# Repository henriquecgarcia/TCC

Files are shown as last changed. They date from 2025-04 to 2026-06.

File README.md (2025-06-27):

# Autonomous Car for Delivery
Final Course Project fo Computer Science at UNIFESP (Federal University of São Paulo).

## Project Details:
**Author**: Henrique Campanha Garcia
**Professor**: Dr. André Marcorin de Oliveira
**Course**: Computer Science
**University**: Federal University of São Paulo (UNIFESP)

## Description
This project is an autonomous car (drone) with the porpose of transporting packages from one place to another using a known map. The drone will be fully autonomous, using an ESP32, a motor driver, 4 motors, a battery and some other sensors for minor systems. To operate the drone, you will connect on it's IP connection, select wherever you want it to go, put the package on top of the drone and press for it to go.

The drone also has some other sensors that will help on it's navigation and controling the location where it is and preventing it from colliding with things on it's way.

### How to use:
To use this project, you need to have the following libraries installed:
- `WiFi`
- `ESPAsyncWebServer` (From me-do-dev)
- `SPIFFS`
- `VL53L0x` (From Adafruit)
- `MPU6050` (From Adafruit)

## Components:
- ESP32
- Motor Driver
- 4 DC Motors (3-6v DC Motor)
- 2 Encoder (Q2-E2)
- Battery
- 1 VL53L0x
- 1 MPU6050 Acelerometer & Gyroscope

### ESP32
The ESP32 used is the ESP32 DOIT DEVKIT V1, which has a ESP-WROOM-32 module, which has a dual core processor, 4MB of flash memory, 520KB of SRAM, and a lot of other features.

### Motor Driver & DC Motors
The motor driver used is the L298N, which is a dual H-Bridge motor driver, which can control 2 motors at the same time, and can control the speed of the motors.
> Obs: In each side of the car, there are 2 motors, meaning the the Motor Driver is connected to 4 motors at once (2 in each side).

The motors used are 3-6v DC Motors, which are small and lightweight, and can be controlled by the motor driver to move the car forward, backwards and turn. In the bought motors, they already had a reductor, which allows the car to move at a constant speed and to have more torque, allowing it to carry a package on top of it.

### Battery
The battery used is a 7.4v LiPo battery, which is lightweight and has a high capacity, allowing the car to move for a long time without needing to be recharged.
> Obs: The battery is connected to the motor driver, which allows the car to move. And the Motor Driver sends 5v to the ESP32, but since it only has 3.3v logic, the ESP32 converts the 5v to 3.3v using the vin pin.

### Encoders E2-Q2
The encoders are mounted on the forward wheels and counting each change on the reflective sensors, allowing the ESP32 to count the number of "changes" on the sensors, therefore, knowing that the used reference wheel there is 10 teeth, and the actual wheel has 65 mm of diameter, we can calculate the distance traveled by the car in a second by using the formula:
```
Distance = ((Number of changes) / 2 * 65mm) / (10 * 2)
RPM = (Number of changes / interval) * 60
```
> The division by 2 is because the encoder has 2 channels, and we are only using one of them, so we need to divide the number of changes by 2 to get the actual number of changes on the wheel. The division by 10 * 2 (20) is because the encoder has 10 teeth, and we are using the number of changes to calculate the distance traveled by the car in a second, so we need to divide the number of changes by 20 to get the actual distance traveled by the car in a second.
> Obs: The interval used is of 100ms, meaning that the car will calculate the distance traveled by the car every 100ms, and the speed of the car will be calculated every second.

### VL53L0x
Using the time-of-flight sensor, the VL53L0x can measure distances up to 3 meters with high accuracy. It uses a laser to measure the time it takes for the light to bounce back from an object, allowing it to calculate the distance.
> In the project, the sensor is mounted infront, facing forward to the front, to avoid any collision while on the path to the destination.

### MPU6050 Acelerometer & Gyroscope
The MPU6050 is a 6-axis motion tracking device that combines a 3-axis gyroscope and a 3-axis accelerometer on a single chip. It can be used to measure the orientation and motion of the car, allowing for more advanced control and navigation.
The MPU6050 is connected to the ESP32 via I2C, and it is used to measure the orientation and motion of the car, allowing for more advanced control and navigation. The MPU6050 can be used to detect the direction of the car, and to control the speed of the motors, so the car can go straight and not turn while going forward/backwards.
> Obs: The MPU6050 also has a temperature sensor, but it is not used in this project.

---

## How it works:
**Some awsome remarks of the project will be here, but I don't want to write them now, so I will write them later.**

## Pinout
The pinout used in this project is the following:
- Motor Driver:
	- ENA: 32
	- INA1: 12
	- INA2: 13
	- INB1: 26
	- INB2: 25
	- ENB: 33
- Encoders:
	- Front-Right:
		- Channel A: 4
		- Channel B: 15
	- Front-Left:
		- Channel A: 17
		- Channel B: 16
- MPU6050 & VL53L0x:
	- Via I2C.
	- SDA: 21
	- SCL: 22

## Final remarks:
This project was started in the class of Internet of Things (IoT) at the Federal University of São Paulo (UNIFESP), by Henrique Campanha Garcia, under the supervision of Professor Dr. André Marcorin de Oliveira. The project was updated and made to be fully autonomous and to be able to move in a path that it would not deviate from the pathm and to change the object avoidance system to use a time-of-flight sensor instead of an ultrasonic sensor. The project had to have a few bunch of changes to work with the new components, have a PID controler to control the speed of the motors. Some of the motor control was maintained from the previous project, but the new components and the new control system made it necessary to change a lot of the code.
The project has a plan to scan the environment and to create a map of the environment, so the car can navigate through the environment and avoid obstacles. Ideally, when fully autonomous, the vehicle would save the map using the SPIFFS filesystem, and then use the map to navigate through the environment, avoiding "static" obstacles, like walls and furniture, but also avoiding "dynamic" obstacles, like people and animals.
The way that it was setup, the car uses the encoders and the MPU6050 to control the direction of the car, avoiding that the car turns while going forward or backwards, and using the VL53L0x to avoid collisions with objects in front of the car, stopping the car when it detects an object closer than 10cm.

---
---
# Old stuff
This is a project to build a remote controlled car using an ESP32, a motor driver, 4 motors, a battery and a remote control. The remote control used is a normal gamepad controller, but we will only be using the triggers and the left joystick, where the right trigger will be used to move the car forward, the left trigger will be used to move the car backwards, and the left joystick will be used to steer the car, though the car will only be able to do one of these actions at a time.

The car has also some other components, like a LDR to detect light, DHT11 to detect temperature and humidity, and a ultrasonic sensor to detect distance ahead of the car. It will send this data to a MQTT broker, so it can be accessed from anywhere.

The MQTT broker used is the Flespi MQTT broker, and when a button is pressed on the MQTT client, a LED on the car will light change simbolizing that there was a light turned on inside the greenhouse has been turned on or off.

## How to use
To use this project, you will need to have the following libraries installed:
- `WiFi`
- `PubSubClient`
- `Bluepad32` (Used for the controller)

# Components
- ESP32
- Motor Driver
- 4 CC Motors
- Battery
- Remote Control
- LDR
- DHT11
- 2 LEDs
- Ultrasonic Sensor (HC-SR04)

## ESP32
The ESP32 used is the ESP32 DOIT DEVKIT V1, which has a ESP-WROOM-32 module, which has a dual core processor, 4MB of flash memory, 520KB of SRAM, and a lot of other features.

## Motor Driver
The motor driver used is the L298N, which is a dual H-Bridge motor driver, which can control 2 motors at the same time, and can control the speed of the motors.
> Obs: In this project, the motor driver and the motors were already built in a car chassis, so I don't have the exact model of the motors used.

> Obs2: In each side of the car, there are 4 motors, meaning the the Motor Driver is connected to 4 motors at once (2 in each side).

## Battery
>> idk, need to check

## Remote Control
>> idk, need to check

## LDR
The LDR used is a simple LDR, which is used to detect light. When the light is on, the resistance of the LDR decreases, and when the light is off, the resistance increases.

## DHT11
The DHT11 is a sensor that can detect temperature and humidity. It is a simple sensor, and it is not very accurate, but it is good enough for this project.

## Ultrasonic Sensor
The ultrasonic sensor used is the HC-SR04, which can detect distance ahead of the car. It works by sending a sound wave, and then waiting for the sound wave to return. The time it takes for the sound wave to return is used to calculate the distance.
> Formula for calculating the distance: `distance = (time * speed of sound) / 2`

## MQTT
The MQTT broker used is the Flespi MQTT broker, which is a free MQTT broker that can be used for testing purposes. It is a cloud based MQTT broker, and it is very easy to use.

---
# How it works
The ESP32 is the main component of the car, and it is responsible for controlling the car, and sending data to the MQTT broker.

The car can be controlled using the remote control, which is connected to the ESP32 via Bluepad32 (Bluetooth). On the controller, when it's pressed the right trigger, the car will move forward, when it's pressed the left trigger, the car will move backwards, and when the left joystick is moved, the car will turn.

While the car is moving, the LDR will detect the light, and the DHT11 will detect the temperature and humidity. Every 0.5 seconds, the ESP32 will send this data to the MQTT broker, so it can be accessed from anywhere.
> Reason for the time: So it does not overload the MQTT broker with data.

The ultrasonic sensor is used to detect distance ahead of the car, and when the distance is less than 10cm, the car will stop moving forward and will only allow the car to move backwards or turn.

Whenever the LDR detects low light, the ESP32 will send a message to the MQTT broker, and a LED on the car will light up. When the LDR detects high light, the ESP32 will send another message to the MQTT broker, and the LED will turn off.

On the MQTT viewer, there will be 2 main buttons, one to turn on or off the light inside the greenhouse, and another to turn on or off the light on the car. When the button to turn on or off the light inside the greenhouse is pressed, a LED added on the ESP32 protoboard will light up or turn off, simbolizing that the light inside the greenhouse has been turned on or off. Same thing happens when the button to turn on or off the light on the car is pressed.

## Pinout
The pinout used in this project is the following:
- Motor Driver:
	- ENA: not used
	- IN1: 25
	- IN2: 33
	- IN3: 32
	- IN4: 14
	- ENB: not used
- LDR: 34
- DHT11: 35
- Ultrasonic Sensor:
	- Trig: 26
	- Echo: 27
- LEDs:
	- Green: 2
	- Red: 4

## MQTT Topics
For MQTT topics, the following topics are used, all of them starting with `/Henrique/IoT/TF`:
- `/Henrique/IoT/TF/LDR`: Used to send the LDR data
- `/Henrique/IoT/TF/DHT/Temperature`: Used to send the temperature data
- `/Henrique/IoT/TF/DHT/Humidity`: Used to send the humidity data
- `/Henrique/IoT/TF/LED_CARRO`: Used to turn on or off the light on the car (The car will not publish to this topic, only subscribe)
- `/Henrique/IoT/TF/LED_ESTUFA`: Used to turn on or off the light inside the greenhouse

## MQTT Buttons
Within the MQTT, there are 2 buttons, one to turn on or off the light inside the greenhouse, and another to turn on or off the light on the car. Furthermore, there is a view section where the data from the LDR can be seen, and two sections where the temperature and humidity data can be seen.

Topics for the buttons:
- `/Henrique/IoT/TF/LED_CARRO`: Used to turn on or off the light on the car
- `/Henrique/IoT/TF/LED_ESTUFA`: Used to turn on or off the light inside the greenhouse

---

# Final remarks:
This project was made for the IoT class at the Federal University of São Paulo (UNIFESP), it was made by Henrique Campanha Garcia, using Visual Studio Code programming in Arduino, compiling using the Arduino IDE.

For the network connection, it was used my personal hotspot, witch has a meme ssid and password. The MQTT Broker used was the Flespi MQTT Broker and it's login will be changed after the project is finished.

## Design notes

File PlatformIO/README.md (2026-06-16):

# Proximos passos sugeridos:
> Fonte: Google Gemini Pro, gema customizada para o projeto e com conhecimento atualizado até março de 2026. (Commit anterior a este)

## 1. Sistema de Energia e Estabilidade
Segundo, o Professor:
> Item resolvido com a troca da corrente utilizada para alimentar os sensores do 3.3V do ESP32 para 5V, direto da Ponte H, nos testes iniciais funcionou bem, mas é importante monitorar a tensão da bateria durante o uso para garantir que não haja quedas que possam causar instabilidade ou resets do ESP32.
* Verificar a tensão da bateria sem carga e com carga.
* Verificar o uso de duas baterias (implementar um regulador de tensão).

Segundo a LLM:
* **Hardware:** Utilizar um circuito isolado: manter a potência bruta das baterias (ex: LiPo 7.4V) direto para a Ponte H e adicionar um regulador Step-Down (ex: LM2596) cravado em 5V exclusivo para o ESP32, evitando *brownouts*.
* **Firmware:** Implementar um divisor de tensão lido por um pino analógico (ADC) do ESP32 para monitorar a tensão em tempo real e criar uma trava de segurança (desligar motores se a bateria ficar muito baixa).
* **Texto Acadêmico:** Criar a seção "Dimensionamento Energético e Isolamento de Ruídos", incluindo o esquemático elétrico do divisor de tensão e do regulador, justificando a separação lógica/potência para estabilidade do sistema.

## 2. Controle das Rodas (PID) e Odometria
Segundo, o Professor:
* Colocar a roda boba (diminui a incerteza dos outros motores).
	- Eu: Uma ideia interessante, porém com a nova estabilidade após arrumar o item #1, pode ser que isso não seja mais necessário. Vale a pena testar o carrinho com as rodas atuais e verificar se a estabilidade é suficiente para o controle preciso.
* Tirar o PID, aplicar PWMs iguais, medir rotação na porta Serial e escolher motores parecidos.
	- Eu: Acho interessante para fazer os testes com os motores atuais, para entender o comportamento do sistema. Se os motores forem muito diferentes, pode ser necessário ajustar o PID ou considerar a substituição de um dos motores para garantir melhor desempenho.
* Regular os ganhos do PID e verificar o resultado final.
	- Eu: Acho que é importante fazer uma análise detalhada do comportamento do carrinho com os ajustes atuais, antes de decidir sobre a necessidade de uma roda boba ou substituição de motores. Se o controle PID estiver funcionando bem e o carrinho for estável, pode ser que não seja necessário fazer mudanças drásticas.
* Avaliar o uso de um Magnetômetro.
	- Eu: Realmente melhoraria a precisão da odometria, especialmente para correção de deriva. Vale a pena considerar a adição de um magnetômetro para complementar os dados do IMU e melhorar a navegação.

Segundo a LLM:
* **Hardware:** A instalação da roda boba (*caster wheel*) é mandatória para evitar o arraste do eixo traseiro, que gera um atrito não-linear imprevisível para o PID.
	- Eu: Mesma coisa que disse antes.
* **Firmware:** Criar um script temporário em malha aberta para aplicar degraus de PWM, exportar os logs da Serial para Excel/Python e aplicar um "fator de correção" no PWM base antes mesmo do PID atuar, compensando as assimetrias mecânicas.
	- Eu: Estudo mais que válido para entender o comportamento dos motores e ajustar o sistema, mas... Vamos ver...
* **Firmware (PID):** Garantir que o PID rode a uma frequência de amostragem perfeitamente cravada (ex: usando interrupção de hardware ou *Task* fixada em um *Core* pelo FreeRTOS a 50Hz) e habilitar a proteção *Anti-Windup*.
	- Eu: Não entendi nada disso... Verificar com Marcorin.
* **Sensores:** O magnetômetro deve ser usado como filtro complementar ao giroscópio (QMC5883L) para anular o *drift* (desvio acumulado) no eixo Z ao longo do tempo.
	- Eu: Mas o magnetômetro não seria um substituto para o giroscópio? | Verificar...
* **Texto Acadêmico:** Adicionar seção "Sintonia do Controlador PID", exibindo os gráficos do ensaio de malha aberta e o gráfico "antes vs depois" do controle em malha fechada demonstrando a redução do erro.
	- Eu: Soon (TM).

## 3. Comandos de Navegação de Alto Nível
Segundo, o Professor:
* Virar 90 graus a direção (direita).
	- Eu: Com os ajustes de estabilidade e controle, o carrinho deve ser capaz de realizar giros precisos. Ajustes devem ser feitos para garantir que o giro seja de apenas 90 graus, sem overshoot ou undershoot.
* Virar 90 graus para esquerda.
	- Eu: Com os ajustes de estabilidade e controle, o carrinho deve ser capaz de realizar giros precisos. Ajustes devem ser feitos para garantir que o giro seja de apenas 90 graus, sem overshoot ou undershoot.
* Andar X.
	- Eu: Odometria...
* Voltar X.
	- Eu: Odometria...

Segundo a LLM:
* **Firmware (Arquitetura):** Abstrair esses movimentos através de uma Máquina de Estados Finitos (FSM).
	- Eu: Tf this be?
* **Firmware (Rotação):** Criar a função `virar_angulo(float angulo)` que lê continuamente o integrador do giroscópio (eixo Z) e, ao atingir o alvo (ex: 90º), aplica um freio reverso momentâneo nos motores para zerar a inércia.
	- Eu: Potencia muito fraca pra precisar do freio reverso, mas a função é essencial para o controle de orientação.
* **Firmware (Translação):** Criar a função `andar_distancia(float cm)` que converte o raio da roda em "ticks de encoder por centímetro" e alimenta o *setpoint* do PID até o alvo ser alcançado.
	- Eu: Odometria... + Mapas e Trajetória...
* **Texto Acadêmico:** Desenhar a Máquina de Estados em LaTeX e apresentar as equações de Cinemática Direta do robô diferencial (relacionando a rotação das rodas com a velocidade linear do centro do robô).
	- Eu: Sure? Soon (TM).

## 4. Mapa, Trajetória e Localização
Segundo, o Professor:
* Ir do ponto A ao ponto B.
	- Eu: Fazer um algoritimo que controla o mapa, a trajetória e a localização do carrinho. Ideal: bitmaps para o mapa, A* para a trajetória e correção de localização com as faixas no chão.
* Fazer a localização simultânea no mapa em grid.
	- Eu: Fazer o algoritimo a cima + Odometria
* Usar faixas no chão?
	- Eu: Acho que perde um pouco da ideia de 100% autônomo, mas é uma solução prática e eficaz para o ambiente de teste. As faixas no chão funcionariam como "marcos" para correção de posição, permitindo que o carrinho se localize com mais precisão e compense os erros acumulados pela odometria.
* Chegar ao destino B com o mínimo erro de localização possível.
	- Eu: A combinação de um mapa em grid, o algoritmo A* para planejamento de trajetória.

Segundo a LLM:
* **Firmware (Algoritmo):** Implementar o mapa como uma matriz 2D embarcada (`int map[10][10]`) e utilizar o algoritmo A* (A-Star) para calcular a rota mais curta em grid.
	- Eu: A* é o algoritmo clássico para esse tipo de problema, mas... Será que o ESP32 aguenta? Vamos ver...
* **Hardware/Navegação:** A ideia do professor das faixas no chão é excelente. Instalar sensores reflexivos (como TCRT5000) apontados para o chão. Isso substitui um SLAM complexo e pesado por "Localização Topológica".
	- Eu: Avaliar... Mas como disse antes... Perde a ideia de ser 100% autônomo...
* **Firmware (Correção):** Toda vez que o robô cruza uma fita preta no chão, o software força a atualização da sua posição na matriz e "zera" a incerteza acumulada pela odometria morta (*dead reckoning*).
* **Texto Acadêmico:** Escrever um capítulo "Planejamento de Trajetória e Correção Odometrica", defendendo teoricamente por que a navegação puramente baseada nos encoders falha com o tempo (derrapagens/folgas) e justificando o uso de marcos fixos (faixas) para robustez no ambiente de teste.
	- Eu: Soon (TM).

## Navegação por células de 30 cm x 30 cm

Esta versão adiciona um comando de navegação discreta para o TCC: **"Vá X células para frente"**.
Cada célula representa **30 cm x 30 cm** no mundo real.

### Como funciona

O robô não tenta andar todas as células em um único movimento contínuo. Ele executa uma máquina de estados não bloqueante:

1. Registra a pose inicial da célula atual pelo `PoseEKF`.
2. Anda para frente até completar aproximadamente `0,30 m`.
3. Para os motores.
4. Aguarda uma pequena estabilização mecânica e de leitura.
5. Mede o erro de angulação em relação ao heading inicial do comando.
6. Corrige a angulação com uma curva curta, caso o erro seja maior que 2 graus.
7. Repete o ciclo até completar a quantidade solicitada.

Esse comportamento facilita validação experimental, logs por célula, futura integração com mapa ocupacional e controle mais estável para navegação em grade.

### Comandos aceitos

Via WebSocket do carro, é possível usar texto:

```text
vá 3 células para frente
va 3 celulas para frente
3 celulas para frente
```

Ou JSON:

```json
{"action":"forward_cells","cells":3}
```

Também é aceito:

```json
{"action":"go_cells_forward","cells":3}
```

### Telemetria adicionada

A telemetria passa a incluir o objeto `cell_nav`:

```json
{
  "cell_nav": {
    "state": "moving_cell",
    "active": true,
    "requested": 3,
    "completed": 1,
    "cell_size_cm": 50
  }
}
```

### Próximos passos sugeridos para o TCC

1. **Calibração experimental da célula de 30 cm**: medir o erro médio real em 10, 20 e 30 execuções e ajustar `CELL_TARGET_TOLERANCE_M`, PID dos motores e ruídos do EKF.
2. **Validação de odometria por encoder**: registrar ticks por célula em linha reta para verificar se o raio da roda, base entre rodas e `encoderTicksPerRev` estão coerentes.
3. **Correção angular mais robusta**: substituir a correção por curva relativa simples por um controlador de heading contínuo durante o avanço da célula.
4. **Registro de trajetória por célula**: salvar em SPIFFS/CSV a célula inicial, célula final, erro linear, erro angular e leitura do VL53L0X.
5. **Integração com A\***: transformar cada comando de avanço em um passo de execução de rota, usando a mesma lógica de parar, corrigir e avançar para a próxima célula.
6. **Detecção dinâmica de obstáculo**: quando o VL53L0X parar o robô antes de completar a célula, marcar a próxima célula como ocupada no `Map` e recalcular rota.
7. **Dashboard de TCC**: exibir na Web UI a célula atual, células solicitadas/concluídas, erro angular e estado da máquina de navegação.

---

## Versão TCC — implementação dos itens 3, 4, 6, 8, 9, 11 e 12

Esta versão implementa as próximas etapas solicitadas para evolução do TCC.

### 3. PID angular contínuo durante cada célula

Durante o estado `moving_cell`, o `GridCellNavigator` calcula continuamente:

```cpp
headingError = poseEKF->getTheta() - targetHeadingRad;
```

Esse erro é enviado para a `PonteH` por:

```cpp
ponte->setExternalHeadingError(headingError);
```

A `PonteH` aplica o PID `pidCellHeading` de forma diferencial nos motores, reduzindo o desvio antes de chegar ao final da célula. A correção residual ao final da célula continua existindo como segunda camada de precisão.

### 4. Logs experimentais em CSV

Foi adicionada a classe:

```txt
lib/ExperimentLogger/
```

Ela grava o arquivo:

```txt
/tcc_experiment_log.csv
```

Download pela interface HTTP:

```txt
/api/tcc-log.csv
```

Limpeza do log:

```txt
POST /api/tcc-log/clear
```

Comandos WebSocket:

```json
{"action":"experiment_log","mode":"enable"}
{"action":"experiment_log","mode":"disable"}
{"action":"experiment_log","mode":"clear"}
```

O CSV registra eventos, pose, erro angular, célula atual, distância frontal, modo A*, replanejamento e progresso da navegação.

### 6. Ensaios formais para a monografia

Foi criado o arquivo:

```txt
EXPERIMENTS.md
```

Ele descreve ensaios de:

- deslocamento por célula;
- erro angular;
- execução de caminho A*;
- obstáculo dinâmico e replanejamento.

### 8. Detecção de obstáculo e atualização do mapa

Durante `moving_cell`, o VL53L0X é lido continuamente. Caso a distância frontal seja menor ou igual a:

```cpp
FRONT_OBSTACLE_REPLAN_MM = 220;
```

O robô:

1. para os motores;
2. identifica a célula à frente pelo heading atual;
3. marca a célula como ocupada no bitmap do `Map`;
4. publica evento WebSocket;
5. registra o evento no CSV.

### 9. Replanejamento automático

O comando `path_to` agora pode executar automaticamente o caminho planejado:

```json
{"action":"path_to","x":8,"y":4,"execute":true}
```

Durante a execução, se um obstáculo for detectado, o sistema tenta recalcular o caminho até o alvo final usando o mapa atualizado.

Para apenas calcular sem executar:

```json
{"action":"path_to","x":8,"y":4,"execute":false}
```

### 11. Organização da arquitetura

Foi criada a documentação:

```txt
ARCHITECTURE.md
```

A nova classe `ExperimentLogger` já está em `lib/`, seguindo a arquitetura modular do PlatformIO. O `GridCellNavigator` ainda permanece em `src/carrinho.ino` porque depende diretamente da `PonteH`, que também está no arquivo principal. A próxima refatoração segura é mover `PonteH` para `lib/DriveBase/` e depois mover `GridCellNavigator` para `lib/Navigator/`.

### 12. Documentação adicionada

Novos documentos:

```txt
INSTALL.md
PINOUTS.md
CALIBRATION.md
EXPERIMENTS.md
ARCHITECTURE.md
RESULTS.md
```

Esses arquivos ajudam a transformar o projeto em um pacote defendível academicamente: instalação, pinagem, calibração, metodologia de testes, arquitetura e registro de resultados.

## Mapa binário 7x7

O projeto agora inicializa um mapa binário 7x7 para os testes do TCC:

```txt
1111111
1000001
1000001
1000001
1000001
1000001
1111111
```

O robô começa na célula `(1,1)`. A célula `(0,0)` é o canto superior esquerdo da matriz e faz parte da borda ocupada. Cada célula mede 30 cm x 30 cm.

Para mandar o robô andar usando o planejador A*, envie pelo WebSocket:

```json
{"action":"path_to","x":5,"y":5,"execute":true}
```

Para andar manualmente por células:

```json
{"action":"forward_cells","cells":3}
```

A telemetria WebSocket possui `pose` para posição contínua em metros e `location` para posição discreta no mapa.

## Correção de navegação por múltiplas células

Esta versão corrige um problema observado em testes físicos: após andar uma célula, o robô podia ficar parado, acumular drift de localização e depois se perder ou iniciar correções angulares excessivas.

Correções aplicadas:

- Leitura do QMC5883L em thread FreeRTOS própria.
- Leitura do VL53L0X em thread FreeRTOS própria.
- Cache thread-safe para sensores.
- Travamento da pose quando a PonteH está parada.
- Snap da pose para a célula discreta esperada ao fim de cada célula.
- Redução do intervalo de controle dos motores para 100 ms.
- A Web UI agora recebe `sensor_age.mag_ms` e `sensor_age.tof_ms` para diagnosticar atraso nas leituras.

Teste recomendado:

1. Envie `{"action":"forward_cells","cells":1}` e confirme que a posição para exatamente na próxima célula.
2. Aguarde 30 segundos sem enviar comandos e verifique se `location.grid_x`, `location.grid_y`, `world_x_m`, `world_y_m` e `theta_rad` não derivam.
3. Envie `{"action":"forward_cells","cells":3}` e verifique se ele executa uma célula por vez sem iniciar giro contínuo.

## Atualização: UI moderna e ré em caminho A*

Esta versão substitui o painel principal `dashboard.html/css/js` por uma interface moderna, sem tema LCARS/Star Trek. O comando de avanço direto da UI agora é **Vá 1 célula para frente**, usando o comando seguro por célula:

```json
{"action":"forward_cells","cells":1}
```

O algoritmo de execução de caminho A* também foi ajustado: quando o próximo passo planejado está diretamente atrás do robô, o navegador não executa giro de 180°. Ele mantém o heading atual e percorre a célula **dando ré**. Isso reduz giros desnecessários e melhora a estabilidade em mapas pequenos.

Também foi adicionada uma camada de ticks assinados para o EKF. Como os encoders contam pulsos absolutos, o firmware agora aplica o sinal correto conforme o movimento comandado:

- frente: esquerdo `+`, direito `+`;
- ré: esquerdo `-`, direito `-`;
- giro esquerda: esquerdo `+`, direito `-`;
- giro direita: esquerdo `-`, direito `+`.

Isso impede que o EKF interprete um movimento de ré como avanço para frente.

## Atualização da interface Web

A dashboard principal em `/` foi substituída por uma UI moderna, clara e responsiva.

Correções aplicadas nesta revisão:

- a página não depende mais de `dashboard.css` e `dashboard.js` externos; CSS e JavaScript foram embutidos no próprio `dashboard.html`, evitando tela quebrada quando o ESP32 não serve arquivos estáticos;
- removido visual escuro/LCARS/Star Trek;
- reduzido o título gigante que ocupava a tela;
- os controles foram reorganizados em cards;
- o comando principal continua sendo apenas `Vá 1 célula para frente`;
- o mapa 7x7 agora aparece em um painel centralizado, com legenda e células arredondadas.

Depois de gravar o firmware, envie novamente os arquivos da pasta `data/` para o SPIFFS/LittleFS. No PlatformIO, use:

```bash
pio run -t uploadfs
```

## Ajuste de giro após testes físicos

Nos testes reais, foi identificado que o carrinho estava girando aproximadamente o dobro do ângulo solicitado. Para estabilizar a execução, a PonteH agora aplica `TURN_ENCODER_SCALE = 0.50` sobre o alvo interno de giro. Assim, os comandos de alto nível continuam usando 90°, 45° etc., mas a estimativa angular por encoder é multiplicada pela escala antes de decidir a parada.

Esse ajuste fica em `src/carrinho.ino` e pode ser recalibrado em incrementos pequenos, por exemplo `0.45`, `0.50`, `0.55`.

## Correções pós-log de 2026-05-28

Esta revisão corrige os problemas observados no log de teste:

- giro à esquerda acumulando ângulo negativo e aumentando o erro até timeout;
- primeira célula registrando distância absurda, como 1,226 m para alvo de 0,30 m;
- pose/célula do mapa sendo atualizada no meio da célula por ruído do EKF;
- falta de proteção quando a distância medida da célula passa muito do alvo esperado.

As principais constantes ficam em `src/carrinho.ino`:

```cpp
GYRO_Z_LEFT_TURN_SIGN
GYRO_Z_RIGHT_TURN_SIGN
CELL_OVERRUN_ABORT_FACTOR
ODOM_WHEEL_RADIUS_M
ODOM_TICKS_PER_REV
```

Para validar, faça primeiro testes isolados:

1. `{"action":"forward_cells","cells":1}` — deve registrar aproximadamente `0.30 m`.
2. `left` ou `right` — o `Turning Angle Z` deve crescer positivo até o alvo interno, sem ficar negativo.
3. `{"action":"path_to","x":5,"y":5,"execute":true}` — o caminho não deve mais entrar em timeout de giro repetidamente.

## QMC5883L integrado ao firmware

O firmware agora usa um driver simples para QMC5883L baseado no código de teste com registradores explícitos:

- endereço principal: `0x2C`;
- fallback automático: `0x0D`;
- configuração: `0x1D` no registrador `0x09`;
- OSR 512, range 8G, ODR 200 Hz e modo contínuo;
- conversão raw → Gauss com `3000 LSB/Gauss`;
- heading calculado por `atan2(yGauss, xGauss)`.

Comandos úteis:

```json
{"action":"qmc_zero","mode":"current"}
```

```json
{"action":"qmc_config","declination_deg":0.0}
```

```json
{"action":"qmc_config","offset_x":0,"offset_y":0,"offset_z":0}
```

Pelo monitor:

```txt
qmc_scan
```

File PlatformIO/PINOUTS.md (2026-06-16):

# PINOUTS.md — Pinagem atual do projeto

## ESP32 DOIT DevKit V1

## I2C

| Sinal | GPIO |
|---|---:|
| SDA | 21 |
| SCL | 22 |

Sensores no barramento:

- QMC5883L;
- VL53L0X.

## Motores — L298N

### Motor direito

| Função | GPIO |
|---|---:|
| IN1 | 14 |
| IN2 | 12 |
| PWM | 13 |
| Canal LEDC | 0 |

### Motor esquerdo

| Função | GPIO |
|---|---:|
| IN1 | 26 |
| IN2 | 27 |
| PWM | 25 |
| Canal LEDC | 1 |

## Encoders

### Encoder direito

| Canal | GPIO |
|---|---:|
| A | 39 |
| B | 36 |

### Encoder esquerdo

| Canal | GPIO |
|---|---:|
| A | 34 |
| B | 35 |

## LED

| Função | GPIO |
|---|---:|
| LED carroceria/status | 2 |

## Observações

- GPIOs 34, 35, 36 e 39 são somente entrada no ESP32.
- Confirme alimentação externa dos motores; não alimente motores pelo 5V do ESP32.
- Mantenha GND comum entre ESP32, L298N e sensores.

## QMC5883L

```txt
VCC -> 5V
GND -> GND comum
SDA -> GPIO 21
SCL -> GPIO 22
```

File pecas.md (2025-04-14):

# Peças para o projeto:

## Itens principais:
### Produtos pelo Mercado Livre
1. [Motor DC 3-6v](https://produto.mercadolivre.com.br/MLB-4514876396-kit-com-2-pecas-motor-dc-3-6v-com-caixa-de-reduco-e-rodas-_JM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) - R$ 27,59 {Combo com 2 motores e rodas}
 - [4 motores e roda](https://www.mercadolivre.com.br/04-roda-pneu-motor-dc-3-a-6v-robotica-arduino-carro/p/MLB39116383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)

2. [Ponte H](https://www.mercadolivre.com.br/driver-motor-ponte-h-l298n-l298/p/MLB38897368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) - R$ 26,99

3. [Encoder E2-Q2](https://produto.mercadolivre.com.br/MLB-1744919291-encoder-e2-q2-para-motor-3-6v-com-reduco-_JM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) - R$ 49,00 - Precisaria de 2 deles

- Total: 27,59x2 + 26,99 + 49,00x2 = R$ 179,17 [!PARCIAL]

### Pela Robocore
1. [Motor DC 3-6v](https://www.robocore.net/motor-motoredutor/motor-dc-3-6v-com-caixa-de-reducao-e-eixo-duplo) - R$ 7,50 (1 unidade) - Precisaria de 4 deles
2. [Rodas](https://www.robocore.net/roda/roda-hobby-65mm) - R$ 8,07 (1 unidade) - Precisaria de 4 delas
3. [Encoder E2-Q2](https://www.robocore.net/sensor-robo/encoder-e2-q2) - R$ 37,90 (1 unidade) - Precisaria de 2 deles
4. [Ponte H](https://www.robocore.net/driver-motor/driver-motor-ponte-h-l298n) - R$ 14,15 (1 unidade) - Precisaria de 1 deles

- Total: 7,50x4 + 8,07x4 + 37,90x2 + 14,15 = R$ 119,98 [!PARCIAL]

## Pre-prontos:
### Carro Chassi:
- Sem Ponte H
- Sem Encoder
  - Sem Bateria
1. [Mercado Livre](https://produto.mercadolivre.com.br/MLB-1420987890-kit-chassi-duplo-4wd-robotica-carro-rob-rodas-motores-_JM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) - R$ 126,91 - Final: 126,91 + 14,15 + 37,90x2 + 181,49 = R$ 400,35
2. [Robocore](https://www.robocore.net/kit-plataforma-robotica/kit-chassi-4wd-com-motores-e-rodas) - R$ 89,90 - Valor final: 89,90 + 14,15 + 37,90x2 + 181,49 = R$ 381,34

## Itens adicionais:
1. [Bateria (11.1v) + Carregador](https://produto.mercadolivre.com.br/MLB-4666561840-kit-bateria-de-lipo-111v-1100-mah-3s-carregador-leo-_JM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) - R$ 181,49

## Dimensões:
- Sensor de Refletância QRE - 0.6inch x 0.3inch (1.5cm x 0.8cm)
- Motor DC 3-6v - 70 mm x 37 mm x 23 mm
- Roda - 66 mm de diâmetro, 26 mm de largura só a roda e 31 mm de largura com o cubo do eixo
- Ponte H - 43 mm x 43 mm x 27 mm
- Encoder E2-Q2 - 36.5 mm x 22.5 mm -- Vai junto ao motor

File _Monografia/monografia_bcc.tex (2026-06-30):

\documentclass[	12pt, Times, openright, twoside, a4paper, english, brazil]{abntex2}

% ---
% Pacotes fundamentais 
% ---
\usepackage{cmap}				% Mapear caracteres especiais no PDF
%\usepackage{lmodern}			% Usa a fonte Latin Modern			
\usepackage{times}
\usepackage[T1]{fontenc}			% Selecao de codigos de fonte.
\usepackage[utf8]{inputenc}		% Codificacao do documento (conversão automática dos acentos)
\usepackage{lastpage}			% Usado pela Ficha catalográfica
% \usepackage{natbib}
%\usepackage{hyperref}
%\usepackage{indentfirst}			% Indenta o primeiro parágrafo de cada seção.
\usepackage{color}				% Controle das cores
\usepackage{graphicx}			% Inclusão de gráficos

\usepackage{xspace}
\usepackage{setspace}
\usepackage[verbose,a4paper,left=23mm,right=23mm,top=30mm,bottom=23mm]{geometry}
\usepackage{amssymb}
\usepackage{amsmath,amsthm}
\usepackage{url}
\usepackage{fancyvrb}
\usepackage{acronym}
\usepackage{fancyhdr}
\usepackage{algorithm}
\usepackage{algorithmic}
\usepackage{colortbl}
\usepackage{subcaption}
\usepackage{float}

% ---

% ---
% \usepack
% Pacotes de citações
% ---age[brazilian,hyperpageref]{backref}	% Paginas com as citações na bibl
\usepackage[alf]{abntex2cite}	% Citações padrão ABNT
\usepackage{hyperref}

% --- 
% CONFIGURAÇÕES DE PACOTES
% --- 

% % ---
% % Configurações do pacote backref
% % Usado sem a opção hyperpageref de backref
% \renewcommand{\backrefpagesname}{Citado na(s) página(s):~}
% % Texto padrão antes do número das páginas
% \renewcommand{\backref}{}
% % Define os textos da citação
% \renewcommand*{\backrefalt}[4]{
% 	\ifcase #1 %
% 		Nenhuma citação no texto.%
% 	\or
% 		Citado na página #2.%
% 	\else
% 		Citado #1 vezes nas páginas #2.%
% 	\fi}%
% % ---

% numeração de figuras e tabelas 
\counterwithout{figure}{section}
\counterwithout{table}{section}

%\renewcommand\tablename{Tabela{\arabic{chapter}.}}

% ---
% Informações de dados para CAPA e FOLHA DE ROSTO
% ---
\titulo{Desenvolvimento de um Veículo Robótico Autônomo de Pequeno Porte Baseado em ESP32}
\autor{Henrique Campanha Garcia}
\local{São José dos Campos, SP}
\data{Junho de 2026}
\orientador{Prof. Dr. André Marcorin de Oliveira}
% \coorientador{Prof. Dr. Beltrano da Silva}
\instituicao{%
	Universidade Federal de São Paulo -- UNIFESP
	\par
	Instituto de Ciência de Tecnologia
	\par
	Bacharelado em Ciência da Computação}
\tipotrabalho{Trabalho de Graduação}
% O preambulo deve conter o tipo do trabalho, o objetivo, 
% o nome da instituição e a área de concentração 
\preambulo{Trabalho de conclusão de curso apresentado ao Instituto de Ciência e Tecnologia – UNIFESP, como parte das atividades para obtenção do título de Bacharel em Ciência da Computação.}
% ---

% informações do PDF
\makeatletter
\hypersetup{
		%pagebackref=true,
		pdftitle={\@title}, 
		pdfauthor={\@author},
		pdfsubject={\imprimirpreambulo},
		pdfcreator={LaTeX with abnTeX2},
		pdfkeywords={abnt}{latex}{abntex}{abntex2}{trabalho acadêmico}, 
		colorlinks=true,				% false: boxed links; true: colored links
		linkcolor=blue,				% color of internal links
		citecolor=blue,				% color of links to bibliography
		filecolor=magenta,				% color of file links
		urlcolor=blue,
		bookmarksdepth=4
}

\makeatother
% --- 
% --- 
% Espaçamentos entre linhas e parágrafos 
% --- 
% O tamanho do parágrafo é dado por:
\setlength{\parindent}{1.3cm}
% Controle do espaçamento entre um parágrafo e outro:
\setlength{\parskip}{0.2cm}	% tente também \onelineskip
% ---

% compila o indice
% ---
\makeindex
% ---

% ----
% Início do documento
% ----
\begin{document}
% Retira espaço extra obsoleto entre as frases.
\frenchspacing 

% ----------------------------------------------------------
% ELEMENTOS PRÉ-TEXTUAIS
% ----------------------------------------------------------
% \pretextual

% ---
% Capa
% ---
\begin{capa}
	\begin{center}
	
	\vspace*{\fill}
	
	{\ABNTEXchapterfont\large\imprimirautor}
	\vspace*{\fill}
	
	{\ABNTEXchapterfont\bfseries\Large\imprimirtitulo}
	\vspace*{\fill}\vspace*{\fill}
	
	\imprimirlocal
	\end{center}
\end{capa}

% ---
% Folha de rosto
% (o * indica que haverá a ficha bibliográfica)
% ---
\imprimirfolhaderosto*
% ---

% ---
% Inserir folha de aprovação
% ---
% Isto é um exemplo de Folha de aprovação, elemento obrigatório da NBR
% 14724/2011 (seção 4.2.1.3). Você pode utilizar este modelo até a aprovação
% do trabalho. Após isso, substitua todo o conteúdo deste arquivo por uma
% imagem da página assinada pela banca com o comando abaixo:
%
% \includepdf{folhadeaprovacao_final.pdf}
%
\begin{folhadeaprovacao}
	\begin{center}
		{\ABNTEXchapterfont\large\imprimirautor}

		\vspace*{\fill}\vspace*{\fill}
		{\ABNTEXchapterfont\bfseries\Large\imprimirtitulo}
		\vspace*{\fill}
		
		\hspace{.45\textwidth}
		\begin{minipage}{.5\textwidth}
			\imprimirpreambulo
		\end{minipage}%
		\vspace*{\fill}
	\end{center}
	
	% Trabalho aprovado em 01 de Julho de 2013:

	\assinatura{\textbf{\imprimirorientador} \\ Orientador} 
	\assinatura{\textbf{Prof. Dr. Sérgio Ronaldo Barros dos Santos} \\ Convidado 1}
	\assinatura{\textbf{Profª. Dra. Fernanda Quelho Rossi} \\ Convidado 2}
	%\assinatura{\textbf{Professor} \\ Convidado 3}
	%\assinatura{\textbf{Professor} \\ Convidado 4}
		
	\begin{center}
		\vspace*{0.5cm}
		{\large\imprimirlocal}
		\par
		{\large\imprimirdata}
		\vspace*{1cm}
	\end{center}
\end{folhadeaprovacao}
% ---

% ---
% Dedicatória
% ---
\begin{dedicatoria}
	\vspace*{\fill}
	\centering
	\noindent
	Dedico este trabalho ao meu orientador, cuja orientação foi essencial para o desenvolvimento deste projeto. 

	Seus esclarecimentos, especialmente na compreensão e aplicação dos algoritmos envolvidos, foram fundamentais para que eu pudesse superar desafios técnicos e aprofundar meus conhecimentos em áreas que antes me pareciam complexas.

	Agradeço pela paciência, disponibilidade e incentivo contínuo ao longo deste processo.

	Dedico este trabalho também a todos que, de alguma forma contribuíram para a realização deste projeto.
	
	\textit{Muito obrigado.}
	
	\vspace*{\fill}
\end{dedicatoria}
% ---

% ---
% Agradecimentos
% ---
\begin{agradecimentos}

A realização deste trabalho foi possível graças ao apoio e à colaboração de diversas pessoas e instituições, às quais expresso minha sincera gratidão.

Em primeiro lugar, agradeço ao meu orientador, \imprimirorientador, pelo constante apoio, paciência e pelas valiosas orientações técnicas, especialmente no que diz respeito à compreensão e à implementação dos algoritmos utilizados neste projeto. Sua experiência, dedicação e disponibilidade foram fundamentais para o desenvolvimento desta pesquisa.

Estendo meus agradecimentos à Universidade Federal de São Paulo (UNIFESP), instituição de ensino reconhecida pela excelência acadêmica, pelo compromisso com a formação de profissionais éticos, críticos e preparados para os desafios da sociedade contemporânea.

Agradeço especialmente aos técnicos dos laboratórios que me auxiliaram ao longo de grande parte deste projeto. O suporte oferecido durante a montagem, a realização dos testes, a identificação de problemas e os ajustes dos componentes foi essencial para o desenvolvimento do protótipo. A disponibilidade, a experiência prática e a disposição em compartilhar conhecimentos contribuíram de forma significativa para superar dificuldades técnicas e transformar as etapas de planejamento em uma implementação funcional.

Aos colegas e amigos que me acompanharam ao longo da graduação, em especial Thiago Capuano, sou grato pelos diálogos construtivos, pela colaboração espontânea e, sobretudo, pela amizade que tornou essa caminhada mais leve e motivadora.

À minha família, em especial aos meus pais, Margarete e Renato Garcia, agradeço pelo amor incondicional, incentivo constante e por acreditarem em mim mesmo diante das dificuldades. Sem o apoio de vocês, este trabalho certamente não teria se concretizado.

Por fim, agradeço a todos aqueles que, direta ou indiretamente, contribuíram para a realização deste projeto.

\end{agradecimentos}
% ---

% ---
% Epígrafe
% ---
\begin{epigrafe}
	\vspace*{\fill}
	\begin{flushright}
		\textit{``Não vos amoldeis às estruturas deste mundo, \\
		mas transformai-vos pela renovação da mente, \\
		a fim de distinguir qual é a vontade de Deus: \\
		o que é bom, o que Lhe é agradável, o que é perfeito.\\
		(Bíblia Sagrada, Romanos 12, 2)}
	\end{flushright}
\end{epigrafe}
% ---

% ---
% RESUMO EM PORTUGUÊS
% ---
\begin{resumo}
	Este trabalho apresenta o projeto e desenvolvimento de um veículo robótico autônomo de pequeno porte, concebido para realizar tarefas de transporte de objetos em ambientes internos. O sistema é fundamentado no microcontrolador ESP32, que centraliza o processamento e a conectividade. A percepção do ambiente e a locomoção precisa são viabilizadas pela integração de múltiplos sensores e atuadores, incluindo um magnetômetro QMC5883L para referência de orientação, um sensor de distância \textit{Time-of-Flight} (ToF) VL53L0X para detecção frontal de obstáculos e encoders ópticos para odometria. O controle de movimento dos motores DC é realizado por meio de uma ponte H com modulação por largura de pulso (PWM), e a estabilidade da trajetória é garantida por um algoritmo de controle Proporcional, Integral e Derivativo (PID). A autonomia de navegação é alcançada por uma estratégia híbrida que combina planejamento de rota global, utilizando o algoritmo A* sobre um mapa de grid, com um controle reativo local para desvio de obstáculos em tempo real. A interação com o usuário é realizada através de uma interface web (WebServer) embarcada, que permite a designação de destinos e o monitoramento do robô via Wi-Fi. O projeto visa entregar um protótipo funcional, de baixo custo e com arquitetura modular, servindo como uma plataforma educacional e de pesquisa em robótica móvel, sistemas embarcados e Internet das Coisas (IoT).
	\vspace{\onelineskip}

	\noindent
	\textbf{Palavras-chave}: Robô Autônomo. ESP32. Controle PID. Navegação Robótica. Mapeamento em Grid. Sistemas Embarcados.
\end{resumo}

% ---
% RESUMO EM INGLÊS (ABSTRACT)
% ---
\begin{resumo}[Abstract]
	\begin{otherlanguage*}{english}
		This work presents the design and development of a small-scale autonomous robotic vehicle, designed to perform object transportation tasks in indoor environments. The system is based on the ESP32 microcontroller, which centralizes processing and connectivity. Environmental perception and precise locomotion are enabled by the integration of multiple sensors and actuators, including a QMC5883L magnetometer for heading reference, a VL53L0X Time-of-Flight (ToF) distance sensor for frontal obstacle detection, and optical encoders for odometry. The motion control of the DC motors is performed using an H-bridge with Pulse Width Modulation (PWM), and trajectory stability is ensured by a Proportional, Integral, and Derivative (PID) control algorithm. Navigation autonomy is achieved through a hybrid strategy that combines global path planning, using the A* algorithm on a grid map, with local reactive control for real-time obstacle avoidance. User interaction is carried out through an embedded web interface (WebServer), which allows for destination designation and robot monitoring via Wi-Fi. The project aims to deliver a functional, low-cost prototype with a modular architecture, serving as an educational and research platform in mobile robotics, embedded systems, and the Internet of Things (IoT).
		\vspace{\onelineskip}

		\noindent
		\textbf{Keywords}: Autonomous Robot. ESP32. PID Control. Robotic Navigation. Grid Mapping. Embedded Systems.
	\end{otherlanguage*}
\end{resumo}

% ---
% inserir lista de ilustrações
% ---
\pdfbookmark[0]{\listfigurename}{lof}
\listoffigures*
\cleardoublepage
% ---

% ---
% inserir lista de tabelas
% ---
% \pdfbookmark[0]{\listtablename}{lot}
% \listoftables*
% \cleardoublepage
% ---

% ---
% inserir lista de abreviaturas e siglas
% ---
\begin{siglas}
	\item[ADC] Conversor Analógico-Digital (Analog-to-Digital Converter)
	\item[AUV] Veículo Submerso Autônomo (Autonomous Underwater Vehicle)
	\item[DC] Corrente Contínua (Direct Current)
	\item[GPIO] Pinos de Entrada/Saída de Propósito Geral (General-Purpose Input/Output)
	\item[HTTP] Protocolo de Transferência de Hipertexto (Hypertext Transfer Protocol)
	\item[IMU] Unidade de Medição Inercial (Inertial Measurement Unit)
	\item[IoT] Internet das Coisas (Internet of Things)
	\item[IHM] Interface Homem-Máquina
	\item[I2C] Inter-Integrated Circuit (padrão de comunicação)
	\item[PID] Controlador Proporcional–Integral–Derivativo
	\item[PRM] Mapa de Rotas Probabilístico (Probabilistic Roadmap)
	\item[PWM] Modulação por Largura de Pulso (Pulse Width Modulation)
	\item[RAS] Sistemas Robóticos e Autônomos (Robotic and Autonomous Systems)
	\item[RMA] Robôs Móveis Autônomos
	\item[RTOS] Sistema Operacional de Tempo Real (Real-Time Operating System)
	\item[SLAM] Localização e Mapeamento Simultâneos (Simultaneous Localization and Mapping)
	\item[SPI] Interface Periférica Serial (Serial Peripheral Interface)
	\item[ToF] Tempo de Voo (Time-of-Flight)
	\item[UART] Transmissor/Receptor Assíncrono Universal (Universal Asynchronous Receiver-Transmitter)
	\item[VL53L0X] Sensor ToF da STMicroelectronics
	\item[Wi-Fi] Wireless Fidelity (Tecnologia de rede sem fio)
	\item[WebServer] Servidor Web embarcado
	\item[ESP32] Microcontrolador com Wi-Fi e Bluetooth integrados da Espressif Systems
	\item[QMC5883L] Magnetômetro digital de três eixos utilizado como referência de orientação magnética
	\item[A*] Algoritmo A-star para planejamento de caminhos
\end{siglas}
% ---

% ---
% inserir o sumario
% ---
\pdfbookmark[0]{\contentsname}{toc}
\tableofcontents*
\cleardoublepage
% ---

% ----------------------------------------------------------
% ELEMENTOS TEXTUAIS
% ----------------------------------------------------------
\textual

% ----------------------------------------------------------
% Introdução
% ----------------------------------------------------------
\chapter{Introdução}

A crescente evolução dos sistemas embarcados e da Internet das Coisas (IoT) tem impulsionado o desenvolvimento de soluções autônomas para aplicações cotidianas. Nesse cenário, veículos autônomos têm despertado interesse pela sua aplicabilidade em tarefas de transporte interno, contribuindo para a automação e otimização de processos \cite{SCHILLINGK_FLEXIBLE_AUTONOMOUS_TRANSPORT}.

O campo da robótica móvel tem-se desenvolvido significativamente nas últimas décadas, especialmente com a popularização de plataformas modulares e reconfiguráveis \cite{MOUBARAK20121648} e robôs com capacidade de adaptação a ambientes complexos e dinâmicos \cite{SCHILLINGK_FLEXIBLE_AUTONOMOUS_TRANSPORT}. Nesse contexto, dentro da robótica, os agentes podem ser classificados de acordo com seu grau de autonomia, como por exemplo, robôs teleoperados, semi-autônomos e autônomos. Em todos esses tipos de robôs, e em especial para robôs com graus elevados de autonomia, o uso de sensores embarcados, como unidades de medição inerciais (IMUs) e sensores de distância, em conjunto com algoritmos de controle robustos, como o PID (Proporcional, Integral, Derivativa), têm sido essenciais para garantir precisão e estabilidade \cite{selfreconfigurable_cleaning_robot2020}.

Dentre as aplicações de sistemas robóticos autônomos, podem ser destacadas os robôs de resgate e salvamento \cite{calisi2007autonomous,antonios2024review}, manutenção de submarina \cite{lemos2021auv,frontiers2023underwater}, interface com seres humanos em museus \cite{cantucci2024museum,extrica2024museum}, aplicações militares \cite{hcss2021military,automate2023defense}, entre outros. Em especial, os trabalhos de \cite{nehmzow2012mobile} e \cite{SCHILLINGK_FLEXIBLE_AUTONOMOUS_TRANSPORT} destacam a importância de projetos didáticos e aplicáveis de veículos autônomos tanto em ambientes industriais quanto acadêmicos, reforçando a relevância de soluções acessíveis e flexíveis.

Dessa forma, este projeto visa desenvolver um veículo autônomo de pequeno porte com quatro rodas, baseado em um microcontrolador de baixo custo, equipado com magnetômetro, sensor de distância e encoders ópticos. O sistema será capaz de realizar deslocamentos autônomos utilizando mapeamento em grid e planejamento de rotas, com controle remoto por interface web.

A principal motivação do projeto é criar uma solução acessível e didática para transporte interno automatizado em ambientes acadêmicos, facilitando processos de gestão dentro da universidade. Além disso, o desenvolvimento do projeto vai proporcionar o aprendizado multidisciplinar. A contribuição esperada é o desenvolvimento de uma plataforma de baixo custo com potencial de aplicação em ambientes reais, além de servir como base para futuras pesquisas em robótica móvel e IoT.

\section{Objetivos}

Este trabalho tem como finalidade o desenvolvimento de um assistente robótico autônomo voltado à automação de tarefas de transporte de objetos em ambientes internos, como escritórios e residências. A proposta consiste em permitir que o usuário delegue, por meio de uma interface de controle, a entrega de itens a um destino previamente definido, sem a necessidade de deslocamento físico até o local de destino.

Além de propor uma solução prática para aplicações logísticas em pequena escala, o projeto busca consolidar e aplicar os conhecimentos teóricos adquiridos ao longo da graduação, com ênfase nas disciplinas de Sistemas Embarcados, Inteligência Artificial e Internet das Coisas (IoT). A iniciativa visa integrar esses conceitos por meio da construção de um sistema funcional, de baixo custo e alto valor educacional e tecnológico.

\subsection{Objetivo Geral}

Desenvolver um protótipo funcional de um veículo robótico autônomo de pequeno porte, dotado de quatro rodas, controlado por um microcontrolador ESP32, e equipado com magnetômetro QMC5883L, sensor de distância por tempo de voo (VL53L0X) e encoders ópticos para monitoramento da rotação das rodas. O sistema deverá ser capaz de se locomover autonomamente em ambientes internos, utilizando mapeamento baseado em grid, planejamento de rotas com A* e definição do destino via interface web.

\subsection{Objetivos Específicos}

\begin{itemize}
	\item Projetar e montar a estrutura física do robô, incluindo os motores, a carcaça e a eletrônica embarcada;
	\item Implementar controle de velocidade e trajetória utilizando algoritmos PID com feedback dos encoders;
	\item Integrar o magnetômetro, o sensor de distância e os encoders ópticos ao sistema de controle e navegação;
	\item Desenvolver o módulo de mapeamento em grid e aplicar algoritmos de busca para planejamento de trajetórias (como o algoritmo A*);
	\item Implementar uma interface web acessível via rede Wi-Fi, permitindo a seleção de destinos pelo usuário;
	\item Realizar testes experimentais e validar o desempenho do sistema em ambiente controlado, analisando a precisão, a robustez e a viabilidade da proposta.
\end{itemize}

\section{Organização do Texto}

Este trabalho está estruturado da seguinte forma:

\begin{itemize}
	\item \textbf{Capítulo 2 — Revisão Bibliográfica:} apresenta uma análise de trabalhos relacionados à robótica móvel autônoma, abordando diferentes aplicações e tecnologias que fundamentam o projeto.
	\item \textbf{Capítulo 3 — Fundamentação Teórica:} detalha os conceitos teóricos essenciais, incluindo sistemas embarcados, controle de motores, magnetômetro, sensores de distância, odometria por encoders, algoritmos PID, odometria e técnicas de mapeamento e planejamento de rotas.
	\item \textbf{Capítulo 4 — Materiais e Métodos:} descreve os componentes de hardware e as ferramentas de software utilizadas, a arquitetura do sistema, as estratégias de controle e navegação, e a metodologia de desenvolvimento do protótipo.
	\item \textbf{Capítulo 5 — Resultados:} apresenta a metodologia de teste, os registros utilizados, os resultados de deslocamento, rotação, detecção de obstáculos, interface web e as limitações observadas experimentalmente.
	\item \textbf{Capítulo 6 — Conclusão:} consolida as conclusões do trabalho, discute a viabilidade do protótipo e apresenta recomendações para trabalhos futuros.
\end{itemize}

% --- Início do Capítulo de Revisão Bibliográfica ---

\chapter{Revisão Bibliográfica}
\label{chap:revisao}

Este capítulo apresenta uma análise de trabalhos relacionados ao desenvolvimento de robôs móveis autônomos, com foco na aplicação em ambientes internos e no transporte de pequenos objetos. São considerados aspectos como autonomia de navegação, controle embarcado, sensoriamento, planejamento de rotas e usabilidade em contextos educacionais ou institucionais. Embora a área de robótica móvel autônoma seja ampla, buscou-se destacar estudos que, direta ou indiretamente, dialogam com os objetivos e desafios deste projeto.

Robôs aplicados a missões de busca e salvamento, como os descritos por \citeonline{calisi2007autonomous}, utilizam estratégias avançadas de exploração e navegação em ambientes não estruturados. Esses robôs são capazes de se orientar em locais desconhecidos e dinâmicos, utilizando sensores embarcados e algoritmos de mapeamento para garantir a segurança da operação. De forma complementar, \citeonline{antonios2024review} apresentam uma revisão sistemática sobre robôs de resgate equipados com inteligência artificial, destacando a integração entre sensoriamento preciso, aprendizado de máquina e planejamento adaptativo em cenários de alto risco. Apesar de operarem em contextos significativamente mais complexos, esses estudos fornecem subsídios importantes sobre navegação segura e sensoriamento embarcado.

Ainda que este projeto se concentre em ambientes internos e controlados, como salas de aula e laboratórios, há paralelos metodológicos com outras aplicações robóticas. Trabalhos como os de \citeonline{lemos2021auv} e \citeonline{frontiers2023underwater} discutem o uso de veículos submersos autônomos (AUVs) para inspeção de estruturas submarinas, enfrentando desafios técnicos severos, como navegação em seis graus de liberdade e comunicação limitada. Apesar das diferenças no ambiente operacional, ambos os casos compartilham a necessidade de controle embarcado confiável, fusão sensorial e autonomia de locomoção — elementos também centrais para o presente projeto.

Em ambientes públicos e educacionais, \citeonline{cantucci2024museum} investigaram o impacto da autonomia adaptativa de robôs na experiência dos visitantes em museus. Já \citeonline{extrica2024museum} analisam o uso de robôs inteligentes como mediadores culturais em espaços expositivos. Esses estudos destacam a importância da interação com o usuário, da acessibilidade e da robustez na arquitetura de controle. O robô desenvolvido neste projeto, embora mais simples em termos de funcionalidade e escopo, compartilha o objetivo de ser uma ferramenta acessível, intuitiva e funcional em contextos institucionais e educacionais, promovendo uma experiência de uso descomplicada por meio de uma interface web.

Robôs autônomos também são amplamente empregados em aplicações militares e de defesa, conforme discutido em \citeonline{hcss2021military} e \citeonline{automate2023defense}. Nesses cenários, robustez estrutural, inteligência situacional e operação remota segura são características críticas. Embora o projeto aqui apresentado não possua finalidade bélica, ele adota conceitos estruturais semelhantes, como a navegação baseada em sensores, o controle de trajetória via PID e a operação remota via rede sem fio, adaptados para fins acadêmicos e com foco em baixo custo e reprodutibilidade.

No campo da robótica modular, \citeonline{MOUBARAK20121648} destacam a importância de plataformas reconfiguráveis, que possibilitam adaptações estruturais para diferentes tipos de missão. Embora o robô desenvolvido neste projeto não possua capacidade de reconfiguração física, adota uma arquitetura modular do ponto de vista do software e da organização dos componentes embarcados. O uso de bibliotecas customizadas, divididas por responsabilidade funcional, favorece a manutenção do sistema e sua expansão futura.

Em síntese, os trabalhos analisados contribuem para o embasamento técnico do projeto, oferecendo diferentes perspectivas sobre sensoriamento, controle e navegação em robôs móveis. O diferencial da proposta apresentada neste TCC reside na sua aplicação prática: a criação de um robô autônomo de pequeno porte, controlado por um ESP32, capaz de realizar o transporte de objetos em ambientes internos por meio de navegação baseada em mapeamento em grid, sensores de distância (VL53L0X), referência magnética de orientação (QMC5883L), algoritmo A* e interface web embarcada. Trata-se de uma solução voltada à didática, ao baixo custo e à possibilidade de replicação em contextos educacionais e institucionais.

\chapter{Fundamentação Teórica}
\label{cap:fundamentacao_teorica}

Este capítulo apresenta os fundamentos teóricos que sustentam o desenvolvimento do projeto, abrangendo os conceitos, tecnologias e métodos necessários para a construção de um veículo robótico autônomo com capacidade de navegação em ambiente interno. A estrutura modular do sistema envolve desde a integração de sensores e atuadores até o controle de movimento e planejamento de rotas.

Inicialmente, são abordados os conceitos de sistemas embarcados e Internet das Coisas (IoT), destacando-se suas arquiteturas e aplicações práticas, bem como a justificativa da escolha do microcontrolador ESP32, amplamente utilizado em projetos que exigem conectividade e capacidade computacional embarcada (Seção~\ref{sec:sistemas_emb}).

Na sequência, são discutidos os princípios de controle de motores de corrente contínua (DC) utilizando circuitos do tipo ponte H, responsáveis por permitir o acionamento bidirecional e o ajuste de velocidade dos motores (Seção~\ref{sec:controle_motores}). A Seção~\ref{sec:pid_odometria} trata da aplicação do controle PID para estabilização e controle de movimento, bem como do uso de odometria com encoders para estimativa de deslocamento do robô.

Também são explorados os recursos de orientação magnética (Seção~\ref{sec:qmc5883l}), com destaque para o sensor QMC5883L, que fornece medições do campo magnético nos eixos X, Y e Z para estimativa de direção no plano horizontal. Em seguida, na Seção~\ref{sec:vl53l0x}, discorre-se sobre sensores de distância baseados no princípio de \textit{Time-of-Flight} (ToF), como o VL53L0X, cuja precisão e velocidade tornam-no adequado para detecção de obstáculos em tempo real.

Por fim, a Seção~\ref{sec:mapeamento_grid} apresenta as técnicas de representação do ambiente por meio de mapas em grid e os algoritmos de planejamento de rotas, como A* e Dijkstra, que permitem ao robô traçar trajetórias seguras e eficientes até o destino escolhido.

Esses tópicos compõem o corpo teórico necessário para a implementação do sistema proposto, oferecendo suporte conceitual e justificativa técnica para as decisões de projeto. A fundamentação apresentada a seguir baseia-se em referências consolidadas na literatura acadêmica e técnica, como \citeonline{kurose2009computer}, entre outras.

\section{Sistemas Embarcados e IoT} \label{sec:sistemas_emb}

Sistemas embarcados consistem em plataformas computacionais especializadas, compostas por microcontroladores, firmware e, em alguns casos, sistemas operacionais de tempo real (RTOS), cujo propósito é executar tarefas específicas sob restrições rígidas de desempenho, consumo energético e confiabilidade. Essas plataformas integram, de forma sinérgica, componentes de hardware e software, promovendo soluções otimizadas para diferentes finalidades. Por serem projetados para operar de maneira contínua, eficiente e, frequentemente, em tempo real, os sistemas embarcados desempenham papel central em diversos setores da tecnologia, como automação industrial, controle de processos, equipamentos médicos, monitoramento ambiental e dispositivos de Internet das Coisas (IoT), \citeonline{matiz2024sistemas}.

No contexto da IoT, a integração de sistemas embarcados com redes de comunicação sem fio, como Wi-Fi, Bluetooth e LoRa, potencializa a conectividade e a interoperabilidade entre dispositivos distribuídos. Essa conectividade torna possível a criação de ambientes inteligentes, capazes de reagir dinamicamente a estímulos do ambiente, compartilhar dados em tempo real e executar comandos remotos. Entretanto, tais sistemas exigem soluções que conciliem eficiência energética, segurança de dados e escalabilidade, aspectos críticos para aplicações em larga escala, como cidades inteligentes, agricultura de precisão e automação residencial.

Para o desenvolvimento deste projeto, foi selecionado o microcontrolador ESP32, do kit de desenvolvimento DOIT ESP32 Devkit V1, devido à sua ampla versatilidade, baixo custo e rica gama de funcionalidades embarcadas. O ESP32 possui conectividade Wi-Fi e Bluetooth integradas, múltiplos núcleos de processamento, suporte a múltiplos pinos GPIO, conversores analógico-digitais (ADCs), interfaces I2C, SPI e UART, além de timers e recursos de controle PWM, características que o tornam ideal para aplicações embarcadas modernas. A \textit{Figura~\ref{fig:esp32_pinout}} apresenta o diagrama de pinagem da placa, destacando a disposição dos pinos e suas respectivas funcionalidades, informação essencial para a correta conexão dos periféricos utilizados no protótipo.
\begin{figure}[ht]
	\centering
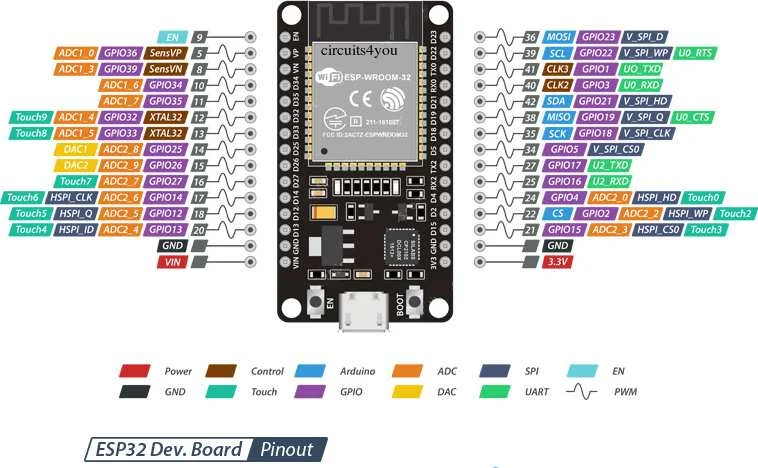
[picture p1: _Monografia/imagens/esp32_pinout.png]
	
	\caption{Diagrama de pinagem do ESP32.}
	\label{fig:esp32_pinout}
	\vspace{0.2em}
	\small\textit{Fonte: \href{https://lastminuteengineers.com/esp32-pinout-reference/}{lastminuteengineers.com}}
\end{figure}

A escolha do ESP32 justifica-se, portanto, por sua capacidade de processamento superior, ampla conectividade, suporte a múltiplos protocolos de comunicação e integração de periféricos essenciais, reduzindo a necessidade de componentes externos. Além disso, sua popularidade na comunidade de desenvolvimento embarcado proporciona vasta documentação e bibliotecas de código, facilitando o processo de implementação e depuração do sistema. 

\section{FreeRTOS em Sistemas Embarcados}
\label{sec:freertos}

Em sistemas embarcados, especialmente aqueles que precisam lidar simultaneamente com sensoriamento, controle de atuadores, comunicação e interface com o usuário, a execução sequencial de todas as tarefas pode se tornar limitada. Nesses casos, o uso de um sistema operacional de tempo real, ou RTOS (\textit{Real-Time Operating System}), permite organizar o software em tarefas independentes, com prioridades, intervalos de execução e mecanismos de sincronização próprios.

O FreeRTOS é um sistema operacional de tempo real amplamente utilizado em microcontroladores por apresentar baixo consumo de memória, portabilidade e suporte a múltiplas arquiteturas embarcadas. Conforme apresentado por \citeonline{barry2016freertos}, o núcleo do FreeRTOS foi projetado para organizar aplicações embarcadas em tarefas concorrentes, utilizando escalonamento por prioridades e mecanismos de temporização e sincronização adequados a sistemas com recursos limitados. Diferentemente de sistemas operacionais convencionais, seu objetivo não é fornecer uma interface completa de uso geral, mas permitir a execução previsível de tarefas, como leitura de sensores, controle de motores, comunicação sem fio e atualização de estados internos do sistema.

No contexto do ESP32, o FreeRTOS é particularmente relevante, pois a própria plataforma de desenvolvimento utilizada pelo microcontrolador é baseada nesse sistema operacional. O ESP32 possui arquitetura com dois núcleos de processamento, permitindo que diferentes tarefas sejam distribuídas entre eles. Essa característica favorece a separação entre atividades críticas de controle, como leitura de encoders e atualização de comandos de motores, e atividades de comunicação, como atendimento à interface web e envio de telemetria.

Entre os principais recursos fornecidos pelo FreeRTOS estão a criação de tarefas, o escalonamento por prioridade, os atrasos temporizados, as filas de comunicação, os semáforos e os mecanismos de sincronização entre tarefas. Esses recursos permitem estruturar o software de forma modular, evitando que uma rotina bloqueante impeça a execução de outras partes importantes do sistema. Por exemplo, em um robô móvel, a leitura periódica de sensores deve ocorrer mesmo enquanto o sistema processa comandos recebidos pela interface web ou atualiza informações de monitoramento.

Neste trabalho, o uso do FreeRTOS está associado à organização das rotinas embarcadas do robô em tarefas de execução concorrente. Essa abordagem permite separar funções como aquisição de dados sensoriais, atualização da telemetria, controle de movimentação e comunicação com a interface web. Com isso, o sistema passa a responder de forma mais adequada a eventos simultâneos, como a detecção de obstáculos, a recepção de comandos externos e a necessidade de atualização contínua da posição estimada do robô.

Apesar dessas vantagens, o uso de tarefas concorrentes também exige cuidados adicionais. A troca de informações entre diferentes tarefas deve ser realizada de forma controlada, evitando condições de corrida, leituras inconsistentes ou disputas por recursos compartilhados. Por esse motivo, variáveis relacionadas ao estado do robô, leituras de sensores e comandos de movimentação devem ser tratadas com atenção, especialmente quando acessadas por múltiplas rotinas.

Assim, o FreeRTOS contribui para a organização do software embarcado ao permitir uma arquitetura baseada em tarefas, mais adequada à natureza concorrente do sistema robótico desenvolvido. Sua utilização favorece a separação entre sensoriamento, controle, navegação e comunicação, permitindo maior robustez e responsividade durante a execução dos testes experimentais.

\section{Controle de Motores DC e Ponte H} \label{sec:controle_motores}

Motores de corrente contínua (DC) são componentes amplamente utilizados em plataformas robóticas móveis, especialmente em projetos com sistemas embarcados. Isso se deve à sua construção relativamente simples, ao custo acessível e à capacidade de resposta rápida a comandos de controle. No entanto, para que seja possível controlar de forma eficaz tanto a direção quanto a velocidade desses motores, é necessário empregar circuitos de acionamento apropriados, sendo a ponte H uma das soluções mais utilizadas para esse fim.

A ponte H consiste em um arranjo eletrônico formado geralmente por quatro dispositivos semicondutores de chaveamento (transistores bipolares) dispostos de modo a formar uma topologia semelhante à letra “H”. Esse circuito permite o controle da polaridade da tensão aplicada aos terminais do motor, viabilizando, assim, o acionamento em ambos os sentidos de rotação. Tal característica é fundamental para o deslocamento de robôs autônomos, que requerem comandos precisos de avanço, recuo e curvas, os quais são obtidos por meio do controle individual de cada motor responsável pela movimentação.

Para controlar a velocidade de rotação, é frequentemente empregada a técnica de modulação por largura de pulso (PWM), que ajusta a potência média entregue ao motor pela variação do ciclo de trabalho de um sinal digital. Essa estratégia possibilita uma regulação contínua da velocidade, mantendo a eficiência energética do sistema e reduzindo o desgaste dos componentes eletromecânicos.

A ponte H, portanto, representa uma alternativa consolidada tanto em ambientes educacionais quanto em sistemas de aplicação prática, devido à sua confiabilidade e simplicidade de implementação. Sua interface com microcontroladores, como o ESP32, ocorre por meio de sinais digitais que controlam o estado de cada chave do circuito, permitindo a integração direta com algoritmos de controle embarcados.

\begin{figure}[ht]
	\centering
	\begin{subfigure}[b]{0.48\linewidth}
		\centering
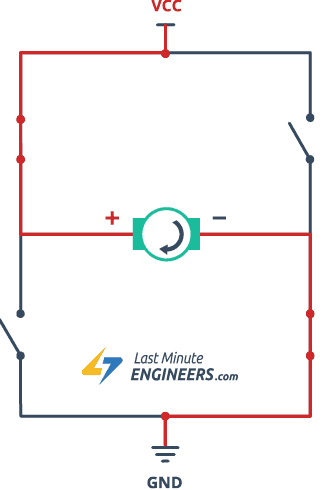
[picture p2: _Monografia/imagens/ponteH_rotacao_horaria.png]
		
		\caption{Rotação horária do motor.}
		\label{fig:ponte_h_horario}
	\end{subfigure}
	\hfill
	\begin{subfigure}[b]{0.48\linewidth}
		\centering
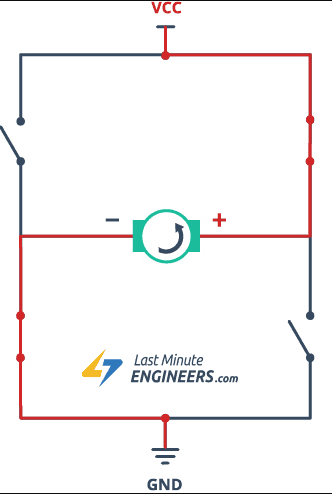
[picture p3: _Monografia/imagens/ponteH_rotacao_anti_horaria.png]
		
		\caption{Rotação anti-horária do motor.}
		\label{fig:ponte_h_anti_horario}
	\end{subfigure}
	\caption{Funcionamento da ponte H para diferentes sentidos de rotação.}
	\label{fig:ponte_h_rotacoes}
	\vspace{0.2em}
	\small\textit{Fonte: \href{https://lastminuteengineers.com/l298n-dc-stepper-driver-arduino-tutorial/}{LASTMINUTEENGINEERS, 2024}.}
\end{figure}

A \textit{Figura~\ref{fig:ponte_h_rotacoes}} ilustra os dois modos de operação da ponte H, demonstrando como a combinação das chaves eletrônicas determina a direção da corrente elétrica no motor, resultando em rotação no sentido horário ou anti-horário.

\section{Orientação Magnética com QMC5883L} \label{sec:qmc5883l}

O QMC5883L é um magnetômetro digital de três eixos utilizado para medir componentes do campo magnético nos eixos X, Y e Z. Diferentemente de uma unidade inercial como o MPU6050, esse sensor não possui acelerômetro nem giroscópio, de modo que não fornece diretamente aceleração linear, velocidade angular ou temperatura útil para controle de movimento. Sua principal aplicação no contexto deste projeto é fornecer uma referência de orientação absoluta no plano horizontal, calculada a partir da relação entre as componentes magnéticas dos eixos X e Y.

O cálculo do ângulo de orientação, ou \textit{heading}, é realizado por meio da função \texttt{atan2}, aplicada às leituras convertidas para unidades proporcionais ao campo magnético. Após esse cálculo, podem ser aplicados ajustes de declinação magnética, offsets de calibração e normalização angular para manter o resultado em uma faixa consistente.

Matematicamente, o heading bruto obtido a partir do magnetômetro pode ser representado por:

\begin{equation}
\theta_{bruto} = \operatorname{atan2}(B_y, B_x)
\end{equation}

onde:
\begin{itemize}
\item \(B_x\) e \(B_y\) representam as componentes do campo magnético medidas nos eixos X e Y;
\item \(\operatorname{atan2}\) calcula o ângulo considerando o quadrante correto da leitura;
\item \(\theta_{bruto}\) corresponde ao heading inicial antes dos ajustes de calibração.
\end{itemize}

Após a leitura bruta, a orientação final utilizada pelo sistema é obtida pela aplicação da declinação magnética e do offset de referência angular definido no robô:

\begin{equation}
\theta_{heading} = \operatorname{mod}(\theta_{bruto} + \delta - \theta_{0},\, 360^\circ)
\end{equation}

em que \(\delta\) representa a declinação magnética local e \(\theta_{0}\) é o zero angular configurado na calibração.

Magnetômetros estão sujeitos a perturbações provocadas por materiais ferromagnéticos e por campos magnéticos gerados por correntes elétricas próximas. Por essa razão, sua aplicação em plataformas móveis exige calibração e cuidado com o posicionamento físico do sensor. As decisões específicas de integração, filtragem e uso do QMC5883L neste protótipo são apresentadas no Capítulo~\ref{cap:materiais_metodos}.

\begin{figure}[ht]
	\centering
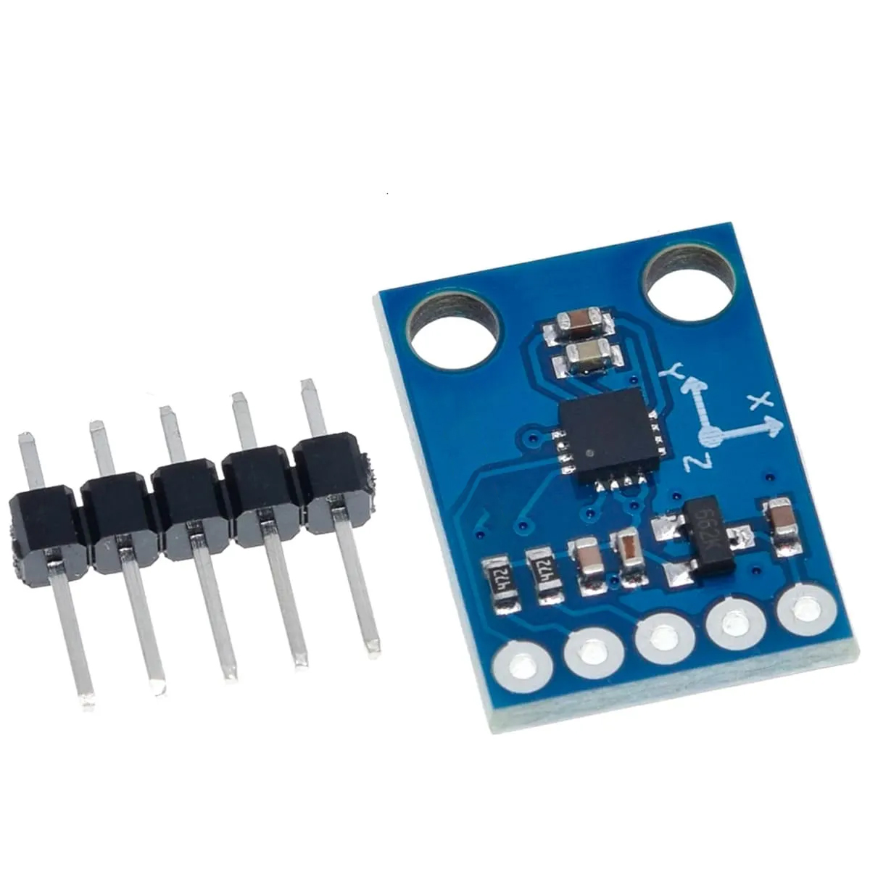
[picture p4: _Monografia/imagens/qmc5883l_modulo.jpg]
	
	\caption{Módulo magnetômetro QMC5883L.}
	\label{fig:qmc5883l_modulo}
	\small\textit{Fonte: \href{https://www.casadarobotica.com/sensores-modulos/sensores/outros/modulo-bussola-eletronica-magnetometro-hmc5883l}{CASA DA ROBOTICA, 2026}.}
\end{figure}

\section{Sensores Time-of-Flight: VL53L0X} \label{sec:vl53l0x}
Sensores do tipo \textit{Time-of-Flight} (ToF), como o modelo VL53L0X, realizam medições de distância com base no tempo que um feixe de luz, geralmente laser infravermelho, leva para atingir um objeto e retornar ao sensor após a reflexão. Esse princípio de funcionamento permite a obtenção de leituras rápidas e com elevada precisão, alcançando uma resolução na ordem de milímetros e alcance típico de até 1,2 metros em ambientes controlados \citeonline{adafruit2024vl53l0x}. Tais características tornam os sensores ToF especialmente adequados para aplicações que requerem resposta em tempo real, como navegação autônoma, detecção e evasão de obstáculos e mapeamento de ambientes tridimensionais.

A escolha do sensor VL53L0X neste projeto se deu, principalmente, por sua superioridade em relação a outros sensores amplamente utilizados no ensino e em projetos de prototipagem, como o HC-SR04. Enquanto o HC-SR04 utiliza ondas ultrassônicas, que estão sujeitas a variações ambientais (como temperatura e tipo de superfície do objeto), o VL53L0X opera com luz, o que lhe confere maior estabilidade, tempo de resposta mais curto e maior precisão nas medições. Dessa forma, o VL53L0X apresenta-se como uma solução mais robusta e confiável para os requisitos do sistema robótico proposto, especialmente no que se refere à detecção eficiente de obstáculos em tempo real e à construção de um mapeamento preciso do ambiente. A representação de um sensor equivalente ao utilizado no projeto está representado na Figura~\ref{fig:vl53l0x-sensor}.

\begin{figure}[ht]
	\centering
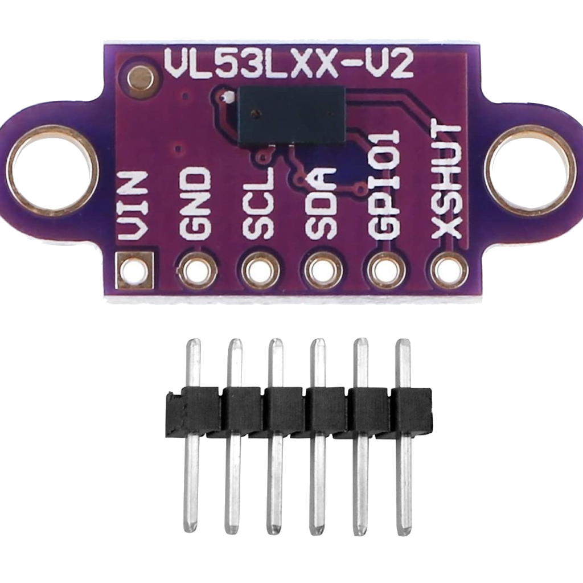
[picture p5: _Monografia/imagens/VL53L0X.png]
	
	\caption{Sensor VL53L0X}
	\small\textit{Fonte: \href{https://arduinoecia.com.br/product/sensor-de-distancia-vl53l0x-laser-time-of-flight-tof/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}{ARDUINOECIA, 2025}.}
	\label{fig:vl53l0x-sensor}
\end{figure}

\section{Algoritmos PID e Odometria} \label{sec:pid_odometria}

O controle PID é uma das técnicas mais amplamente utilizadas em sistemas de controle automático, especialmente em aplicações embarcadas e robóticas. Sua popularidade advém da simplicidade de implementação e da eficácia no controle de processos dinâmicos. Em robótica móvel, o PID é comumente aplicado ao controle de velocidade e posição dos motores, ajustando continuamente os sinais de atuação de acordo com o erro entre o valor desejado (referência) e o valor atual medido.

Matematicamente, a saída de controle \( u(t) \) do controlador PID é definida como:

\begin{equation}
u(t) = K_p e(t) + K_i \int_{0}^{t} e(\tau)\, d\tau + K_d \frac{de(t)}{dt}
\end{equation}

onde:
\begin{itemize}
	\item \( e(t) \) representa o erro entre a referência e a saída do sistema no instante \( t \);
	\item \( K_p \) é o ganho proporcional, que reage à magnitude do erro atual;
	\item \( K_i \) é o ganho integral, que corrige desvios acumulados ao longo do tempo;
	\item \( K_d \) é o ganho derivativo, que antecipa tendências com base na taxa de variação do erro.
\end{itemize}

A sintonização adequada desses parâmetros (\( K_p \), \( K_i \) e \( K_d \)) é essencial para garantir estabilidade, tempo de resposta adequado e evitar oscilações ou sobrecargas no sistema, como mostrado em \citeonline{astrom2006advancedpid}.

Complementarmente ao controle, a navegação precisa em ambientes internos exige a estimativa contínua da posição e da orientação do robô, processo conhecido como odometria. A odometria clássica baseia-se na leitura incremental dos encoders ópticos acoplados às rodas motrizes, que fornecem a quantidade de pulsos gerados conforme as rodas giram. Com base nesses dados, é possível calcular o deslocamento linear e angular do robô por integração das variações de posição ao longo do tempo.

Considerando um robô diferencial com duas rodas, os deslocamentos linear \( \Delta s \) e angular \( \Delta \theta \) são dados por: \citeonline{siegwart2011introduction}

\begin{align}
	\Delta s &= \frac{r}{2} (\Delta \phi_R + \Delta \phi_L) \\
	\Delta \theta &= \frac{r}{d} (\Delta \phi_R - \Delta \phi_L)
\end{align}

onde:
\begin{itemize}
	\item \( r \) é o raio das rodas;
	\item \( d \) é a distância entre as rodas;
	\item \( \Delta \phi_R \) e \( \Delta \phi_L \) são os incrementos angulares das rodas direita e esquerda, respectivamente.
\end{itemize}

Essas equações permitem atualizar a posição do robô em coordenadas cartesianas \( (x, y) \) com base no deslocamento linear e na mudança de orientação, utilizando relações trigonométricas.

Apesar da sua simplicidade, a odometria baseada exclusivamente em encoders está sujeita a erros cumulativos, como deslizamentos de roda e imprecisões de leitura. Para mitigar esses erros, é comum a fusão de sensores, combinando odometria com referências externas de orientação, como o \textit{magnetômetro QMC5883L} \cite{unicamp2017odometria}.

Portanto, a utilização combinada do controle PID e da odometria fornece uma base robusta para a movimentação precisa e a navegação confiável do robô em ambientes internos, atendendo aos requisitos de autonomia e estabilidade do sistema proposto.

\section{Mapeamento em Grid e Planejamento de Rotas}
\label{sec:mapeamento_grid}

O mapeamento em grid é uma técnica amplamente adotada na robótica móvel para representar ambientes de maneira discreta. Nessa abordagem, o espaço contínuo é dividido em uma matriz bidimensional de células uniformes, também denominada grade de ocupação. Cada célula representa uma região do ambiente e pode ser classificada, por exemplo, como livre, ocupada ou desconhecida, de acordo com as informações disponíveis sobre o espaço \cite{ufla2020mapa}.

A representação matricial facilita o tratamento computacional do ambiente e permite formular o problema de navegação como uma busca em grafo. As células livres correspondem aos estados que podem ser visitados pelo robô, enquanto as células ocupadas restringem o conjunto de movimentos admissíveis. A Figura~\ref{fig:grid-mapping-basics} apresenta um exemplo de discretização de um ambiente em células.

\begin{figure}[ht]
		\centering
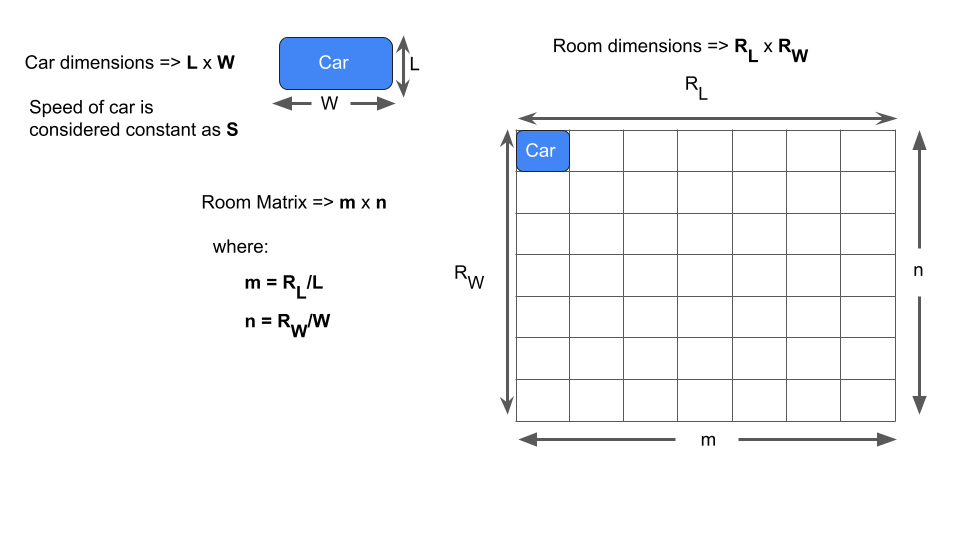
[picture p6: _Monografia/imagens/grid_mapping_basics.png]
		
		\caption{Exemplo simplificado de mapeamento em grid \cite{patel2021ultrasonic}.}
		\label{fig:grid-mapping-basics}
\end{figure}

Após a definição da grade, algoritmos de busca podem ser empregados para calcular uma trajetória entre uma célula inicial e uma célula de destino. Entre os algoritmos utilizados para esse propósito estão Dijkstra e A*. O algoritmo A* combina o custo acumulado desde a origem com uma função heurística que estima o custo restante até o destino.

De forma geral, a função de avaliação do A* é expressa por:

\begin{equation}
		f(n) = g(n) + h(n),
\end{equation}

em que \(g(n)\) representa o custo acumulado da origem até o nó \(n\), e \(h(n)\) representa uma estimativa do custo entre \(n\) e o destino. Em grades com movimentação ortogonal, uma heurística comum é a distância de Manhattan.

A rota gerada pelo planejador é formada por uma sequência ordenada de células adjacentes. Para que essa rota seja executada por um robô móvel, ela deve ser convertida em comandos de movimento compatíveis com sua cinemática. A definição do mapa utilizado, da posição inicial, da forma de informar o destino e das modificações realizadas no algoritmo A* pertence à implementação deste trabalho e, por isso, é apresentada no Capítulo~\ref{cap:materiais_metodos}.

\chapter{Materiais e Métodos}
\label{cap:materiais_metodos}

Este capítulo descreve, de maneira detalhada, os materiais empregados e os procedimentos metodológicos adotados para o desenvolvimento do protótipo de robô autônomo proposto. A escolha criteriosa dos componentes eletrônicos, sensores e atuadores foi orientada pelas necessidades do sistema, levando em consideração fatores como precisão, custo, disponibilidade e compatibilidade com a plataforma de desenvolvimento utilizada.

São apresentados o ambiente de desenvolvimento de software, as bibliotecas utilizadas, os recursos computacionais embarcados, bem como a lógica de controle implementada no microcontrolador. A metodologia abrange também a integração dos sensores, o controle dos motores, o modelo de mapeamento em grid e a abordagem utilizada para planejamento de rotas.

\section{Arquitetura do Sistema e Prototipagem de Hardware}
\label{sec:arquitetura_sistema}

A arquitetura do sistema foi definida com o objetivo de integrar, de maneira modular, os componentes de sensoriamento, processamento, atuação, alimentação elétrica e interface com o usuário necessários para o funcionamento autônomo do robô móvel. Essa organização permite compreender o sistema não apenas como um conjunto de componentes eletrônicos isolados, mas como uma estrutura embarcada integrada, na qual os dados coletados pelos sensores são processados pelo microcontrolador e convertidos em comandos de controle para os motores.

A Figura~\ref{fig:arquitetura_sistema} apresenta a arquitetura geral adotada no projeto, destacando os principais módulos utilizados e os fluxos de dados, controle e alimentação elétrica entre eles.

\begin{figure}[ht]
	\centering
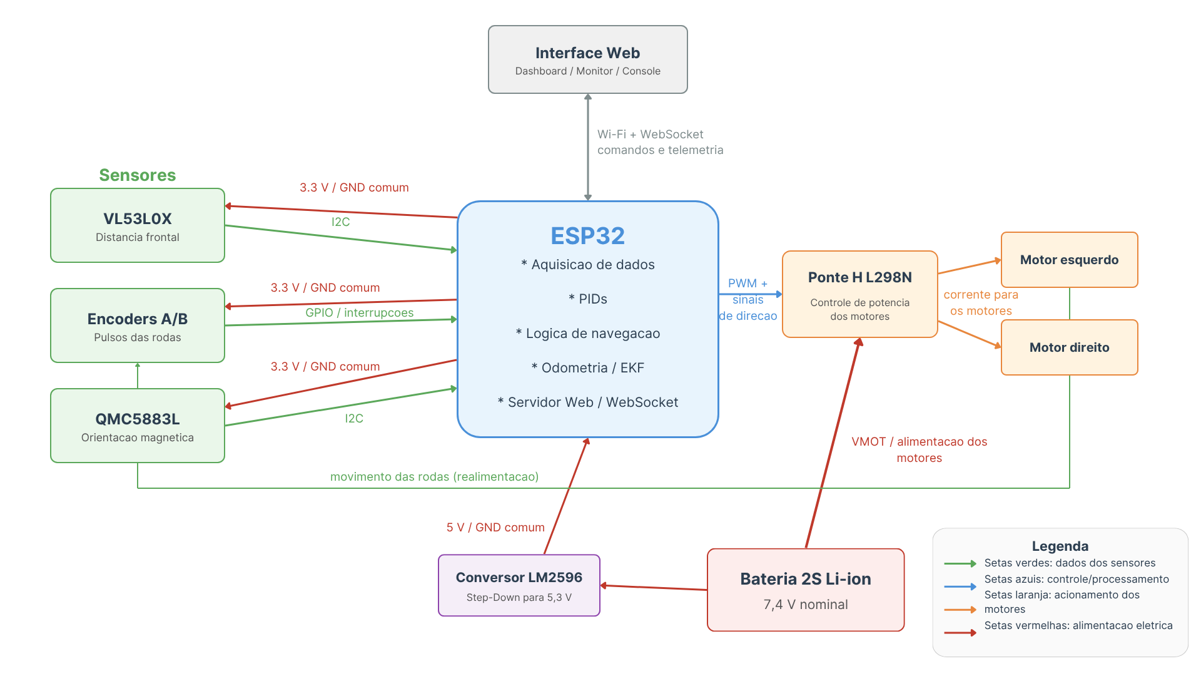
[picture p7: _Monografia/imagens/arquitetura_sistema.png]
	
	\caption{Arquitetura geral do sistema robótico embarcado.}
	\label{fig:arquitetura_sistema}
\end{figure}

Conforme ilustrado na Figura~\ref{fig:arquitetura_sistema}, o ESP32 atua como unidade central de processamento do robô. Esse microcontrolador é responsável pela aquisição dos dados dos sensores, pelo tratamento das leituras recebidas, pela execução da lógica de navegação, pelo controle dos motores e pela comunicação com a interface web. A escolha do ESP32 está relacionada à sua capacidade de processamento, à disponibilidade de interfaces de comunicação, ao suporte a interrupções para leitura dos encoders e à conectividade Wi-Fi integrada, características discutidas na fundamentação teórica e aproveitadas diretamente na implementação do sistema.

O módulo de sensoriamento é composto principalmente pelos encoders ópticos, pelo sensor de distância VL53L0X e pelo magnetômetro QMC5883L. Os encoders fornecem pulsos associados à rotação das rodas, permitindo estimar o deslocamento do robô, calcular a odometria e controlar os movimentos lineares e angulares. O sensor VL53L0X, baseado em tecnologia \textit{Time-of-Flight}, é utilizado para medir a distância frontal e identificar obstáculos durante a navegação. Já o QMC5883L fornece uma referência auxiliar de orientação magnética no plano horizontal, sendo empregado para estimativa do \textit{heading} quando suas leituras apresentam estabilidade suficiente.

A partir das informações sensoriais, o ESP32 executa rotinas de controle e decisão, incluindo controladores PID, lógica de navegação em grid, planejamento de movimento entre células, monitoramento de obstáculos e atualização da posição estimada do robô. Essas informações são utilizadas para gerar sinais de controle enviados ao módulo Ponte H L298N. A Ponte H recebe sinais digitais e PWM do ESP32 e realiza o acionamento elétrico dos motores de corrente contínua, permitindo o controle independente dos lados esquerdo e direito do robô.

A estrutura física do robô é baseada em uma plataforma de quatro rodas acionadas por motores de corrente contínua. Cada lado possui dois motores conectados em paralelo, formando dois conjuntos de tração: um conjunto esquerdo e um conjunto direito. Essa configuração permite a locomoção diferencial do robô, possibilitando movimentos de avanço, ré e rotação sobre o próprio eixo. Os motores frontais são equipados com encoders, utilizados como principal fonte de realimentação para o controle de deslocamento e rotação.

O sistema de alimentação foi organizado de forma a separar a alimentação de potência dos motores da alimentação lógica dos circuitos de controle e sensoriamento. A bateria Li-ion 2S, com tensão nominal de $7{,}4\,\text{V}$, alimenta diretamente a Ponte H L298N, responsável pelo fornecimento de corrente aos motores. Em paralelo, a mesma bateria alimenta um conversor regulador LM2596, responsável por fornecer uma tensão regulada de $5\,\text{V}$ para o ESP32 e os sensores. Todos os módulos compartilham uma referência comum de GND, condição necessária para o funcionamento adequado dos sinais de controle e comunicação entre os componentes.

A interface com o usuário é realizada por meio de uma interface web embarcada no ESP32, acessível via rede Wi-Fi local. Essa interface permite enviar comandos ao robô, selecionar destinos no mapa, acompanhar a telemetria, visualizar leituras dos sensores, observar a pose estimada do robô e consultar mensagens de registro do sistema. A troca de informações entre a interface e o microcontrolador ocorre por meio de WebSockets e mensagens em formato JSON, permitindo comunicação bidirecional em tempo real.

Dessa forma, a arquitetura adotada estabelece um ciclo de realimentação entre sensoriamento, processamento e atuação. Os sensores informam o estado físico do robô e do ambiente, o ESP32 processa essas informações e define as ações de controle, a Ponte H converte os comandos em acionamento elétrico dos motores, e a interface web permite o monitoramento e a interação com o sistema durante os testes.

\subsection{Prototipagem e Ajustes de Hardware}
\label{sec:prototipagem_ajustes}

Após a definição da arquitetura geral, os componentes foram organizados em uma montagem de prototipagem para validar, de forma prática, a integração entre os módulos apresentados na fundamentação teórica. Essa etapa permitiu verificar a compatibilidade entre o ESP32, a Ponte H L298N, os motores DC, os encoders, o sensor VL53L0X, o magnetômetro QMC5883L, o conversor LM2596 e o sistema de alimentação por bateria.

A Figura~\ref{fig:protoboard_model_v2} apresenta a organização física revisada dos componentes em ambiente de prototipação. Essa representação foi utilizada como referência para a montagem do protótipo, evidenciando a disposição dos módulos principais, das conexões de alimentação e dos sinais de controle.

\begin{figure}[ht]
	\centering
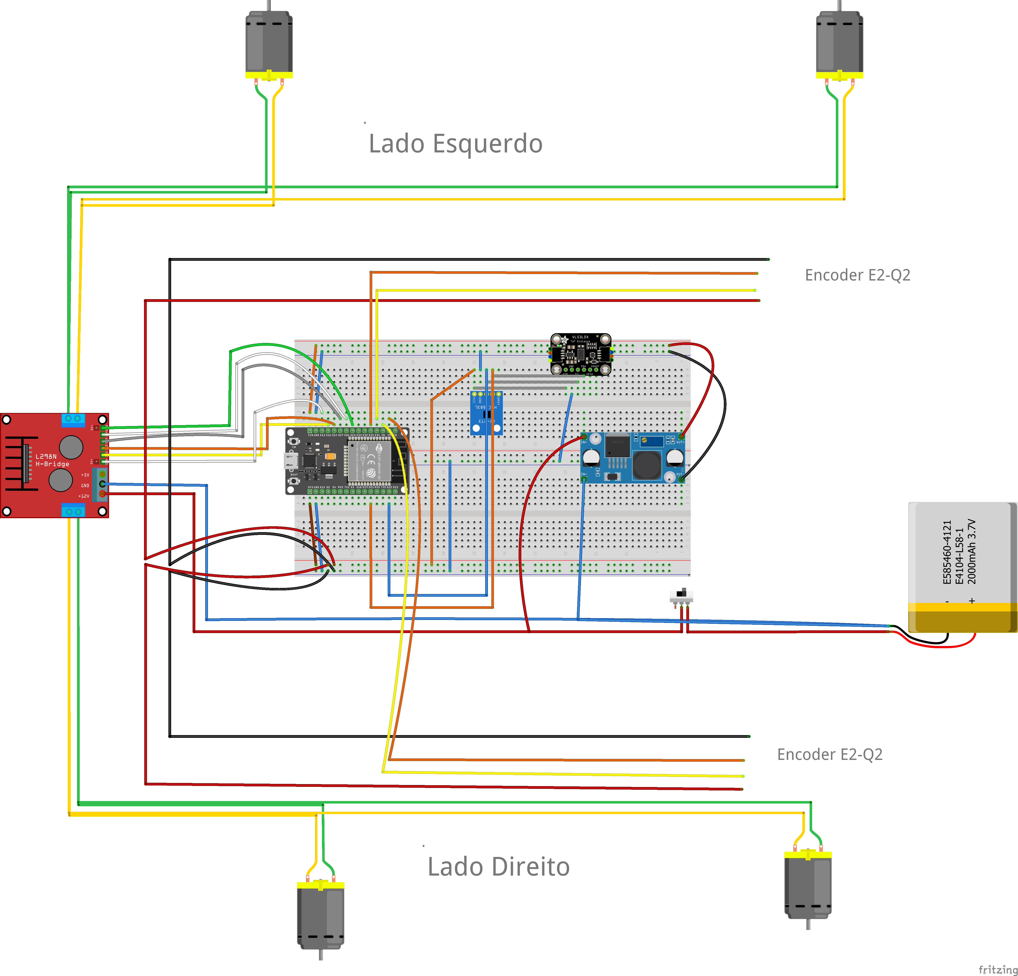
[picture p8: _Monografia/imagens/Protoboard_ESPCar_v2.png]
	
	\caption{Organização revisada dos componentes utilizados no protótipo do robô móvel.}
	\small Modelo desenvolvido com auxílio da ferramenta \href{https://fritzing.org/}{Fritzing.org}.
	\label{fig:protoboard_model_v2}
\end{figure}

Durante os testes de integração, foram realizados ajustes na disposição dos componentes e no roteamento das conexões, buscando reduzir desconexões, facilitar a manutenção e melhorar a estabilidade elétrica do sistema durante a movimentação do robô. A separação entre a alimentação dos motores e a alimentação do ESP32 e sensores foi um ponto importante dessa etapa, pois os motores podem introduzir ruídos e quedas de tensão capazes de afetar o funcionamento dos circuitos lógicos.

Também foram observadas limitações práticas associadas ao uso do magnetômetro QMC5883L. Embora o sensor tenha sido incorporado como referência auxiliar de orientação, os testes indicaram que suas leituras podem sofrer interferências causadas por motores, correntes elétricas, fios de alimentação e componentes metálicos próximos. Por esse motivo, os encoders permaneceram como principal fonte de informação para controle de deslocamento e rotação, enquanto o QMC5883L foi tratado como uma referência complementar, utilizada apenas quando suas leituras apresentavam estabilidade suficiente.

Na implementação do firmware, o \textit{heading} foi calculado a partir das componentes magnéticas dos eixos X e Y, com uso de offset para definição do zero angular e normalização da leitura. Também foram aplicados critérios de rejeição para descartar variações incompatíveis com a movimentação esperada. Essas decisões pertencem à metodologia de integração do sensor no protótipo, enquanto os efeitos observados durante os testes são discutidos no Capítulo~\ref{chap:resultados}.

A etapa de prototipagem, portanto, permitiu consolidar a arquitetura de hardware utilizada no projeto, aproximando os conceitos discutidos na fundamentação teórica da implementação física do robô. Além disso, os ajustes realizados nessa fase contribuíram diretamente para a execução dos testes de navegação em grid, deslocamento entre células, detecção de obstáculos, controle por encoders e monitoramento remoto por interface web.

O circuito foi montado sobre um chassi de acrílico, mostrado na Figura~\ref{fig:robo_original}. As rodas são acionadas em duplas, direita e esquerda, por dois canais independentes da ponte H. Dessa forma, um robô com rodas diferenciais é implementado.

\begin{figure}[ht]
	\centering
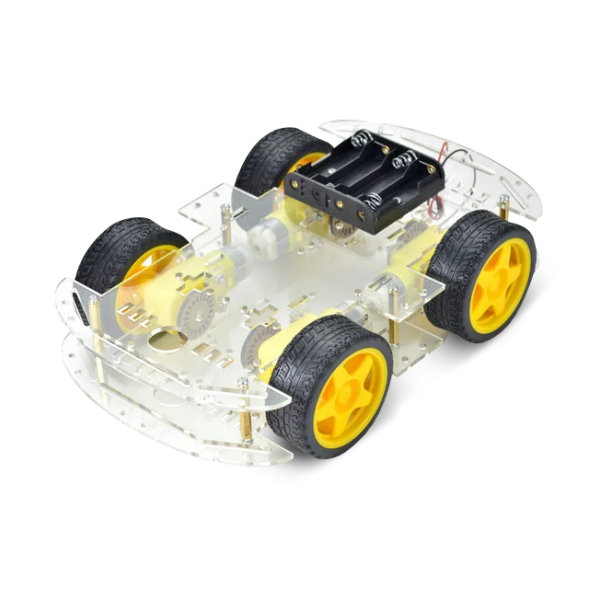
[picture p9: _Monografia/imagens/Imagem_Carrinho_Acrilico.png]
	
	\caption{Conjunto original do carrinho, com chassi de acrílico, motores DC e Porta 4 pilhas.}
	\small\textit{Fonte: \href{https://www.robocore.net/kit-plataforma-robotica/kit-chassi-4wd-com-motores-e-rodas/}{Robocore.net}}
	\label{fig:robo_original}
\end{figure}

Concluída a etapa de integração, o protótipo físico foi utilizado nos ensaios descritos neste capítulo. As fotografias e a discussão da montagem final são apresentadas no Capítulo~\ref{chap:resultados}, na Seção~\ref{sec:resultados_montagem_final}, pois constituem resultados do desenvolvimento realizado.

\section{Integração e Montagem Mecânica do Robô}

O chassi do robô foi projetado e montado utilizando materiais leves e resistentes, priorizando a eficiência energética e a mobilidade. As rodas foram acopladas a motores de corrente contínua equipados com encoders rotativos, permitindo o controle preciso da velocidade e do deslocamento, fundamentais para a implementação de algoritmos de navegação autônoma.

Os sensores foram posicionados de acordo com suas funções no sistema. O sensor ToF foi colocado na região frontal do chassi para realizar medições no sentido de deslocamento. O magnetômetro QMC5883L foi instalado buscando o maior afastamento possível da ponte H, dos motores, da bateria e dos cabos de corrente elevada. A fiação foi organizada e fixada para facilitar a manutenção, reduzir movimentos dos conectores e diminuir a exposição do sensor magnético às fontes de interferência presentes no protótipo.

A alimentação do sistema é fornecida por uma bateria de íon-lítio (Li-ion) 2S, escolhida por sua densidade energética e capacidade de recarga. A distribuição de energia foi organizada com conector XT60, chave SS12F46, regulador LM2596 e módulo L298N. A versão avaliada permaneceu montada sobre protoboard e conexões por jumpers, configuração utilizada durante os ensaios experimentais.

\section{Ambiente de Desenvolvimento}
\label{sec:dev_ide}

O desenvolvimento do \textit{firmware} embarcado do robô autônomo foi realizado no \textit{Visual Studio Code}, utilizando a extensão PlatformIO e o \textit{framework} Arduino para ESP32. Essa escolha permitiu organizar o projeto em uma estrutura modular, com separação entre código-fonte, bibliotecas customizadas, arquivos de interface web e configurações de compilação.

O uso do PlatformIO facilitou o gerenciamento das dependências, a configuração da placa ESP32, a compilação do projeto e o envio dos arquivos estáticos da interface para a memória flash do microcontrolador. Como a interface web é composta por arquivos HTML, CSS e JavaScript, o suporte a sistemas de arquivos embarcados, como SPIFFS, tornou-se parte importante do fluxo de desenvolvimento.

Além da organização do código, o ambiente também favoreceu a depuração incremental. Durante o desenvolvimento, logs via serial e via interface web foram utilizados para acompanhar leituras dos encoders, estado do magnetômetro, detecção de obstáculos, planejamento de rota, execução de células e calibração de curvas.

\subsection{Execução concorrente com FreeRTOS}

Embora o desenvolvimento do \textit{firmware} tenha sido realizado com o \textit{framework} Arduino para ESP32, a execução das rotinas no microcontrolador ocorre sobre a infraestrutura do FreeRTOS, conforme discutido na Seção~\ref{sec:freertos}. No projeto, essa característica foi explorada para organizar partes do sistema em tarefas concorrentes, separando rotinas com responsabilidades distintas, como leitura de sensores, atualização de telemetria, comunicação com a interface web e controle de movimentação.

Essa organização foi importante para manter a responsividade do robô durante a navegação. Em um sistema móvel autônomo, o controle dos motores e a leitura dos sensores não podem depender exclusivamente de uma execução sequencial bloqueante, pois atrasos em uma rotina poderiam comprometer a detecção de obstáculos, o envio de dados à interface ou a atualização da posição estimada. Assim, a divisão em tarefas contribuiu para que o sistema continuasse processando informações de sensoriamento e comunicação enquanto executava comandos de movimento.

No contexto deste trabalho, o uso do FreeRTOS favoreceu a separação entre aquisição de dados, controle de baixo nível, comunicação com o usuário e registro de eventos. Essa abordagem também facilitou os testes incrementais do sistema, uma vez que permitiu isolar responsabilidades do \textit{firmware} e acompanhar o comportamento de cada módulo durante a execução experimental.

\subsection{Bibliotecas Utilizadas}

Para a implementação das funcionalidades do sistema embarcado, foram utilizadas bibliotecas tanto nativas quanto de terceiros. Essas bibliotecas atuaram na abstração de protocolos de comunicação, controle de hardware, gerenciamento de rede e suporte à interface web. A Tabela~\ref{tab:libs_oficiais} apresenta as principais bibliotecas utilizadas e suas respectivas finalidades.

\begin{table}[ht]
	\centering
	\caption{Bibliotecas externas e oficiais utilizadas no projeto}
	\label{tab:libs_oficiais}
	\begin{tabular}{|p{5cm}|p{10cm}|}
		\hline
		\textbf{Biblioteca} & \textbf{Finalidade} \\
		\hline
		\texttt{Wire.h} & Comunicação I2C com sensores como QMC5883L e VL53L0X. \\
		\texttt{Arduino.h} & Funções básicas de controle de pinos, temporização e compatibilidade com o ecossistema Arduino. \\
		\texttt{FreeRTOS} & Infraestrutura de execução concorrente disponível no ESP32, utilizada para criação e organização de tarefas do sistema embarcado. \\
		\texttt{math.h} & Cálculos matemáticos, incluindo trigonometria e manipulação de ponto flutuante. \\
		\texttt{ArduinoJson.h} & Criação e interpretação de objetos JSON para comunicação com a interface web. \\
		\texttt{WiFi.h} & Conexão do ESP32 à rede Wi-Fi local. \\
		\texttt{ESPAsyncWebServer.h} & Criação de servidor web assíncrono, com suporte a múltiplas conexões simultâneas. \\
		\texttt{SPIFFS.h} & Leitura e escrita dos arquivos da interface web no sistema de arquivos embarcado. \\
		\texttt{Adafruit\_VL53L0X.h} & Controle do sensor de distância VL53L0X. \\
		\texttt{Adafruit\_Sensor.h} & Interface comum para sensores Adafruit. \\
		\texttt{QMC5883L\_Custom} & Biblioteca própria para configuração, leitura e filtragem do magnetômetro QMC5883L. \\
		\hline
	\end{tabular}
\end{table}

Durante as primeiras versões do sistema, foi avaliada a utilização de resolução local de nome por DNS/mDNS, de modo que a interface web pudesse ser acessada por um endereço amigável na rede local. Entretanto, nos testes práticos, esse recurso não se mostrou suficientemente útil ou consistente em diferentes cenários de conexão, especialmente quando o acesso era realizado por meio de rede compartilhada pelo roteador do celular. Por esse motivo, a abordagem foi removida da versão final, optando-se pelo acesso direto ao endereço IP atribuído ao ESP32 pelo roteador. Essa decisão simplificou a conexão com a interface web e reduziu uma dependência adicional da camada de rede.

\subsection{Bibliotecas Customizadas}

A fim de modularizar o sistema, reduzir a complexidade do código-fonte principal e facilitar a manutenção e reuso de funcionalidades, diversas bibliotecas personalizadas foram desenvolvidas especificamente para o projeto. Essas bibliotecas encapsulam funcionalidades críticas como controle de motores, leitura de sensores, filtragem de sinais e gerenciamento de energia. A seguir, são listadas as bibliotecas customizadas implementadas:

\begin{itemize}
		\item \textbf{PID}: Implementa o algoritmo de controle Proporcional–Integral–Derivativo, permitindo múltiplas instâncias com parâmetros distintos. Essencial para o controle de velocidade dos motores com base em dados de odometria.

		\item \textbf{Filtros e validações}: Realizam suavização e validação de leituras, incluindo rejeição de amostras anômalas do QMC5883L e de saltos incompatíveis dos encoders.

		\item \textbf{Encoder}: Abstrai a leitura dos encoders das rodas, permitindo o cálculo da velocidade, do deslocamento linear e da rotação estimada durante curvas.

		\item \textbf{Monitoramento e logs}: Agrupa rotinas de diagnóstico utilizadas para registrar telemetria, estado de navegação, erros de sensores e eventos relevantes para calibração.

		\item \textbf{VL53L0X (custom)}: Estende a biblioteca oficial com lógica adicional para detecção de obstáculos com limiares configuráveis.

		\item \textbf{QMC5883L (custom)}: Integra a configuração do magnetômetro, a leitura dos eixos X, Y e Z, o cálculo de \textit{heading}, a aplicação de offset angular e a rejeição de leituras instáveis.

		\item \textbf{Motor}: Controla individualmente cada motor, centralizando a lógica de PWM, leitura de encoder e resposta ao PID.

		\item \textbf{PonteH}: Biblioteca de alto nível responsável pelo controle simultâneo dos motores do robô. Gerencia comandos de movimento, como deslocamento linear, curvas e manobras de rotação no próprio eixo. Também integra informações de sensores para ajuste de trajetória e comunicação em tempo real com a interface web.
\end{itemize}

A combinação dessas bibliotecas permitiu uma separação clara entre as responsabilidades de cada módulo do sistema, promovendo um desenvolvimento mais organizado, escalável e de fácil manutenção.

\section{Estratégias de Controle e Navegação}
\label{sec:controle_navegacao}

A navegação autônoma do robô é composta por um conjunto de estratégias interligadas que envolvem sensoriamento, controle de movimento, estimativa de posição e planejamento de trajetória. O sistema foi projetado para operar de forma reativa e deliberativa, ou seja, combinando a coleta contínua de dados do ambiente com decisões de alto nível baseadas em um mapa interno.

\subsection{Odometria e Estimativa de Posição}

A estimativa de deslocamento do robô é realizada por meio da odometria diferencial, utilizando a contagem de pulsos dos encoders ópticos instalados nas rodas frontais. Esses dados são processados para determinar a distância percorrida por cada lado do robô e a variação angular ao longo do tempo. Como o robô utiliza uma configuração de tração diferencial, na qual os lados esquerdo e direito podem ser acionados de forma independente, a pose do robô pode ser estimada a partir da diferença entre os deslocamentos das rodas.

Inicialmente, os pulsos acumulados pelos encoders são convertidos em deslocamento linear. Considerando uma roda de raio $r$, uma resolução de encoder de $N$ pulsos por volta e variações de contagem $\Delta p_L$ e $\Delta p_R$ para as rodas esquerda e direita, respectivamente, os deslocamentos lineares de cada lado são calculados pelas Equações~\ref{eq:deslocamento_roda_esquerda} e~\ref{eq:deslocamento_roda_direita}:
\begin{equation}
	\Delta s_L = \frac{2\pi r}{N}\Delta p_L
	\label{eq:deslocamento_roda_esquerda}
\end{equation}
\begin{equation}
	\Delta s_R = \frac{2\pi r}{N}\Delta p_R
	\label{eq:deslocamento_roda_direita}
\end{equation}
Em seguida, o deslocamento médio do robô e sua variação angular são obtidos, respectivamente, pelas Equações~\ref{eq:deslocamento_medio} e~\ref{eq:variacao_angular_odometria}, de acordo com o modelo cinemático diferencial:
\begin{equation}
	\Delta s = \frac{\Delta s_R + \Delta s_L}{2}
	\label{eq:deslocamento_medio}
\end{equation}
\begin{equation}
	\Delta \theta = \frac{\Delta s_R - \Delta s_L}{b}
	\label{eq:variacao_angular_odometria}
\end{equation}

em que $b$ representa a distância entre as rodas ou, de forma equivalente, a largura efetiva entre os pontos de contato dos lados esquerdo e direito do robô. Com esses valores, a pose do robô no instante $k$ pode ser atualizada a partir da pose anterior $(x_{k-1}, y_{k-1}, \theta_{k-1})$, conforme, novamente seguindo a cinemática de um robô diferencial,

\begin{equation}
	x_k = x_{k-1} + \Delta s \cos\left(\theta_{k-1} + \frac{\Delta \theta}{2}\right)
	\label{eq:pose_x_odometria}
\end{equation}

\begin{equation}
	y_k = y_{k-1} + \Delta s \sin\left(\theta_{k-1} + \frac{\Delta \theta}{2}\right)
	\label{eq:pose_y_odometria}
\end{equation}

\begin{equation}
	\theta_k = \theta_{k-1} + \Delta \theta
	\label{eq:pose_theta_odometria}
\end{equation}

Essa formulação permite atualizar incrementalmente a posição e a orientação do robô a cada nova leitura dos encoders. O termo $\theta$ representa a orientação do robô no plano, enquanto $x$ e $y$ indicam sua posição estimada em relação ao referencial adotado no mapa. No contexto deste trabalho, essa estimativa é utilizada tanto para acompanhar o deslocamento físico do robô quanto para relacionar sua posição contínua com as células discretas do mapa em gridPor fim, a velocidade angular e linear do robô podem ser calculados a partir de \ref{eq:pose_x_odometria} e \ref{eq:pose_y_odometria}, sendo dadas por % ! COLOCAR EQUAÇÃO AQUI ! %.

Para a aplicação prática dessas equações, é necessário definir alguns parâmetros físicos do protótipo. Esses parâmetros relacionam a movimentação real do robô com os valores obtidos pelos encoders e, portanto, influenciam diretamente a estimativa de pose. No presente trabalho, foram considerados os seguintes pontos de medição:

\begin{itemize}
	\item \textbf{Raio da roda ($r = 325\,\text{mm}$):} corresponde à distância entre o centro da roda e sua extremidade externa. Esse valor é utilizado para converter a rotação medida pelo encoder em deslocamento linear.

	\item \textbf{Diâmetro da roda ($D = 650\,\text{mm}$):} corresponde à distância total entre duas extremidades opostas da roda, passando pelo centro. Como $D = 2r$, esse valor também pode ser utilizado para determinar o perímetro da roda, dado por $C = \pi D$.

	\item \textbf{Distância entre rodas ou largura efetiva da base ($b = 150\,\text{mm}$):} corresponde à distância entre os pontos de contato das rodas esquerda e direita com o solo. Esse parâmetro é utilizado no cálculo da variação angular $\Delta \theta$, sendo essencial para estimar corretamente as rotações do robô.

	\item \textbf{Comprimento total do robô ($L = 26\,\text{cm}$):} corresponde à dimensão longitudinal do chassi, medida da extremidade frontal até a extremidade traseira. Essa medida é relevante para verificar se o robô cabe dentro de uma célula do grid e para avaliar sua margem de manobra durante a navegação.

	\item \textbf{Largura total do robô ($W = 15\,\text{cm}$):} corresponde à dimensão transversal do chassi, medida de uma lateral à outra. Essa medida permite comparar a ocupação física do robô com o tamanho das células do mapa, definidas neste trabalho como $30\,\text{cm} \times 30\,\text{cm}$.

	\item \textbf{Distância entre o sensor frontal e a dianteira do robô ($d_s = 5\,\text{cm}$):} corresponde ao posicionamento do sensor VL53L0X em relação à extremidade frontal do chassi. Esse valor é importante para interpretar corretamente as leituras de distância, pois o sensor mede a distância a partir de sua própria posição, e não necessariamente a partir da frente física do robô.

	\item \textbf{Altura aproximada do sensor frontal ($h_s = 7\,\text{cm}$):} corresponde à altura do VL53L0X em relação ao solo. Essa medida influencia a detecção de obstáculos, principalmente quando os objetos possuem alturas diferentes ou não interceptam diretamente o feixe de medição do sensor.

	\item \textbf{Resolução dos encoders ($N = 20\ \text{pulsos/rev}$):} corresponde ao número de pulsos gerados por volta da roda ou do eixo monitorado. Esse valor é necessário para converter a contagem de pulsos em deslocamento linear.
\end{itemize}

Essas dimensões permitem relacionar o modelo matemático de odometria com a geometria real do robô e definir os parâmetros empregados na conversão dos pulsos dos encoders em deslocamento linear e variação angular. A comparação entre o tamanho físico do protótipo e as células do grid é apresentada na metodologia dos testes, onde são definidas as dimensões do ambiente experimental.

A odometria, apesar de eficiente em curtos intervalos de tempo, sofre com acúmulo de erro ao longo de percursos maiores. Esse erro pode ser causado por deslizamento das rodas, folgas mecânicas, irregularidades do piso, diferenças entre motores e ruídos nas leituras dos encoders. No protótipo atual, os encoders são utilizados como fonte primária para medição de deslocamento e controle de rotação, pois apresentaram maior consistência prática para a execução dos movimentos entre células do grid.

O magnetômetro QMC5883L é empregado como referência auxiliar de orientação, porém suas leituras são filtradas e rejeitadas quando apresentam saltos incompatíveis com a movimentação esperada. Essa estratégia evita que interferências magnéticas causadas por motores, correntes elétricas ou componentes metálicos próximos afetem diretamente a estimativa da pose do robô. Dessa forma, a odometria baseada nos encoders permanece como base principal da localização, enquanto o sensor magnético atua apenas como informação complementar quando suas medições são consideradas estáveis.

\subsection{Controle de Movimento via PID}

O controle de movimento do robô é implementado por meio de controladores PID, utilizados para reduzir o erro entre uma grandeza de referência e a grandeza efetivamente medida pelo sistema. No protótipo desenvolvido, o controle foi organizado em duas malhas principais: uma malha de velocidade, associada ao controle dos motores a partir dos encoders, e uma malha de direção, associada à correção da orientação do robô durante deslocamentos lineares e rotações.

A malha de velocidade atua sobre cada lado do robô de forma independente. Com base nos dados dos encoders, o sistema estima a velocidade angular das rodas e ajusta dinamicamente a largura de pulso (PWM) aplicada aos motores por meio da Ponte H L298N. Essa estratégia permite compensar diferenças mecânicas entre os motores, variações de carga, atrito e pequenas assimetrias na montagem. A Figura~\ref{fig:pid_velocidade} apresenta o diagrama simplificado dessa malha de controle.

\begin{figure}[ht]
	\centering
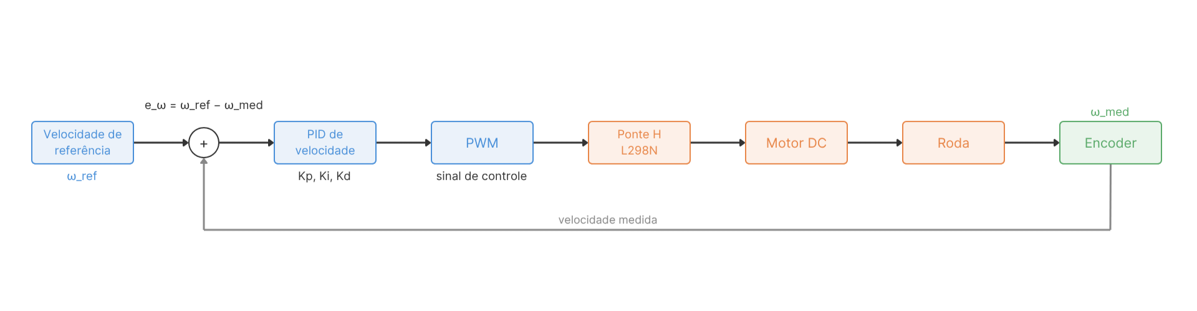
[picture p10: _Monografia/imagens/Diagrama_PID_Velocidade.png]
	
	\caption{Diagrama simplificado da malha de controle de velocidade dos motores.}
	\label{fig:pid_velocidade}
\end{figure}

Para cada motor, o erro de velocidade é definido pela Equação~\ref{eq:erro_velocidade_pid}, como a diferença entre a velocidade angular de referência e a velocidade angular medida pelos encoders:
\begin{equation}
	e_{\omega}(t) = \omega_{\text{ref}}(t) - \omega_{\text{med}}(t)
	\label{eq:erro_velocidade_pid}
\end{equation}

em que $\omega_{\text{ref}}(t)$ representa a velocidade angular desejada e $\omega_{\text{med}}(t)$ representa a velocidade angular estimada a partir dos pulsos dos encoders. A ação de controle PID correspondente é apresentada na Equação~\ref{eq:pid_velocidade}:
\begin{equation}
	u_{\omega}(t) =
	K_{p\omega} e_{\omega}(t)
	+ K_{i\omega} \int_0^{t}e_{\omega}(\tau)d\tau
	+ K_{d\omega}\frac{de_{\omega}(t)}{dt}
	\label{eq:pid_velocidade}
\end{equation}

em que $K_{p\omega}$, $K_{i\omega}$ e $K_{d\omega}$ representam, respectivamente, os ganhos proporcional, integral e derivativo da malha de velocidade. O sinal $u_{\omega}(t)$ é convertido em um valor de PWM aplicado ao motor correspondente.

Além da malha de velocidade, o sistema utiliza uma malha de direção para corrigir desvios de orientação. Essa malha compara a orientação de referência do robô com a orientação estimada durante o movimento, produzindo uma correção angular que é distribuída entre os lados esquerdo e direito. A Figura~\ref{fig:pid_direcao} apresenta o diagrama simplificado dessa malha.

\begin{figure}[ht]
	\centering
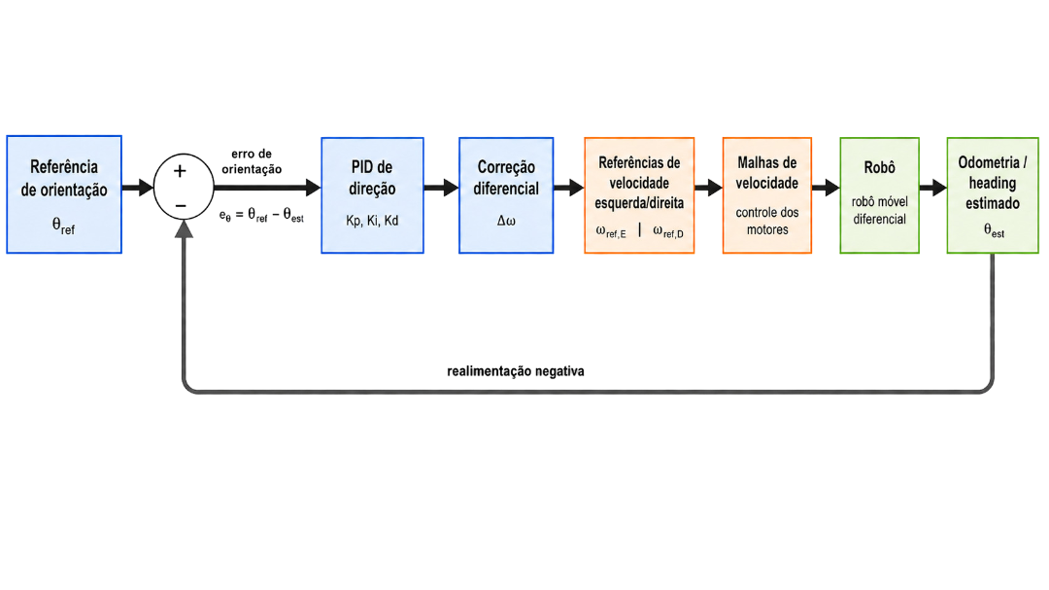
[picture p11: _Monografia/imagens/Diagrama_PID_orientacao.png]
	
	\caption{Diagrama simplificado da malha de controle de direção do robô.}
	\label{fig:pid_direcao}
\end{figure}

O erro angular é calculado pela Equação~\ref{eq:erro_direcao_pid_bruto}, a partir da diferença entre a orientação desejada e a orientação estimada do robô:
\begin{equation}
	e_{\theta}(t) = \theta_{\text{ref}}(t) - \theta_{\text{med}}(t)
	\label{eq:erro_direcao_pid_bruto}
\end{equation}

Como a orientação é uma grandeza angular, esse erro deve ser normalizado para evitar ambiguidades entre ângulos equivalentes. O erro efetivamente utilizado pelo controlador é definido na Equação~\ref{eq:erro_direcao_pid}:
\begin{equation}
	e_{\theta}^{*}(t) =
	\mathrm{norm}\left(\theta_{\text{ref}}(t) - \theta_{\text{med}}(t)\right)
	\label{eq:erro_direcao_pid}
\end{equation}
em que $\mathrm{norm}(\cdot)$ representa a normalização do erro angular para o intervalo $[-\pi,\pi]$. A ação de controle da malha de direção é definida pela Equação~\ref{eq:pid_direcao}:
\begin{equation}
	u_{\theta}(t) =
	K_{p\theta} e_{\theta}^{*}(t)
	+ K_{i\theta} \int_0^{t}e_{\theta}^{*}(\tau)d\tau
	+ K_{d\theta}\frac{de_{\theta}^{*}(t)}{dt}
	\label{eq:pid_direcao}
\end{equation}
em que $K_{p\theta}$, $K_{i\theta}$ e $K_{d\theta}$ representam os ganhos proporcional, integral e derivativo da malha de direção. O termo $u_{\theta}(t)$ corresponde à correção angular aplicada ao movimento do robô.
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

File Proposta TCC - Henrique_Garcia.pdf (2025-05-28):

## UNIVERSIDADE FEDERAL DE SÃO PAULO Departamento de Ciência e Tecnologia

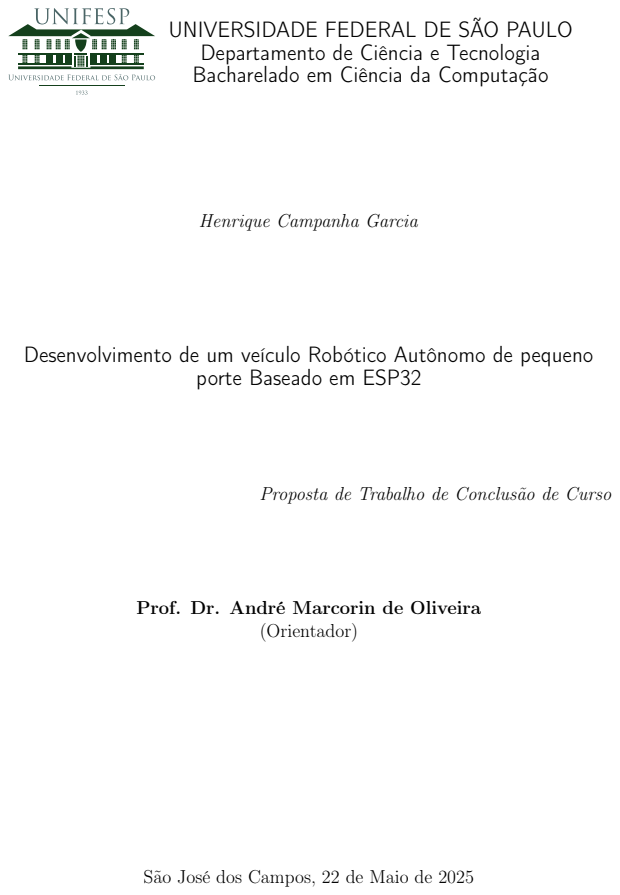
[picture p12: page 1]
(Orientador)

Bacharelado em Ciência da Computação

Henrique Campanha Garcia

Desenvolvimento de um veículo Robótico Autônomo de pequeno

porte Baseado em ESP32

Proposta de Trabalho de Conclusão de Curso

Prof. Dr. André Marcorin de Oliveira

São José dos Campos, 22 de Maio de 2025

## 1 Introdução e justificativas

A crescente evolução dos sistemas embarcados e da Internet das Coisas (IoT) tem impulsionado o desenvolvimento de soluções autônomas para aplicações cotidianas. Nesse cenário, veículos autônomos têm despertado interesse pela sua aplicabilidade em tarefas de transporte interno, contribuindo para a automação e otimização de processos, (Schilling et al., 1997).
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

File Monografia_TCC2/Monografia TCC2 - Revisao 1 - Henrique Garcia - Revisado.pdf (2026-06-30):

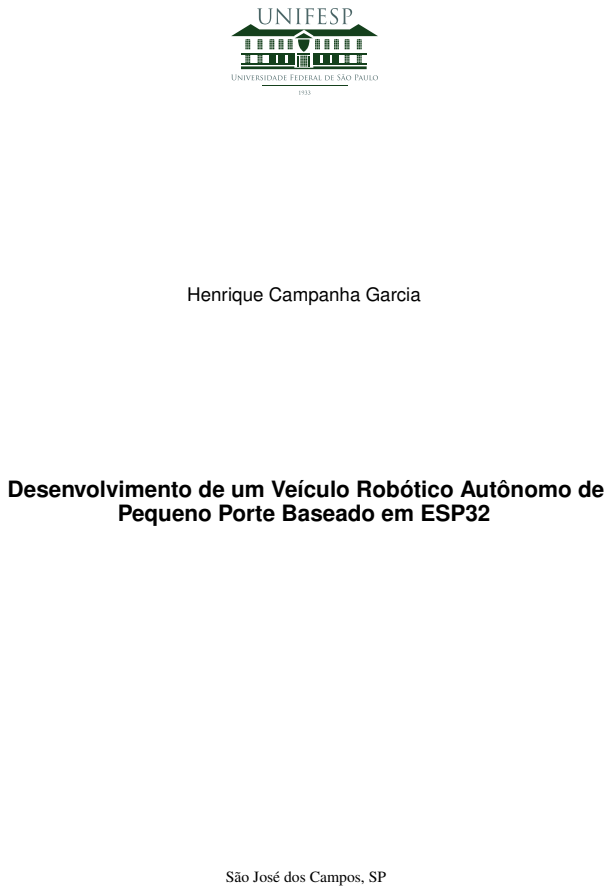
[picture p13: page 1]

Henrique Campanha Garcia

Desenvolvimento de um Veículo Robótico Autônomo de

Pequeno Porte Baseado em ESP32

São José dos Campos, SP

### Henrique Campanha Garcia

## Desenvolvimento de um Veículo Robótico Autônomo de

## Pequeno Porte Baseado em ESP32

Trabalho de conclusão de curso apresentado ao Instituto de Ciência e Tecnologia – UNIFESP, como parte das atividades para obtenção do título de Bacharel em Ciência da Computação.

Universidade Federal de São Paulo – UNIFESP

Instituto de Ciência de Tecnologia

Bacharelado em Ciência da Computação

### Orientador: Prof. Dr. André Marcorin de Oliveira

### São José dos Campos, SP

### Junho de 2026

### Henrique Campanha Garcia
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

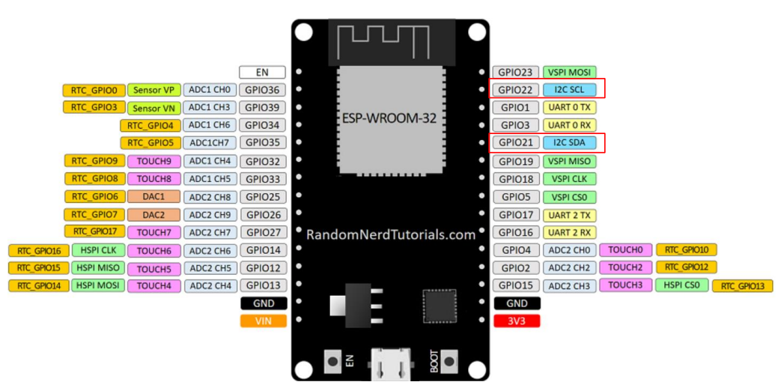
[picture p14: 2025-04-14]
ESP32_Pinout.png

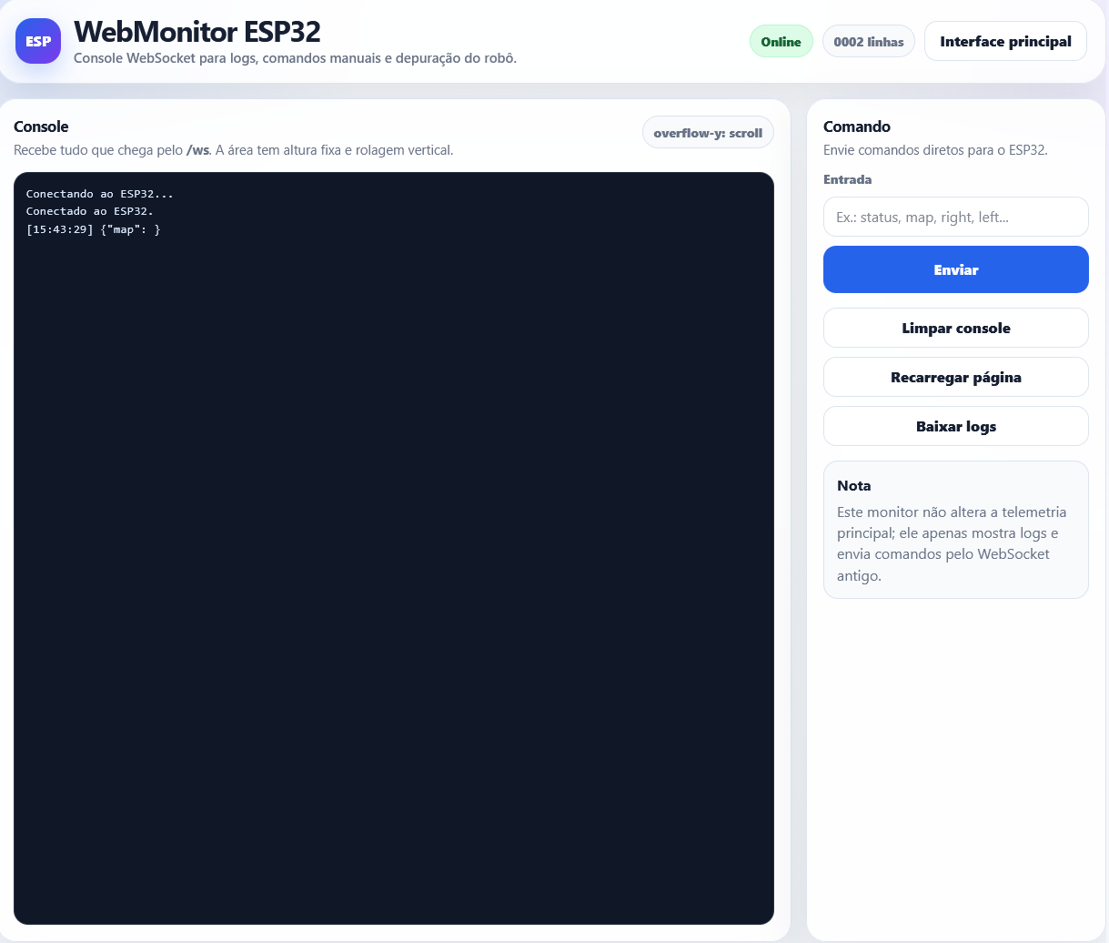
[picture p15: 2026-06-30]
_Monografia/imagens/Interface_WebTerminal.png

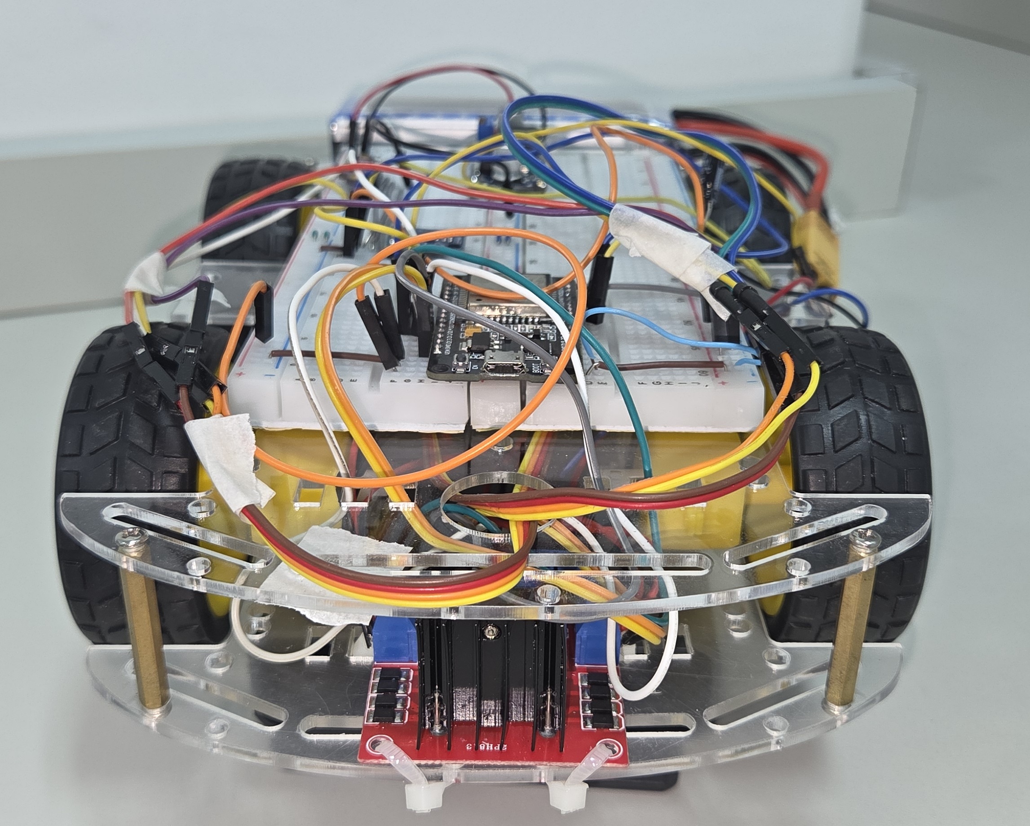
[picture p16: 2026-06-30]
_Monografia/imagens/Prototipo_Visao_Traseira_Superior.jpg

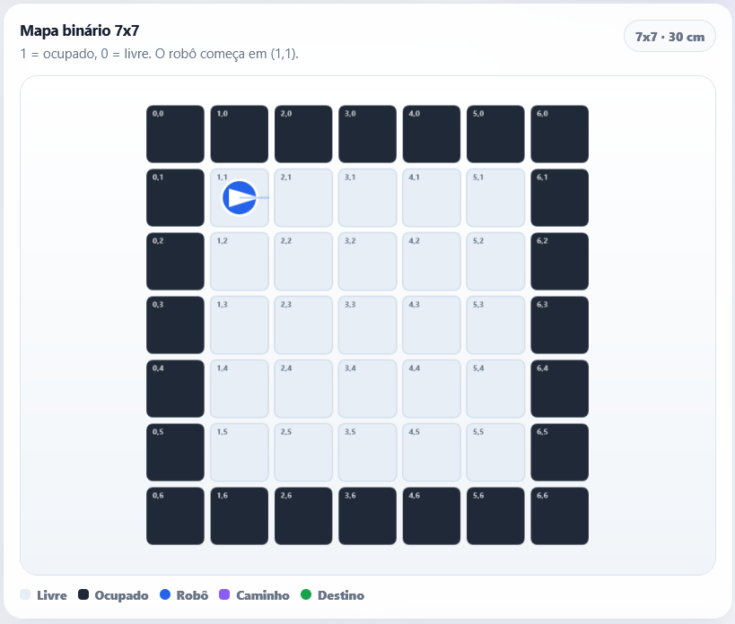
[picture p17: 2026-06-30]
_Monografia/imagens/mapa_utilizado_7x7.png

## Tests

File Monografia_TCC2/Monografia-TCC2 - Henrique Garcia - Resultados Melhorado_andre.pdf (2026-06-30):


Henrique Campanha Garcia

Desenvolvimento de um Veículo Robótico Autônomo de

Pequeno Porte Baseado em ESP32

São José dos Campos, SP

### Henrique Campanha Garcia

## Desenvolvimento de um Veículo Robótico Autônomo de

## Pequeno Porte Baseado em ESP32

Trabalho de conclusão de curso apresentado ao Instituto de Ciência e Tecnologia – UNIFESP, como parte das atividades para obtenção do título de Bacharel em Ciência da Computação.

Universidade Federal de São Paulo – UNIFESP

Instituto de Ciência de Tecnologia

Bacharelado em Ciência da Computação

### Orientador: Prof. Dr. André Marcorin de Oliveira

### São José dos Campos, SP

### Junho de 2026

### Henrique Campanha Garcia

## Desenvolvimento de um Veículo Robótico Autônomo de Pequeno Porte Baseado em ESP32

Trabalho de conclusão de curso apresentado ao Instituto de Ciência e Tecnologia – UNIFESP, como parte das atividades para obtenção do título de Bacharel em Ciência da Computação.

Prof. Dr. André Marcorin de Oliveira Orientador

Prof. Dr. Sérgio Ronaldo Barros dos Santos Convidado 1

Professor
Convidado 2

Professor
Convidado 3

### São José dos Campos, SP Junho de 2026

Dedico este trabalho ao meu orientador, cuja orientação foi essencial para o desenvolvimento deste projeto.

Seus esclarecimentos, especialmente na compreensão e aplicação dos algoritmos envolvidos, foram fundamentais para que eu pudesse superar desafios técnicos e aprofundar meus conhecimentos em áreas que antes me pareciam complexas.

Agradeço pela paciência, disponibilidade e incentivo contínuo ao longo deste processo.

Dedico este trabalho também a todos que, de alguma forma contribuíram para a realização deste projeto.

Muito obrigado.

# Agradecimentos

A realização deste trabalho foi possível graças ao apoio e à colaboração de diversas pessoas e instituições, às quais expresso minha sincera gratidão.

Em primeiro lugar, agradeço ao meu orientador, Prof. Dr. André Marcorin de Oliveira, pelo constante apoio, paciência e pelas valiosas orientações técnicas, especialmente no que diz respeito à compreensão e à implementação dos algoritmos utilizados neste projeto. Sua experiência, dedicação e disponibilidade foram fundamentais para o desenvolvimento desta pesquisa.

Estendo meus agradecimentos à Universidade Federal de São Paulo (UNIFESP), instituição de ensino reconhecida pela excelência acadêmica, pelo compromisso com a formação de profissionais éticos, críticos e preparados para os desafios da sociedade contemporânea.

Aos colegas e amigos que me acompanharam ao longo da graduação, em especial Thiago Capuano e Vinicius Matumoto, sou grato pelos diálogos construtivos, pela colaboração espontânea e, sobretudo, pela amizade que tornou essa caminhada mais leve e motivadora.

À minha família, em especial aos meus pais, Margarete e Renato Garcia, agradeço pelo

amor incondicional, incentivo constante e por acreditarem em mim mesmo diante das dificuldades. Sem o apoio de vocês, este trabalho certamente não teria se concretizado.

Por fim, agradeço a todos aqueles que, direta ou indiretamente, contribuíram para a realização deste projeto.

“Não vos amoldeis às estruturas deste mundo, mas transformai-vos pela renovação da mente, a fim de distinguir qual é a vontade de Deus: o que é bom, o que Lhe é agradável, o que é perfeito. (Bíblia Sagrada, Romanos 12, 2)

# Resumo

Este trabalho apresenta o projeto e desenvolvimento de um veículo robótico autônomo de pequeno porte, concebido para realizar tarefas de transporte de objetos em ambientes internos. O sistema é fundamentado no microcontrolador ESP32, que centraliza o processamento e a conectividade. A percepção do ambiente e a locomoção precisa são viabilizadas pela integração de múltiplos sensores e atuadores, incluindo um magnetômetro QMC5883L para referência de orientação, um sensor de distância Time-of-Flight (ToF) VL53L0X para detecção frontal de obstáculos e encoders ópticos para odometria. O controle de movimento dos motores DC é realizado por meio de uma ponte H com modulação por largura de pulso (PWM), e a estabilidade da trajetória é garantida por um algoritmo de controle Proporcional, Integral e Derivativo (PID). A autonomia de navegação é alcançada por uma estratégia híbrida que combina planejamento de rota global, utilizando o algoritmo A* sobre um mapa de grid, com um controle reativo local para desvio de obstáculos em tempo real. A interação com o usuário é realizada através de uma interface web (WebServer) embarcada, que permite a designação de destinos e o monitoramento do robô via Wi-Fi. O projeto visa entregar um protótipo funcional, de baixo custo e com arquitetura modular, servindo como uma plataforma educacional e de pesquisa em robótica móvel, sistemas embarcados e Internet das Coisas (IoT).

Palavras-chave: Robô Autônomo. ESP32. Controle PID. Navegação Robótica. Mapeamento em Grid. Sistemas Embarcados.

# Abstract

This work presents the design and development of a small-scale autonomous robotic vehicle, designed to perform object transportation tasks in indoor environments. The system is based on the ESP32 microcontroller, which centralizes processing and connectivity. Environmental perception and precise locomotion are enabled by the integration of multiple sensors and actuators, including a QMC5883L magnetometer for heading reference, a VL53L0X Time-of-Flight (ToF) distance sensor for frontal obstacle detection, and optical encoders for odometry. The motion control of the DC motors is performed using an H-bridge with Pulse Width Modulation (PWM), and trajectory stability is ensured by a Proportional, Integral, and Derivative (PID) control algorithm. Navigation autonomy is achieved through a hybrid strategy that combines global path planning, using the A* algorithm on a grid map, with local reactive control for real-time obstacle avoidance. User interaction is carried out through an embedded web interface (WebServer), which allows for destination designation and robot monitoring via Wi-Fi. The project aims to deliver a functional, low-cost prototype with a modular architecture, serving as an educational and research platform in mobile robotics, embedded systems, and the Internet of Things (IoT).

Keywords: Autonomous Robot. ESP32. PID Control. Robotic Navigation. Grid Mapping. Embedded Systems.

# Lista de ilustrações

Figura 6 – Exemplo de mapa 7x7 utilizado para validação do processo de mapeamento. . | 34
Figura 9 – Versão revisada da organização dos componentes em placa de prototipação. . | 39
Figura 11 – Exemplo de caminho traçado pelo algoritmo A* sobre um mapa de ocupação. | 46
Figura 12 – Interface web do robô mostrando o mapa 7x7, com origem no canto superior

Figura 13 – Interface web principal do robô, exibindo o mapa de ocupação, botões de con-

# Lista de abreviaturas e siglas

ADC | Conversor Analógico-Digital (Analog-to-Digital Converter)
AUV | Veículo Submerso Autônomo (Autonomous Underwater Vehicle)
DC | Corrente Contínua (Direct Current)
GPIO | Pinos de Entrada/Saída de Propósito Geral (General-Purpose Input/Output)
HTTP | Protocolo de Transferência de Hipertexto (Hypertext Transfer Protocol)
IMU | Unidade de Medição Inercial (Inertial Measurement Unit)
IoT | Internet das Coisas (Internet of Things)
IHM | Interface Homem-Máquina
I2C | Inter-Integrated Circuit (padrão de comunicação)
PID | Controlador Proporcional–Integral–Derivativo
PRM | Mapa de Rotas Probabilístico (Probabilistic Roadmap)
PWM | Modulação por Largura de Pulso (Pulse Width Modulation)
RAS | Sistemas Robóticos e Autônomos (Robotic and Autonomous Systems)
RMA | Robôs Móveis Autônomos
RTOS | Sistema Operacional de Tempo Real (Real-Time Operating System)
SLAM | Localização e Mapeamento Simultâneos (Simultaneous Localization and Map- ping)
SPI | Interface Periférica Serial (Serial Peripheral Interface)
ToF | Tempo de Voo (Time-of-Flight)
UART | Transmissor/Receptor Assíncrono Universal (Universal Asynchronous Receiver- Transmitter)
VL53L0X | Sensor ToF da STMicroelectronics
Wi-Fi | Wireless Fidelity (Tecnologia de rede sem fio)
WebServer | Servidor Web embarcado

ESP32 | Microcontrolador com Wi-Fi e Bluetooth integrados da Espressif Systems
QMC5883L | Magnetômetro digital de três eixos utilizado como referência de orientação magnética
A* | Algoritmo A-star para planejamento de caminhos

# Sumário

19

# 1 Introdução

A crescente evolução dos sistemas embarcados e da Internet das Coisas (IoT) tem impulsionado o desenvolvimento de soluções autônomas para aplicações cotidianas. Nesse cenário, veículos autônomos têm despertado interesse pela sua aplicabilidade em tarefas de transporte interno, contribuindo para a automação e otimização de processos, Schilling et al. (1997).

O campo da robótica móvel tem-se desenvolvido significativamente nas últimas décadas, especialmente com a popularização de plataformas modulares e reconfiguráveis Moubarak e Ben-Tzvi (2012) e robôs com capacidade de adaptação a ambientes complexos e dinâmicos Schilling et al. (1997). Nesse contexto, dentro da robótica, os agentes podem ser classificados de acordo com seu grau de autonomia, como por exemplo, robôs teleoperados, semi-autônomos e autônomos. Em todos esses tipos de robôs, e em especial para robôs com graus elevados de autonomia, o uso de sensores embarcados, como unidades de medição inerciais (IMUs) e sensores de distância, em conjunto com algoritmos de controle robustos, como o PID (Proporcional, Integral, Derivativa), têm sido essenciais para garantir precisão e estabilidade Parween et al. (2020).

Dentre as aplicações de sistemas robóticos autônomos, podem ser destacadas os robôs de resgate e salvamento Calisi et al. (2007), Samir et al. (2024), manutenção de submarina Lemos (2021), Nauert e Kampmann (2023), interface com seres humanos em museus Cantucci, Marini e Falcone (2024), Silva e Souza (2024), aplicações militares Studies (2021), Automate.org (2023), entre outros. Em especial, os trabalhos de Nehmzow (2012) e Schilling et al. (1997) destacam a importância de projetos didáticos e aplicáveis de veículos autônomos tanto em ambientes industriais quanto acadêmicos, reforçando a relevância de soluções acessíveis e flexíveis.

Dessa forma, este projeto visa desenvolver um veículo autônomo de pequeno porte com quatro rodas, baseado em um microcontrolador de baixo custo, equipado com magnetômetro, sensor de distância e encoders ópticos. O sistema será capaz de realizar deslocamentos autônomos utilizando mapeamento em grid e planejamento de rotas, com controle remoto por interface web.

A principal motivação do projeto é criar uma solução acessível e didática para transporte interno automatizado em ambientes acadêmicos, facilitando processos de gestão dentro da universidade. Além disso, o desenvolvimento do projeto vai proporcionar o aprendizado multidisciplinar. A contribuição esperada é o desenvolvimento de uma plataforma de baixo custo com potencial de aplicação em ambientes reais, além de servir como base para futuras pesquisas em robótica móvel e IoT.

20 | CAPÍTULO 1. INTRODUÇÃO

## 1.1 Objetivos

Este trabalho tem como finalidade o desenvolvimento de um assistente robótico autônomo voltado à automação de tarefas de transporte de objetos em ambientes internos, como escritórios e residências. A proposta consiste em permitir que o usuário delegue, por meio de uma interface de controle, a entrega de itens a um destino previamente definido, sem a necessidade de deslocamento físico até o local de destino.

Além de propor uma solução prática para aplicações logísticas em pequena escala, o projeto busca consolidar e aplicar os conhecimentos teóricos adquiridos ao longo da graduação, com ênfase nas disciplinas de Sistemas Embarcados, Inteligência Artificial e Internet das Coisas (IoT). A iniciativa visa integrar esses conceitos por meio da construção de um sistema funcional, de baixo custo e alto valor educacional e tecnológico.

### 1.1.1 Objetivo Geral

Desenvolver um protótipo funcional de um veículo robótico autônomo de pequeno porte, dotado de quatro rodas, controlado por um microcontrolador ESP32, e equipado com magnetômetro QMC5883L, sensor de distância por tempo de voo (VL53L0X) e encoders ópticos para monitoramento da rotação das rodas. O sistema deverá ser capaz de se locomover autonomamente em ambientes internos, utilizando mapeamento baseado em grid, planejamento de rotas com A* e definição do destino via interface web.

### 1.1.2 Objetivos Específicos

- Projetar e montar a estrutura física do robô, incluindo os motores, a carcaça e a eletrônica embarcada;
- Implementar controle de velocidade e trajetória utilizando algoritmos PID com feedback dos encoders;
- Integrar o magnetômetro, o sensor de distância e os encoders ópticos ao sistema de controle e navegação;
- Desenvolver o módulo de mapeamento em grid e aplicar algoritmos de busca para planejamento de trajetórias (como o algoritmo A*);
- Implementar uma interface web acessível via rede Wi-Fi, permitindo a seleção de destinos pelo usuário;
- Realizar testes experimentais e validar o desempenho do sistema em ambiente controlado, analisando a precisão, a robustez e a viabilidade da proposta.

1.2. ORGANIZAÇÃO DO TEXTO | 21

## 1.2 Organização do Texto

Este trabalho está estruturado da seguinte forma:

- Capítulo 2 — Revisão Bibliográfica: apresenta uma análise de trabalhos relacionados à robótica móvel autônoma, abordando diferentes aplicações e tecnologias que fundamentam o projeto.
- Capítulo 3 — Fundamentação Teórica: detalha os conceitos teóricos essenciais, incluindo sistemas embarcados, controle de motores, magnetômetro, sensores de distância, odometria por encoders, algoritmos PID, odometria e técnicas de mapeamento e planejamento de rotas.
- Capítulo 4 — Materiais e Métodos: descreve os componentes de hardware e as ferramentas de software utilizadas, a arquitetura do sistema, as estratégias de controle e navegação, e a metodologia de desenvolvimento do protótipo.
- Capítulo 5 — Resultados: apresenta a metodologia de teste, os registros utilizados, os resultados de deslocamento, rotação, detecção de obstáculos, interface web e as limitações observadas experimentalmente.
- Capítulo 6 — Conclusão: consolida as conclusões do trabalho, discute a viabilidade do protótipo e apresenta recomendações para trabalhos futuros.

23

# 2 Revisão Bibliográfica

Este capítulo apresenta uma análise de trabalhos relacionados ao desenvolvimento de robôs móveis autônomos, com foco na aplicação em ambientes internos e no transporte de pequenos objetos. São considerados aspectos como autonomia de navegação, controle embarcado, sensoriamento, planejamento de rotas e usabilidade em contextos educacionais ou institucionais. Embora a área de robótica móvel autônoma seja ampla, buscou-se destacar estudos que, direta ou indiretamente, dialogam com os objetivos e desafios deste projeto.

Robôs aplicados a missões de busca e salvamento, como os descritos por Calisi et al. (2007), utilizam estratégias avançadas de exploração e navegação em ambientes não estruturados. Esses robôs são capazes de se orientar em locais desconhecidos e dinâmicos, utilizando sensores embarcados e algoritmos de mapeamento para garantir a segurança da operação. De forma complementar, Samir et al. (2024) apresentam uma revisão sistemática sobre robôs de resgate equipados com inteligência artificial, destacando a integração entre sensoriamento preciso, aprendizado de máquina e planejamento adaptativo em cenários de alto risco. Apesar de operarem em contextos significativamente mais complexos, esses estudos fornecem subsídios importantes sobre navegação segura e sensoriamento embarcado.

Ainda que este projeto se concentre em ambientes internos e controlados, como salas de aula e laboratórios, há paralelos metodológicos com outras aplicações robóticas. Trabalhos como os de Lemos (2021) e Nauert e Kampmann (2023) discutem o uso de veículos submersos autônomos (AUVs) para inspeção de estruturas submarinas, enfrentando desafios técnicos severos, como navegação em seis graus de liberdade e comunicação limitada. Apesar das diferenças no ambiente operacional, ambos os casos compartilham a necessidade de controle embarcado confiável, fusão sensorial e autonomia de locomoção — elementos também centrais para o presente projeto.

Em ambientes públicos e educacionais, Cantucci, Marini e Falcone (2024) investigaram o impacto da autonomia adaptativa de robôs na experiência dos visitantes em museus. Já Silva e Souza (2024) analisam o uso de robôs inteligentes como mediadores culturais em espaços expositivos. Esses estudos destacam a importância da interação com o usuário, da acessibilidade e da robustez na arquitetura de controle. O robô desenvolvido neste projeto, embora mais simples em termos de funcionalidade e escopo, compartilha o objetivo de ser uma ferramenta acessível, intuitiva e funcional em contextos institucionais e educacionais, promovendo uma experiência de uso descomplicada por meio de uma interface web.

Robôs autônomos também são amplamente empregados em aplicações militares e de defesa, conforme discutido em Studies (2021) e Automate.org (2023). Nesses cenários, robustez estrutural, inteligência situacional e operação remota segura são características críticas. Embora o

24 | CAPÍTULO 2. REVISÃO BIBLIOGRÁFICA

projeto aqui apresentado não possua finalidade bélica, ele adota conceitos estruturais semelhantes, como a navegação baseada em sensores, o controle de trajetória via PID e a operação remota via rede sem fio, adaptados para fins acadêmicos e com foco em baixo custo e reprodutibilidade.

No campo da robótica modular, Moubarak e Ben-Tzvi (2012) destacam a importância de plataformas reconfiguráveis, que possibilitam adaptações estruturais para diferentes tipos de missão. Embora o robô desenvolvido neste projeto não possua capacidade de reconfiguração física, adota uma arquitetura modular do ponto de vista do software e da organização dos componentes embarcados. O uso de bibliotecas customizadas, divididas por responsabilidade funcional, favorece a manutenção do sistema e sua expansão futura.

Em síntese, os trabalhos analisados contribuem para o embasamento técnico do projeto, oferecendo diferentes perspectivas sobre sensoriamento, controle e navegação em robôs móveis. O diferencial da proposta apresentada neste TCC reside na sua aplicação prática: a criação de um robô autônomo de pequeno porte, controlado por um ESP32, capaz de realizar o transporte de objetos em ambientes internos por meio de navegação baseada em mapeamento em grid, sensores de distância (VL53L0X), referência magnética de orientação (QMC5883L), algoritmo A* e interface web embarcada. Trata-se de uma solução voltada à didática, ao baixo custo e à possibilidade de replicação em contextos educacionais e institucionais.

25

# 3 Fundamentação Teórica

Este capítulo apresenta os fundamentos teóricos que sustentam o desenvolvimento do projeto, abrangendo os conceitos, tecnologias e métodos necessários para a construção de um veículo robótico autônomo com capacidade de navegação em ambiente interno. A estrutura modular do sistema envolve desde a integração de sensores e atuadores até o controle de movimento e planejamento de rotas.

Inicialmente, são abordados os conceitos de sistemas embarcados e Internet das Coisas (IoT), destacando-se suas arquiteturas e aplicações práticas, bem como a justificativa da escolha do microcontrolador ESP32, amplamente utilizado em projetos que exigem conectividade e capacidade computacional embarcada (Seção 3.1).

Na sequência, são discutidos os princípios de controle de motores de corrente contínua (DC) utilizando circuitos do tipo ponte H, responsáveis por permitir o acionamento bidirecional e o ajuste de velocidade dos motores (Seção 3.2). A Seção 3.5 trata da aplicação do controle PID para estabilização e controle de movimento, bem como do uso de odometria com encoders para estimativa de deslocamento do robô.

Também são explorados os recursos de orientação magnética (Seção 3.3), com destaque para o sensor QMC5883L, que fornece medições do campo magnético nos eixos X, Y e Z para estimativa de direção no plano horizontal. Em seguida, na Seção 3.4, discorre-se sobre sensores de distância baseados no princípio de Time-of-Flight (ToF), como o VL53L0X, cuja precisão e velocidade tornam-no adequado para detecção de obstáculos em tempo real.

Por fim, a Seção 3.6 apresenta as técnicas de representação do ambiente por meio de mapas em grid e os algoritmos de planejamento de rotas, como A* e Dijkstra, que permitem ao robô traçar trajetórias seguras e eficientes até o destino escolhido.

Esses tópicos compõem o corpo teórico necessário para a implementação do sistema proposto, oferecendo suporte conceitual e justificativa técnica para as decisões de projeto. A fundamentação apresentada a seguir baseia-se em referências consolidadas na literatura acadêmica e técnica, como Kurose e Ross (2009), entre outras.

## 3.1 Sistemas Embarcados e IoT

Sistemas embarcados consistem em plataformas computacionais especializadas, compostas por microcontroladores, firmware e, em alguns casos, sistemas operacionais de tempo real (RTOS), cujo propósito é executar tarefas específicas sob restrições rígidas de desempenho, consumo energético e confiabilidade. Essas plataformas integram, de forma sinérgica, componentes de hardware

26 | CAPÍTULO 3. FUNDAMENTAÇÃO TEÓRICA

e software, promovendo soluções otimizadas para diferentes finalidades. Por serem projetados para operar de maneira contínua, eficiente e, frequentemente, em tempo real, os sistemas embarcados desempenham papel central em diversos setores da tecnologia, como automação industrial, controle de processos, equipamentos médicos, monitoramento ambiental e dispositivos de Internet das Coisas (IoT), Carvalho e Neto (2024).

No contexto da IoT, a integração de sistemas embarcados com redes de comunicação sem fio, como Wi-Fi, Bluetooth e LoRa, potencializa a conectividade e a interoperabilidade entre dispositivos distribuídos. Essa conectividade torna possível a criação de ambientes inteligentes, capazes de reagir dinamicamente a estímulos do ambiente, compartilhar dados em tempo real e executar comandos remotos. Entretanto, tais sistemas exigem soluções que conciliem eficiência energética, segurança de dados e escalabilidade, aspectos críticos para aplicações em larga escala, como cidades inteligentes, agricultura de precisão e automação residencial.

Para o desenvolvimento deste projeto, foi selecionado o microcontrolador ESP32, do kit de desenvolvimento DOIT ESP32 Devkit V1, devido à sua ampla versatilidade, baixo custo e rica gama de funcionalidades embarcadas. O ESP32 possui conectividade Wi-Fi e Bluetooth integradas, múltiplos núcleos de processamento, suporte a múltiplos pinos GPIO, conversores analógicodigitais (ADCs), interfaces I2C, SPI e UART, além de timers e recursos de controle PWM, características que o tornam ideal para aplicações embarcadas modernas. A Figura 1 apresenta o diagrama de pinagem da placa, destacando a disposição dos pinos e suas respectivas funcionalidades, informação essencial para a correta conexão dos periféricos utilizados no protótipo.

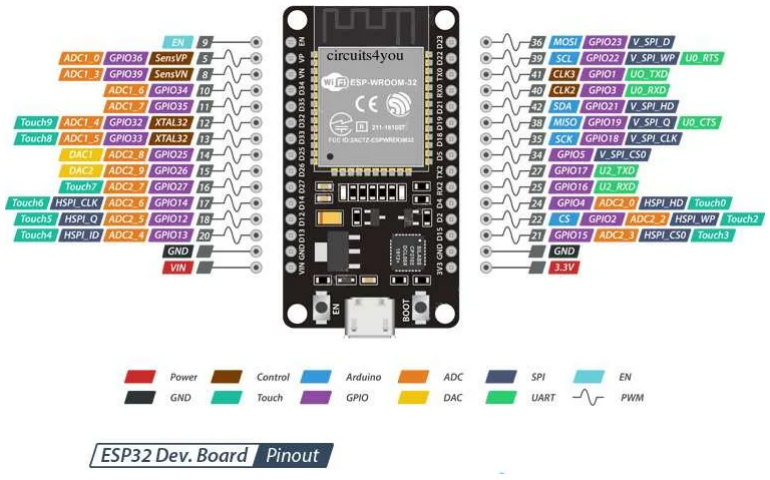
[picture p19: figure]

Figura 1 – Diagrama de pinagem do ESP32.

Fonte: lastminuteengineers.com (https://lastminuteengineers.com/esp32-pinout-reference/)

A escolha do ESP32 justifica-se, portanto, por sua capacidade de processamento superior, ampla conectividade, suporte a múltiplos protocolos de comunicação e integração de periféricos

3.2. CONTROLE DE MOTORES DC E PONTE H | 27

essenciais, reduzindo a necessidade de componentes externos. Além disso, sua popularidade na comunidade de desenvolvimento embarcado proporciona vasta documentação e bibliotecas de código, facilitando o processo de implementação e depuração do sistema.
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

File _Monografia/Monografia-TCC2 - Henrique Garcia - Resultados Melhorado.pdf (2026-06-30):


Henrique Campanha Garcia

Desenvolvimento de um Veículo Robótico Autônomo de

Pequeno Porte Baseado em ESP32

São José dos Campos, SP

### Henrique Campanha Garcia

## Desenvolvimento de um Veículo Robótico Autônomo de

## Pequeno Porte Baseado em ESP32

Trabalho de conclusão de curso apresentado ao Instituto de Ciência e Tecnologia – UNIFESP, como parte das atividades para obtenção do título de Bacharel em Ciência da Computação.

Universidade Federal de São Paulo – UNIFESP

Instituto de Ciência de Tecnologia

Bacharelado em Ciência da Computação

### Orientador: Prof. Dr. André Marcorin de Oliveira

### São José dos Campos, SP

### Junho de 2026

### Henrique Campanha Garcia

## Desenvolvimento de um Veículo Robótico Autônomo de Pequeno Porte Baseado em ESP32

Trabalho de conclusão de curso apresentado ao Instituto de Ciência e Tecnologia – UNIFESP, como parte das atividades para obtenção do título de Bacharel em Ciência da Computação.

Prof. Dr. André Marcorin de Oliveira Orientador

Prof. Dr. Sérgio Ronaldo Barros dos Santos Convidado 1

Professor
Convidado 2

Professor
Convidado 3

### São José dos Campos, SP Junho de 2026

Dedico este trabalho ao meu orientador, cuja orientação foi essencial para o desenvolvimento deste projeto.

Seus esclarecimentos, especialmente na compreensão e aplicação dos algoritmos envolvidos, foram fundamentais para que eu pudesse superar desafios técnicos e aprofundar meus conhecimentos em áreas que antes me pareciam complexas.

Agradeço pela paciência, disponibilidade e incentivo contínuo ao longo deste processo.

Dedico este trabalho também a todos que, de alguma forma contribuíram para a realização deste projeto.

Muito obrigado.

# Agradecimentos

A realização deste trabalho foi possível graças ao apoio e à colaboração de diversas pessoas e instituições, às quais expresso minha sincera gratidão.

Em primeiro lugar, agradeço ao meu orientador, Prof. Dr. André Marcorin de Oliveira, pelo constante apoio, paciência e pelas valiosas orientações técnicas, especialmente no que diz respeito à compreensão e à implementação dos algoritmos utilizados neste projeto. Sua experiência, dedicação e disponibilidade foram fundamentais para o desenvolvimento desta pesquisa.

Estendo meus agradecimentos à Universidade Federal de São Paulo (UNIFESP), instituição de ensino reconhecida pela excelência acadêmica, pelo compromisso com a formação de profissionais éticos, críticos e preparados para os desafios da sociedade contemporânea.

Aos colegas e amigos que me acompanharam ao longo da graduação, em especial Thiago Capuano e Vinicius Matumoto, sou grato pelos diálogos construtivos, pela colaboração espontânea e, sobretudo, pela amizade que tornou essa caminhada mais leve e motivadora.

À minha família, em especial aos meus pais, Margarete e Renato Garcia, agradeço pelo

amor incondicional, incentivo constante e por acreditarem em mim mesmo diante das dificuldades. Sem o apoio de vocês, este trabalho certamente não teria se concretizado.

Por fim, agradeço a todos aqueles que, direta ou indiretamente, contribuíram para a realização deste projeto.

“Não vos amoldeis às estruturas deste mundo, mas transformai-vos pela renovação da mente, a fim de distinguir qual é a vontade de Deus: o que é bom, o que Lhe é agradável, o que é perfeito. (Bíblia Sagrada, Romanos 12, 2)

# Resumo

Este trabalho apresenta o projeto e desenvolvimento de um veículo robótico autônomo de pequeno porte, concebido para realizar tarefas de transporte de objetos em ambientes internos. O sistema é fundamentado no microcontrolador ESP32, que centraliza o processamento e a conectividade. A percepção do ambiente e a locomoção precisa são viabilizadas pela integração de múltiplos sensores e atuadores, incluindo um magnetômetro QMC5883L para referência de orientação, um sensor de distância Time-of-Flight (ToF) VL53L0X para detecção frontal de obstáculos e encoders ópticos para odometria. O controle de movimento dos motores DC é realizado por meio de uma ponte H com modulação por largura de pulso (PWM), e a estabilidade da trajetória é garantida por um algoritmo de controle Proporcional, Integral e Derivativo (PID). A autonomia de navegação é alcançada por uma estratégia híbrida que combina planejamento de rota global, utilizando o algoritmo A* sobre um mapa de grid, com um controle reativo local para desvio de obstáculos em tempo real. A interação com o usuário é realizada através de uma interface web (WebServer) embarcada, que permite a designação de destinos e o monitoramento do robô via Wi-Fi. O projeto visa entregar um protótipo funcional, de baixo custo e com arquitetura modular, servindo como uma plataforma educacional e de pesquisa em robótica móvel, sistemas embarcados e Internet das Coisas (IoT).

Palavras-chave: Robô Autônomo. ESP32. Controle PID. Navegação Robótica. Mapeamento em Grid. Sistemas Embarcados.

# Abstract

This work presents the design and development of a small-scale autonomous robotic vehicle, designed to perform object transportation tasks in indoor environments. The system is based on the ESP32 microcontroller, which centralizes processing and connectivity. Environmental perception and precise locomotion are enabled by the integration of multiple sensors and actuators, including a QMC5883L magnetometer for heading reference, a VL53L0X Time-of-Flight (ToF) distance sensor for frontal obstacle detection, and optical encoders for odometry. The motion control of the DC motors is performed using an H-bridge with Pulse Width Modulation (PWM), and trajectory stability is ensured by a Proportional, Integral, and Derivative (PID) control algorithm. Navigation autonomy is achieved through a hybrid strategy that combines global path planning, using the A* algorithm on a grid map, with local reactive control for real-time obstacle avoidance. User interaction is carried out through an embedded web interface (WebServer), which allows for destination designation and robot monitoring via Wi-Fi. The project aims to deliver a functional, low-cost prototype with a modular architecture, serving as an educational and research platform in mobile robotics, embedded systems, and the Internet of Things (IoT).

Keywords: Autonomous Robot. ESP32. PID Control. Robotic Navigation. Grid Mapping. Embedded Systems.

# Lista de ilustrações

Figura 6 – Exemplo de mapa 7x7 utilizado para validação do processo de mapeamento. . | 34
Figura 9 – Versão revisada da organização dos componentes em placa de prototipação. . | 39
Figura 11 – Exemplo de caminho traçado pelo algoritmo A* sobre um mapa de ocupação. | 46
Figura 12 – Interface web do robô mostrando o mapa 7x7, com origem no canto superior

Figura 13 – Interface web principal do robô, exibindo o mapa de ocupação, botões de con-

# Lista de abreviaturas e siglas

ADC | Conversor Analógico-Digital (Analog-to-Digital Converter)
AUV | Veículo Submerso Autônomo (Autonomous Underwater Vehicle)
DC | Corrente Contínua (Direct Current)
GPIO | Pinos de Entrada/Saída de Propósito Geral (General-Purpose Input/Output)
HTTP | Protocolo de Transferência de Hipertexto (Hypertext Transfer Protocol)
IMU | Unidade de Medição Inercial (Inertial Measurement Unit)
IoT | Internet das Coisas (Internet of Things)
IHM | Interface Homem-Máquina
I2C | Inter-Integrated Circuit (padrão de comunicação)
PID | Controlador Proporcional–Integral–Derivativo
PRM | Mapa de Rotas Probabilístico (Probabilistic Roadmap)
PWM | Modulação por Largura de Pulso (Pulse Width Modulation)
RAS | Sistemas Robóticos e Autônomos (Robotic and Autonomous Systems)
RMA | Robôs Móveis Autônomos
RTOS | Sistema Operacional de Tempo Real (Real-Time Operating System)
SLAM | Localização e Mapeamento Simultâneos (Simultaneous Localization and Map- ping)
SPI | Interface Periférica Serial (Serial Peripheral Interface)
ToF | Tempo de Voo (Time-of-Flight)
UART | Transmissor/Receptor Assíncrono Universal (Universal Asynchronous Receiver- Transmitter)
VL53L0X | Sensor ToF da STMicroelectronics
Wi-Fi | Wireless Fidelity (Tecnologia de rede sem fio)
WebServer | Servidor Web embarcado

ESP32 | Microcontrolador com Wi-Fi e Bluetooth integrados da Espressif Systems
QMC5883L | Magnetômetro digital de três eixos utilizado como referência de orientação magnética
A* | Algoritmo A-star para planejamento de caminhos

# Sumário

19

# 1 Introdução

A crescente evolução dos sistemas embarcados e da Internet das Coisas (IoT) tem impulsionado o desenvolvimento de soluções autônomas para aplicações cotidianas. Nesse cenário, veículos autônomos têm despertado interesse pela sua aplicabilidade em tarefas de transporte interno, contribuindo para a automação e otimização de processos, Schilling et al. (1997).

O campo da robótica móvel tem-se desenvolvido significativamente nas últimas décadas, especialmente com a popularização de plataformas modulares e reconfiguráveis Moubarak e Ben-Tzvi (2012) e robôs com capacidade de adaptação a ambientes complexos e dinâmicos Schilling et al. (1997). Nesse contexto, dentro da robótica, os agentes podem ser classificados de acordo com seu grau de autonomia, como por exemplo, robôs teleoperados, semi-autônomos e autônomos. Em todos esses tipos de robôs, e em especial para robôs com graus elevados de autonomia, o uso de sensores embarcados, como unidades de medição inerciais (IMUs) e sensores de distância, em conjunto com algoritmos de controle robustos, como o PID (Proporcional, Integral, Derivativa), têm sido essenciais para garantir precisão e estabilidade Parween et al. (2020).

Dentre as aplicações de sistemas robóticos autônomos, podem ser destacadas os robôs de resgate e salvamento Calisi et al. (2007), Samir et al. (2024), manutenção de submarina Lemos (2021), Nauert e Kampmann (2023), interface com seres humanos em museus Cantucci, Marini e Falcone (2024), Silva e Souza (2024), aplicações militares Studies (2021), Automate.org (2023), entre outros. Em especial, os trabalhos de Nehmzow (2012) e Schilling et al. (1997) destacam a importância de projetos didáticos e aplicáveis de veículos autônomos tanto em ambientes industriais quanto acadêmicos, reforçando a relevância de soluções acessíveis e flexíveis.

Dessa forma, este projeto visa desenvolver um veículo autônomo de pequeno porte com quatro rodas, baseado em um microcontrolador de baixo custo, equipado com magnetômetro, sensor de distância e encoders ópticos. O sistema será capaz de realizar deslocamentos autônomos utilizando mapeamento em grid e planejamento de rotas, com controle remoto por interface web.

A principal motivação do projeto é criar uma solução acessível e didática para transporte interno automatizado em ambientes acadêmicos, facilitando processos de gestão dentro da universidade. Além disso, o desenvolvimento do projeto vai proporcionar o aprendizado multidisciplinar. A contribuição esperada é o desenvolvimento de uma plataforma de baixo custo com potencial de aplicação em ambientes reais, além de servir como base para futuras pesquisas em robótica móvel e IoT.

20 | CAPÍTULO 1. INTRODUÇÃO

## 1.1 Objetivos

Este trabalho tem como finalidade o desenvolvimento de um assistente robótico autônomo voltado à automação de tarefas de transporte de objetos em ambientes internos, como escritórios e residências. A proposta consiste em permitir que o usuário delegue, por meio de uma interface de controle, a entrega de itens a um destino previamente definido, sem a necessidade de deslocamento físico até o local de destino.

Além de propor uma solução prática para aplicações logísticas em pequena escala, o projeto busca consolidar e aplicar os conhecimentos teóricos adquiridos ao longo da graduação, com ênfase nas disciplinas de Sistemas Embarcados, Inteligência Artificial e Internet das Coisas (IoT). A iniciativa visa integrar esses conceitos por meio da construção de um sistema funcional, de baixo custo e alto valor educacional e tecnológico.

### 1.1.1 Objetivo Geral

Desenvolver um protótipo funcional de um veículo robótico autônomo de pequeno porte, dotado de quatro rodas, controlado por um microcontrolador ESP32, e equipado com magnetômetro QMC5883L, sensor de distância por tempo de voo (VL53L0X) e encoders ópticos para monitoramento da rotação das rodas. O sistema deverá ser capaz de se locomover autonomamente em ambientes internos, utilizando mapeamento baseado em grid, planejamento de rotas com A* e definição do destino via interface web.

### 1.1.2 Objetivos Específicos

- Projetar e montar a estrutura física do robô, incluindo os motores, a carcaça e a eletrônica embarcada;
- Implementar controle de velocidade e trajetória utilizando algoritmos PID com feedback dos encoders;
- Integrar o magnetômetro, o sensor de distância e os encoders ópticos ao sistema de controle e navegação;
- Desenvolver o módulo de mapeamento em grid e aplicar algoritmos de busca para planejamento de trajetórias (como o algoritmo A*);
- Implementar uma interface web acessível via rede Wi-Fi, permitindo a seleção de destinos pelo usuário;
- Realizar testes experimentais e validar o desempenho do sistema em ambiente controlado, analisando a precisão, a robustez e a viabilidade da proposta.

1.2. ORGANIZAÇÃO DO TEXTO | 21

## 1.2 Organização do Texto

Este trabalho está estruturado da seguinte forma:

- Capítulo 2 — Revisão Bibliográfica: apresenta uma análise de trabalhos relacionados à robótica móvel autônoma, abordando diferentes aplicações e tecnologias que fundamentam o projeto.
- Capítulo 3 — Fundamentação Teórica: detalha os conceitos teóricos essenciais, incluindo sistemas embarcados, controle de motores, magnetômetro, sensores de distância, odometria por encoders, algoritmos PID, odometria e técnicas de mapeamento e planejamento de rotas.
- Capítulo 4 — Materiais e Métodos: descreve os componentes de hardware e as ferramentas de software utilizadas, a arquitetura do sistema, as estratégias de controle e navegação, e a metodologia de desenvolvimento do protótipo.
- Capítulo 5 — Resultados: apresenta a metodologia de teste, os registros utilizados, os resultados de deslocamento, rotação, detecção de obstáculos, interface web e as limitações observadas experimentalmente.
- Capítulo 6 — Conclusão: consolida as conclusões do trabalho, discute a viabilidade do protótipo e apresenta recomendações para trabalhos futuros.

23
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

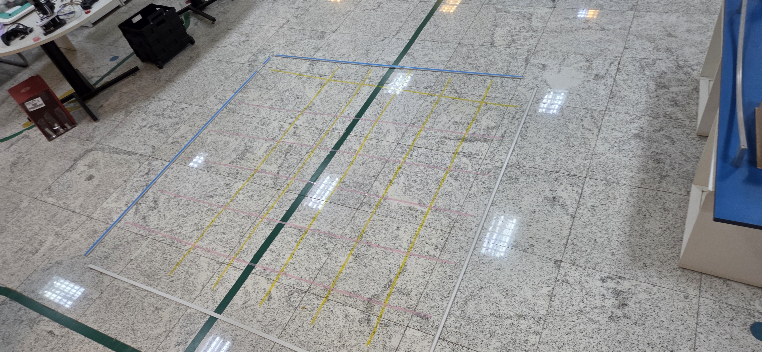
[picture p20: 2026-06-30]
_Monografia/imagens/Teste_Grid.jpg

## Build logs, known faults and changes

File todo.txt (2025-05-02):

Estudar algoritimos de controle de velocidade com o Encoder

- economia de energia - esp32
- controle de velocidade do motor/encoder
pid esp32 speed control encoder

Testar upload com o ESP pelo Arduino IDE
- modelo cinemático --> Giro do carrinho
  - https://en.wikipedia.org/wiki/Differential_wheeled_robot
  - https://www.cs.columbia.edu/~allen/F17/NOTES/icckinematics.pdf

- Malha fechada de velocidade

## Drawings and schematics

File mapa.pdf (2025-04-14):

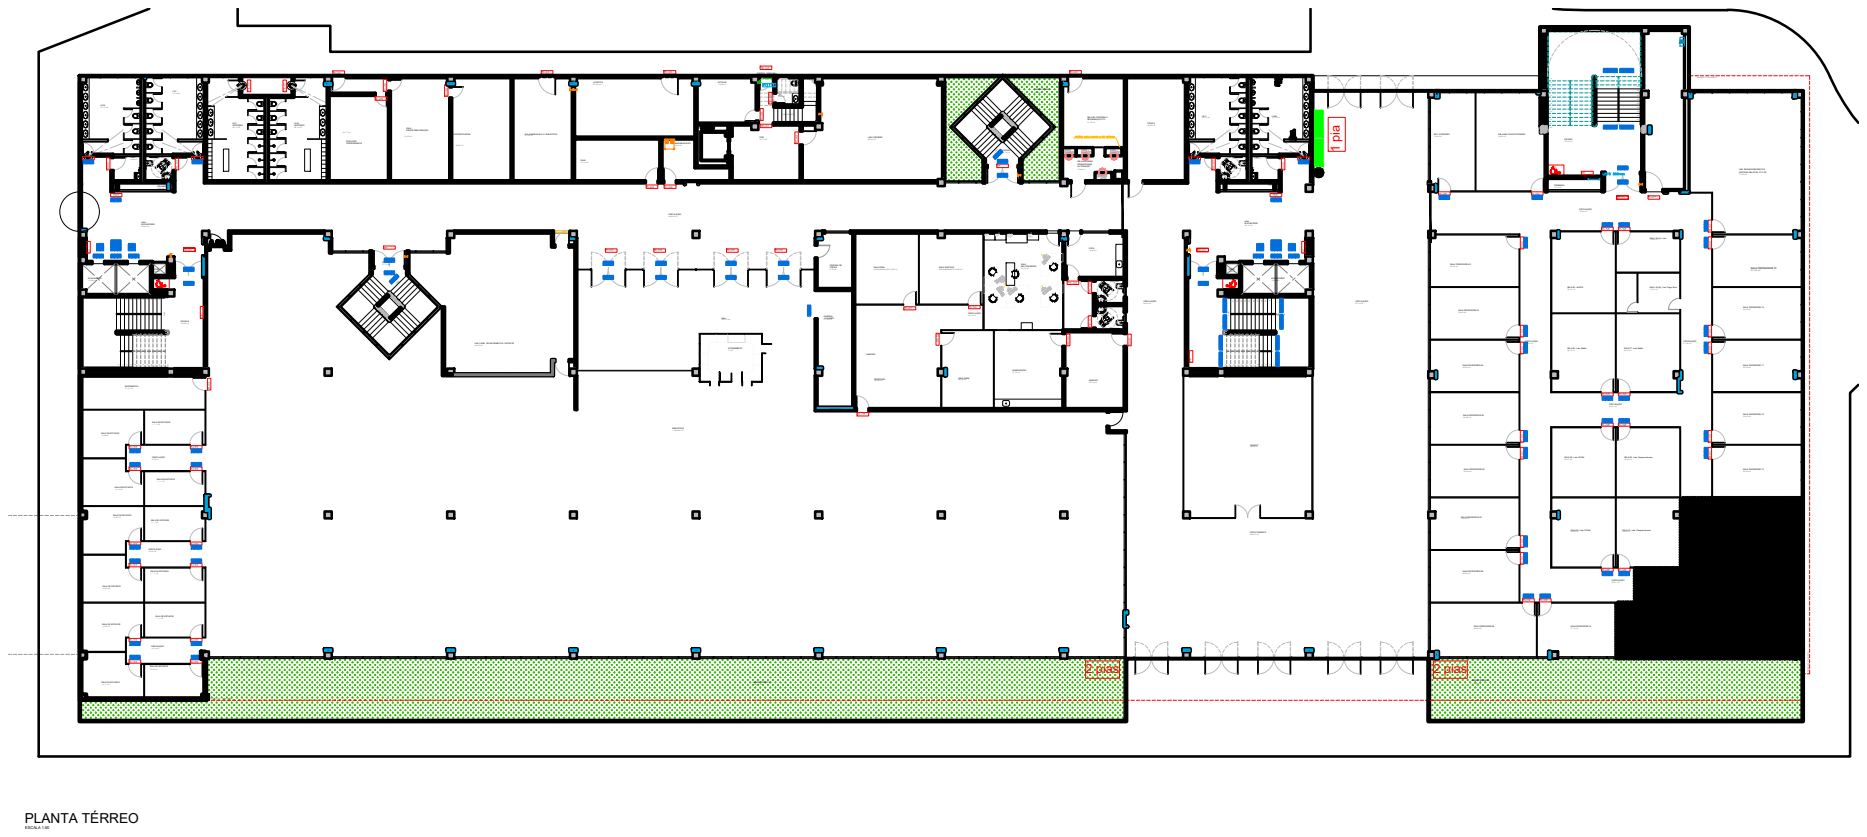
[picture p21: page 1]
PLANTA TÉRREO ESCALA 1:50; SALA PROFESSOR 02 23,32 m2 SALA PROFESSOR 03 23,40 m2 SALA PROFESSOR 04 23,22 m2 SALA PROFESSOR 05 SALA PROFESSOR 06 SALA PROFESSOR 07 23,22 m2 SALA PROFESSOR 08 SALA PROFESSOR 09 28,85 m2; SALA PROFESSOR 10 21,14 m2; SALA PROFESSOR 11 21,14 m2; SALA PROFESSOR 12 28,85 m2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

PP PI-04 SE-02 SE-01 RI-27 RI-58 RI-58 RI-58 RI-58 RI-60 RI-04 PMT

MI PTR/DG 30,90 m2 SALA 29 - Lab. Pesquisa teorica 22,52 m2 SALA 31 - Lab. Pesquisa teorica 22,29 m2 "MUSEU" 92,34 m2 30,00 m2 JARDIM TÉRREO 1 295,15 m2 JARDIM TÉRREO 2 114,40 m2 JARDIM TÉRREO 3 CÓPIAS CENTRAL DE 9,76 m2 (ANTIGAS SALAS 20, 21 E 22) 75,24 m2 LAB. ENSAIOS MECÂNICOS SALA 24 (A) - Lab. 13,20 m2 VANESSA SALA MULTIDIVISÕES 25,25 m2 APROXIMADAMENTE 23,00 m2 HALL 102,45 m2 2 pias 2 pias

1 pia 21,78 m2 SALA SISTEMAS OPERACIONAIS AUTOMAÇÃOSALA DE CONTROLE / SEGURANÇA CFTV 10,48 m2 SOM CONTROLE ILUMINAÇÃO AR COND.

SOBE ELEVADORES 10,83 m2 ELEVADORES 10,83 m2 PRUMADA 2,03 m2 PRUMADA 2,16 m2 PROJEÇÃO 1º PAVIMENTO

RI-02 RI-02 RI-02 RI-02 RI-02 RI-02 RI-02 RI-02 RI-08 RI-08 RI-08 RI-08 RI-08 RI-06 PP RI-32 PIC-02 PIC-01

RI-08 RI-07 RI-54 PIC-04

14/13 12 SALA 27 - Lab. MeMo 26,18 m2 SALA 25 - NAPPE 26,18 m2 SALA 24 (B) - Lab. Tiago Silva 12,97 m2 RI-02 RI-02 RI-02 RI-02

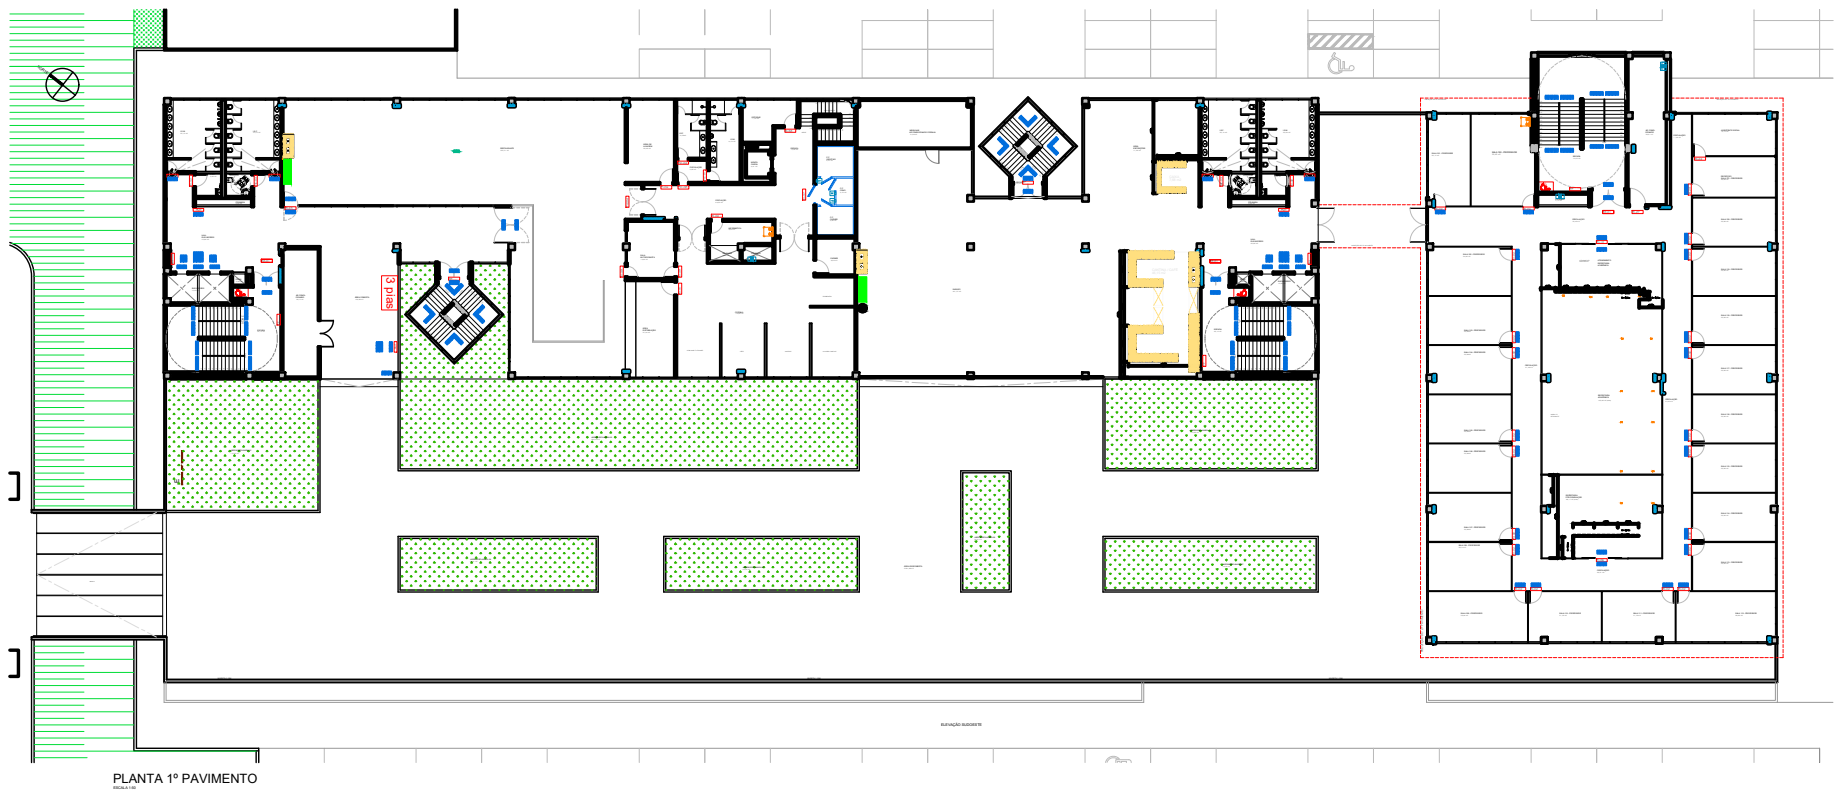
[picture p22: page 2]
ESCALA 1:50 PLANTA 1º PAVIMENTO; SALA 102 - PROFESSOR 24,06 m2 SALA 103 - PROFESSOR 23,90m2 SALA 108 - PROFESSOR SALA 109 - PROFESSOR 29,45 m2; SALA 110 - PROFESSOR 21,79 m2; SALA 111 - PROFESSOR 21,79 m2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

PROJEÇÃO DO 2º PAVIMENTO RAMPA PROJEÇÃO DO 2º PAVIMENTO PROJEÇÃO DO 2º PAVIMENTO PROJEÇÃO DO 2º PAVIMENTO PRUMADA 3,12 m2 ESCADA 72,72 m2 SOBE 01020304050607080910 12 11 222120191817161514132423 AR CONDI- CIONADO 32,91 m2 DESCE E USO RESTRITO ELEVAÇÃO SUDOESTE MURETA 1,10M MURETA 1,10M MURETA 1,10M ÁREA DESCOBERTA 2201,88 m2 PRUMADA 0,89 m2 PRUM. 0,89 m2 PRUM. 2,82 m2

PIC-04 RI-38 PIC-08 PIC-02

PIC-03PIC-01 PIC-02 PP SE-01 PP

PIC-01 PI-06 RI-43 RI-27 PMT

RI-32 PIC-02 PIC-01

PIC-03 RI-02 RI-02 RI-02 RI-02

12 52,16 m2 ESCADA 52,16 m2 PRUMADA 2,82 m2 SALA 104 - PROFESSOR 23,90m2 SALA 105 - PROFESSOR 23,90m2 SALA 106 - PROFESSOR 23,90m2 SALA 107 - PROFESSOR 23,90m2 CIRCULAÇÃO

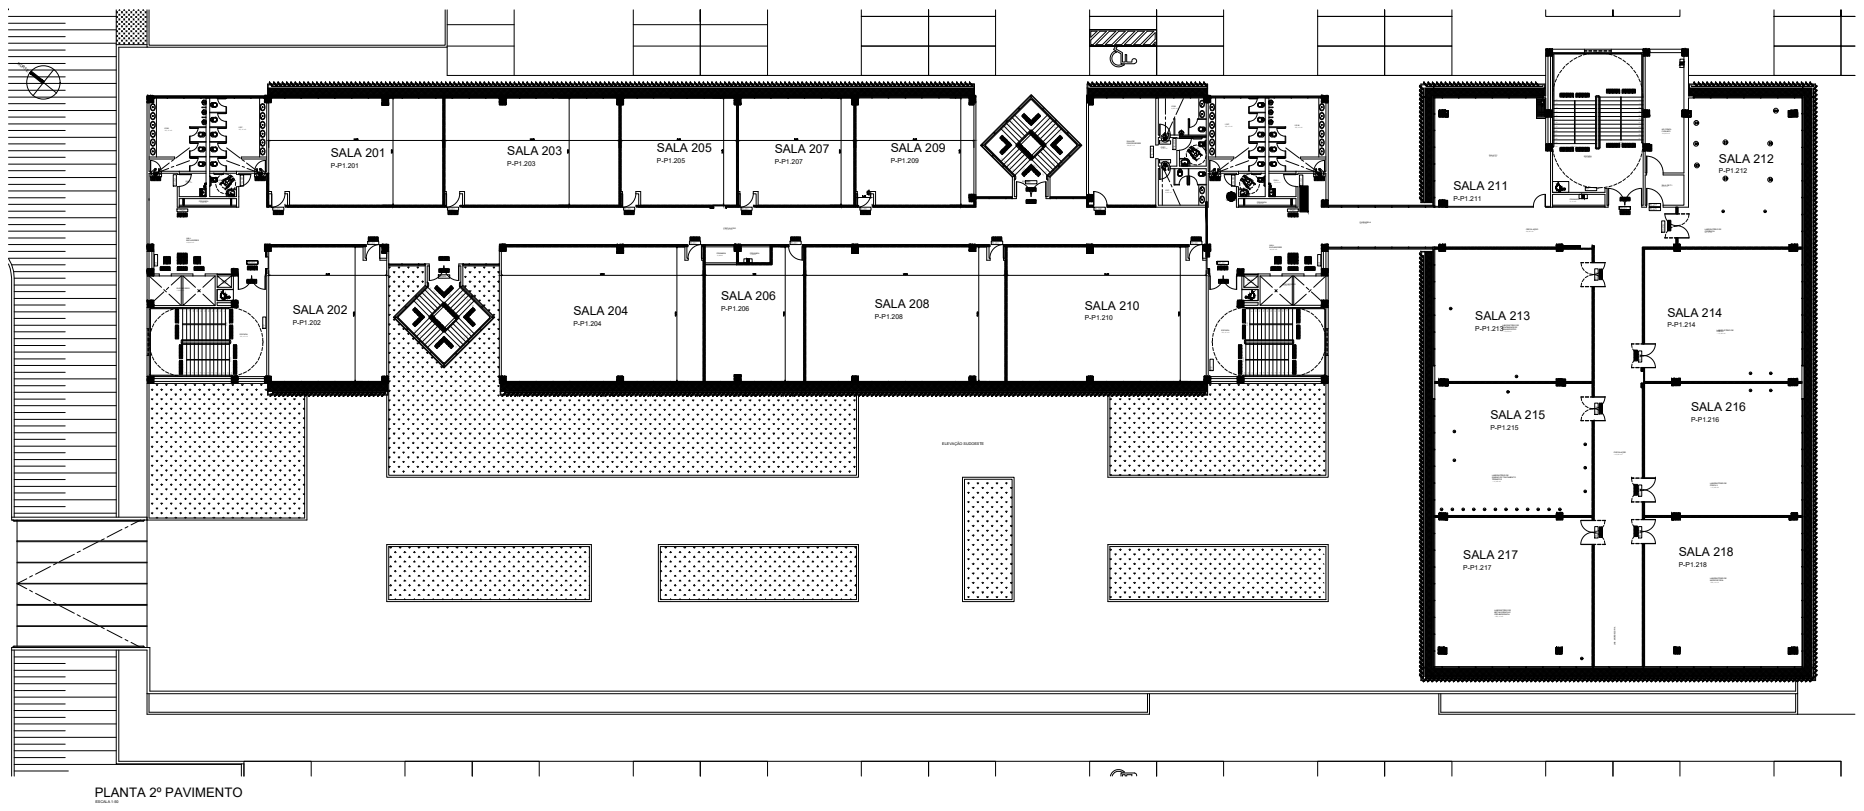
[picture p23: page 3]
ESCALA 1:50 PLANTA 2º PAVIMENTO; D.M.L. HALL ELEVADORES HALL ELEVADORES; SALA DE; I.S.M. I.S.F. PROFESSORES; I.S.P.c.D CIRCULAÇÃO; PASSARELA; SALA 211; CERÂMICA LABORATÓRIO DE FÍSICA I LABORATÓRIO DE FÍSICA II LABORATÓRIO DE FENÔMENOS DE LABORATÓRIO DE LABORATÓRIO DE; MICROSCOPIA LABORATÓRIO DE LABORATÓRIO DE METALOGRAFIA E CERAMOGRAFIA TRANSPORTES ENSINO DE TRATAMENTO TÉRMICOS; CIRCULAÇÃO I.S.P.c.D 23,16 m2; ESCADA SOBE DESCE 27,72 m2; SOBE ESCADA; DESCE27,72 m2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

12 52,16 m2 ESCADA 52,16 m2 NORTE SE-01

LAB. MICROSCOPIA SALA 202 P-P1.202 SALA 218 P-P1.218 SALA 211 P-P1.211 SALA 201 P-P1.201 SALA 204 P-P1.204 SALA 203 P-P1.203 SALA 206 P-P1.206 SALA 205 P-P1.205 SALA 208 P-P1.208 SALA 207 P-P1.207 SALA 210 P-P1.210 SALA 209 P-P1.209 SALA 212 P-P1.212 SALA 213 P-P1.213 SALA 214 P-P1.214 SALA 215 P-P1.215 SALA 216 P-P1.216 SALA 217 P-P1.217

PIC-08 PIC-02 PIC-01

PIC-03 PIC-01 PIC-02 PP SE-01 PP

PIC-03 RI-01 RI-01 RI-01 RI-01 RI-01 RI-01 RI-01 RI-01 RI-01 RI-01 RI-02

RI-32 PIC-02 PIC-01

RI-26 RI-65 PMT

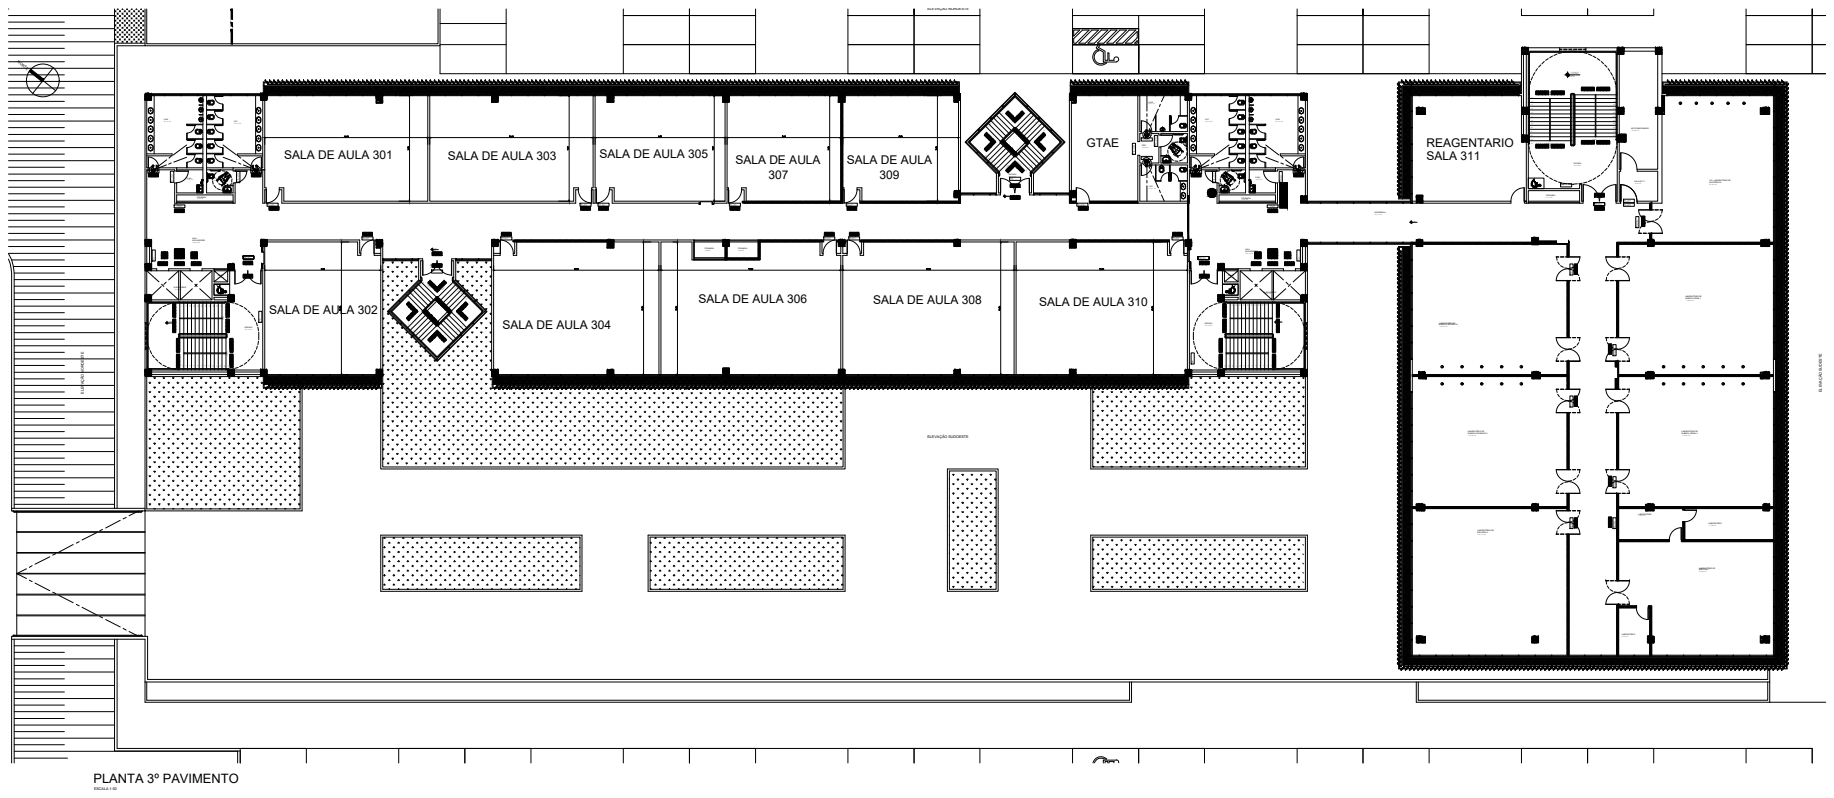
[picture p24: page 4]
ESCALA 1:50 PLANTA 3º PAVIMENTO; PASSARELA 25,13 m2 SOBE; DESCE SOBE DESCE; SOBE DESCE; 24 D.M.L. 3,50 m2 CIRC. 3,38 m2 I.S.-P.c.D. I.S.F. 9,81 m2 I.S.M. 9,81 m2 I.S.P.c.D. D.M.L. ESCADA; 12 ELEVADORES ESCADA 25,62 m2 121110 090807 19 2021 222324 131415161718 060504030201; QUÍMICA ORGÂNICA I; LABORATÓRIO DE; BIOLOGIA I LABORATÓRIO DE LABORATÓRIO DE BIOLOGIA II; LABORATÓRIO; LABORATÓRIO LABORATÓRIO GTAE; PRUMADA 3,12 m2; ESCADA 72,72m2; SOBE; AR CONDICIONADO 25,95 m2 DESCE NPA 840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

ELEVAÇÃO NOROESTE NPA 840 0,89 m2 PRUM. 0,89 m2 PRUM. SALA DE AULA 304 NORTE SE-01

13 ESCADA 27,72 m2 ELEVADORES 10,83 m2 2,03 m2 PRUMADA PRUMADA 3,50 m2 2,03 m2 52,16 m2 10,83 m2 3,50 m2 I.S.P.c.D. 3,50 m2 4,45 m2 ELEVADORES HALL 22,15 m2 I.S.F. I.S.M. 23,16 m2 23,16 m2 I.S.M. I.S.F. 23,16 m2 ELEVADORES HALL 42,84 m2 ESCADA 52,16 m2 23,16 m2 SALA DE AULA 301 SALA DE AULA 303 SALA DE AULA 305PRUMADA PRUMADA 2,82m2 2,82m2 SALA DE AULA 302 SALA DE AULA 308 SALA DE AULA 310 ELETRÔNICA 312 - LABORATÓRIO DE QUÍMICA GERAL I LABORATÓRIO DE

MI RI-27 SALA DE AULA 306 REAGENTARIO SALA 311 SALA DE AULA 307 SALA DE AULA 309

PIC-08 PIC-02 PIC-01

PIC-03PIC-01 PIC-02 PP SE-01 PP

PIC-03 RI-01 RI-01 RI-01 RI-01 RI-01 RI-01 RI-01 RI-01 RI-01 RI-01 RI-02
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

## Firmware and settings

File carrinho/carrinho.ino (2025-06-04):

/*
	Trabalho de conclusão de Curso - UNIFESP - Campus São José dos Campos
	Alunos: Henrique Campanha Garcia
	Professor Orientador: André Marcorin
	Universidade: UNIFESP - Campus São José dos Campos
	Itens utilizados:
	- ESP32 --> Controlador do carrinho, que controla tudo.
	- Ponte H --> Utilizado para controlar os motores do carrinho.
	- 4 motores CC --> Utilizado para movimentar o carrinho.
		* Motor 1: Motor direito.
			| Pino 12 --> Ponte H.
			| Pino 13 --> Ponte H.
			| Pino 14 --> PWM.
		* Motor 2: Motor esquerdo.
			| Pino 33 --> Ponte H.
			| Pino 25 --> Ponte H.
			| Pino 32 --> PWM.
	- 2 encoders --> Utilizado para medir a velocidade do carrinho.
		* Encoder 1: Motor direito.
			| Pino 26 --> Encoder.
			| Pino 27 --> Encoder.
		* Encoder 2: Motor esquerdo.
			| Pino 35 --> Encoder.
			| Pino 34 --> Encoder.
	- 1 sensor de distância VL53L0X --> Utilizado para medir a distância do carrinho em relação a um obstáculo.
		* Pino SDA --> 21
		* Pino SCL --> 22
	- 1 sensor MPU6050 --> Utilizado para medir a aceleração e Giroscópio do carrinho.
		* Pino SDA --> 21
		* Pino SCL --> 22
	- 1 bateria de 9V --> Utilizado para alimentar a ponte H que alimenta os motores e o ESP32 (via 5V).
		* Externo ao ESP32, ligado na ponte H.
*/

#define DEBUG_PRINTS

#include <WiFi.h>
// #include <ESPAsyncWebServer.h>
// #include <SPIFFS.h>
#include <WebServer.h>

#include <Wire.h>
#include "Adafruit_Sensor.h"
#include "Adafruit_MPU6050.h"
#include "Adafruit_VL53L0X.h"

#include <Arduino.h>
#include <math.h>

#include "LED.h"
#include "MediaMovel.h"
#include "PowerManager.h"

const char* ssid = "Canguru";
const char* password = "VamoPula";

const double intentKp = 1.0;
const double intentKi = 0.5;
const double intentKd = 0.0;

// AsyncWebServer server(80);
WebServer server(80);

template <typename T>
T clamp(T value, T min, T max) {
	if (value < min) return min;
	if (value > max) return max;
	return value;
}

class VL53L0X {
private:
	Adafruit_VL53L0X sensor; // sem alocação dinâmica
	unsigned long lastRead = 0; // inicialização inline
	int last_reading = 0;
	static const unsigned long readInterval = 100; // ms entre leituras

	// previne cópia acidental (dois objetos no mesmo hardware)
	VL53L0X(const VL53L0X&) = delete;
	VL53L0X& operator=(const VL53L0X&) = delete;

public:
	VL53L0X() = default;  // construtor padrão

	void setup() {
		if (!sensor.begin()) {
			#ifdef DEBUG_PRINTS
				Serial.println("Falha ao encontrar o sensor VL53L0X");
			#endif
			LED inLed = LED(2);
			inLed.setup();
			while (true) {
				inLed.toggle();
				delay(10);  // mantém o watchdog feliz
			}
		}
		#ifdef DEBUG_PRINTS
			Serial.println("Sensor VL53L0X encontrado!");
		#endif
	}

	int loop() {
		unsigned long now = millis();
		if (now - lastRead < readInterval) {
			return last_reading;
		}
		lastRead = now;

		VL53L0X_RangingMeasurementData_t measure;
		sensor.rangingTest(&measure, false);

		#ifdef DEBUG_PRINTS
			Serial.print("Distancia: ");
		#endif
		if (measure.RangeStatus != 4) { // se não estiver fora de alcance
			last_reading = measure.RangeMilliMeter;
			#ifdef DEBUG_PRINTS
				Serial.print(last_reading);
				Serial.println(" mm");
			#endif
		} else {
			#ifdef DEBUG_PRINTS
				Serial.println("Fora do alcance");
			#endif
			last_reading = 99999;
		}
		return last_reading;
	}
};

class MPU6050 {
private:
	Adafruit_MPU6050 sensor;  // sem new/delete
	unsigned long lastRead = 0;
	static const unsigned long readInterval = 20; // ms entre leituras

	MediaMovel gyroX{10};
	MediaMovel gyroY{10};
	MediaMovel gyroZ{10};

	// previne cópia acidental (dois objetos lutando pelo mesmo hardware)
	MPU6050(const MPU6050&) = delete;
	MPU6050& operator=(const MPU6050&) = delete;

public:
	MPU6050() = default;  // construtor padrão

	void setup() {
		if (!sensor.begin()) {
			#ifdef DEBUG_PRINTS
				Serial.println("Falha ao encontrar o sensor MPU6050");
			#endif
			LED inLed = LED(2);
			inLed.setup();
			while (true) {
				inLed.toggle();
				delay(20);  // mantém o watchdog feliz
			}
		}
		sensor.setAccelerometerRange(MPU6050_RANGE_2_G);
		sensor.setGyroRange(MPU6050_RANGE_500_DEG);
		sensor.setFilterBandwidth(MPU6050_BAND_21_HZ);
	}

	sensors_event_t getAccelerometer() {
		sensors_event_t a, g, temp;
		sensor.getEvent(&a, &g, &temp);
		return a;
	}
	sensors_event_t getGyroscope() {
		sensors_event_t a, g, temp;
		sensor.getEvent(&a, &g, &temp);
		return g;
	}
	sensors_event_t getTemperature() {
		sensors_event_t a, g, temp;
		sensor.getEvent(&a, &g, &temp);
		return temp;
	}

	float getAccelerometerX() {
		return getAccelerometer().acceleration.x;
	}
	float getAccelerometerY() {
		return getAccelerometer().acceleration.y;
	}
	float getAccelerometerZ() {
		return getAccelerometer().acceleration.z;
	}

	float getGyroscopeX() {
		return gyroX.get();
	}
	float getGyroscopeY() {
		return gyroY.get();
	}
	float getGyroscopeZ() {
		return gyroZ.get();
	}
	float getTemperatureC() {
		return getTemperature().temperature;
	}

	void loop() {
		unsigned long now = millis();
		if (now - lastRead < readInterval) {
			return;  // evita leituras muito frequentes
		}
		lastRead = now;

		// faz só uma chamada ao sensor por ciclo
		sensors_event_t a, g, temp;
		sensor.getEvent(&a, &g, &temp);

		// Atualiza as médias móveis com offsets calibrados
		gyroX.add(g.gyro.x + 0.06);
		gyroY.add(g.gyro.y - 0.03);
		gyroZ.add(g.gyro.z - 0.03);
	}
};

class Encoder {
private:
	volatile int countA = 0, countB = 0;
	uint8_t pinA, pinB;
	int lastStateB = LOW;
	bool clockwise = true;

	static void isrA_arg(void* arg) {
		static_cast<Encoder*>(arg)->onPulseA();
	}
	static void isrB_arg(void* arg) {
		static_cast<Encoder*>(arg)->onPulseB();
	}

	// callbacks de pulso sem IRAM_ATTR
	void onPulseA() {
		countA++;
	}
	void onPulseB() {
		countB++;
		int current = digitalRead(pinB);
		if (lastStateB == LOW && current == HIGH) {
			clockwise = (digitalRead(pinA) == LOW);
		}
		lastStateB = current;
	}

public:
	Encoder(uint8_t pinA, uint8_t pinB) : pinA(pinA), pinB(pinB) {
		countA = countB = 0;
		lastStateB = LOW;
		clockwise = true;
	}

	void begin() {
		pinMode(pinA, INPUT_PULLUP);
		pinMode(pinB, INPUT_PULLUP);
		// passa 'this' para o ISR correto
		attachInterruptArg(pinA, isrA_arg, this, CHANGE);
		attachInterruptArg(pinB, isrB_arg, this, CHANGE);
	}

	void reset() {
		countA = countB = 0;
	}

	double getRPM(int teeth = 10, double intervalSec = 0.1) {
		int pulses = (countA + countB) / 2;
		double revs = pulses / double(teeth * 2);
		return (revs / intervalSec) * 60.0;
		// return revs;
	}

	double getSpeed(int wheelDiameter = 65, int teeth = 10, double intervalSec = 0.1) {
		double rpm = getRPM(teeth, intervalSec);
		return (rpm * wheelDiameter * M_PI) / 1000.0; // mm/s
	}

	bool isClockwise() const {
		return clockwise;
	}
};

#include "PID.h"

unsigned long lastReading = 0; // para evitar leituras excessivas
class Motor {
private:
	unsigned long lastDebug = 0;
	unsigned long last_think = 0;
	const uint8_t in1Pin, in2Pin, pwmPin;
	Encoder* encoder;

	double targetRPM = 100.0;
	double currentRPM = 0.0;
	double pidOutput = 0.0;

	PID pidRPM; // PID original para controle de RPM
	PID pidGyro; // Novo PID dedicado ao erro de giroscópio

	static constexpr unsigned long thinkInterval = 500; // ms entre updates

public:
	// Construtor: inicializa ambos PIDs
	Motor(int in1, int in2, int pwm, Encoder* enc, float kp_rpm = 1.0, float ki_rpm = 5.0, float kd_rpm = 0.0, float kp_gyro = 0.1, float ki_gyro = 0.0, float kd_gyro = 0.0) : in1Pin(in1), in2Pin(in2), pwmPin(pwm), encoder(enc),
		pidRPM(kp_rpm, ki_rpm, kd_rpm, thinkInterval/1000.0f), pidGyro(kp_gyro, ki_gyro, kd_gyro, thinkInterval/1000.0f) {}

	void begin() {
		pinMode(in1Pin, OUTPUT);
		pinMode(in2Pin, OUTPUT);
		pinMode(pwmPin, OUTPUT);

		encoder->begin();
		encoder->reset();

		stop();
		// limites RPM em rad/s
		pidRPM.setMaxMin(200.0 * M_PI / 30.0, 0.0);
		// limites para correção de giroscópio (em rad/s)
		pidGyro.setMaxMin(0.5, -0.5);
	}

	void setTunings(float kp, float ki, float kd) {
		pidRPM.setTunning(kp, ki, kd);
		pidGyro.setTunning(kp/10, ki/10, kd/10);
	}
	void setTargetRPM(double rpm) {
		targetRPM = rpm;
	}

	void forward() {
		encoder->reset();
		stop();

		digitalWrite(in1Pin, HIGH);
		digitalWrite(in2Pin, LOW);

		targetRPM = 100.0;

		#ifdef DEBUG_PRINTS
			Serial.print("[Motor "); Serial.print(pwmPin);
			Serial.println("] Direction is now forwards");
		#endif
	}
	void backward() {
		encoder->reset();
		stop();

		digitalWrite(in1Pin, LOW);
		digitalWrite(in2Pin, HIGH);

		targetRPM = 100.0;
		#ifdef DEBUG_PRINTS
			Serial.print("[Motor "); Serial.print(pwmPin);
			Serial.println("] Direction is now backwards");
		#endif
	}
	void stop() {
		digitalWrite(in1Pin, LOW);
		digitalWrite(in2Pin, LOW);
		encoder->reset();

		targetRPM = 0.0;
		pidRPM.reset();
		pidGyro.reset();
		currentRPM = 0.0;
		pidOutput = 0.0;
		analogWrite(pwmPin, 0);
		lastReading = millis();

		#ifdef DEBUG_PRINTS
			Serial.print("[Motor "); Serial.print(pwmPin);
			Serial.println("] Stopped");
		#endif
	}

	void update(double gyro_error = 0.0) {
		unsigned long now = millis();
		if (now - last_think < thinkInterval) return;
		last_think = now;

		double lastPidOutput = pidOutput;
		currentRPM = encoder->getRPM(10, thinkInterval/1000.0);

		// controle de RPM
		float targetRadS  = targetRPM * (M_PI / 30.0f);
		float currentRadS = currentRPM * (M_PI / 30.0f);
		float rpmControl  = pidRPM.compute(targetRadS, currentRadS);

		// controle de alinhamento usando erro do giroscópio
		float gyroControl = pidGyro.compute(0.0f, static_cast<float>(gyro_error));
		gyroControl -= 255.0f / 2.0f; // centraliza em torno de 0

		// soma dos dois controles para sinal PWM
		pidOutput = rpmControl + gyroControl;
		pidOutput = clamp(pidOutput, 0.0, 255.0);

		analogWrite(pwmPin, int(pidOutput));
		encoder->reset();

		if (now - lastDebug >= thinkInterval) {
			#ifdef DEBUG_PRINTS
				Serial.print("[Motor "); Serial.print(pwmPin);
				Serial.print("] RPM out: "); Serial.print(rpmControl);
				Serial.print(" | Gyro out: "); Serial.print(gyroControl);
				Serial.print(" -> PWM: "); Serial.println(pidOutput);

				Serial.println("\n"); Serial.print("Encoder RPM Read: ");
				Serial.print(currentRPM); Serial.print("RPM | ");
				Serial.print(currentRadS); Serial.println("rad/s");

				Serial.print("Gyro Read: "); Serial.println(gyro_error);
			#endif
			lastDebug = now;
		}

		// if (pidOutput < 10.0) {
		// 	stop();
		// 	#ifdef DEBUG_PRINTS
		// 	Serial.println("Motor desligado por PID baixo");
		// #endif
		// }
	}


	bool isMoving() {
		return (pidOutput > 1.0) && (targetRPM > 0.0);
	}

	void manualAddPID(int value) {
		pidOutput += value;
		analogWrite(pwmPin, int(pidOutput));
		#ifdef DEBUG_PRINTS
			Serial.print("[Motor "); Serial.print(pwmPin);
			Serial.print("] PID manual adicionado: "); Serial.println(value);
			Serial.print("Novo PID Output: "); Serial.println(pidOutput);
		#endif
		lastReading = millis();
	}
};

enum Movement {
	MOVEMENT_FORWARD,
	MOVEMENT_BACKWARDS,
	MOVEMENT_TURN_LEFT,
	MOVEMENT_TURN_RIGHT,
	MOVEMENT_STOPPED
};

class PonteH {
private:
	Motor*	  motorRight;
	Motor*	  motorLeft;
	Movement	currentMove	= MOVEMENT_STOPPED;
	bool		isMoving	   = false;
	double	  turning_angleZ = 0.0;
	unsigned long lastUpdate   = 0;
	static const unsigned long controlInterval = 100; // ms entre controles

	// flag para alternar quais motores atualizar
	bool		nextRight	  = true;

public:
	PonteH(Motor* right, Motor* left) : motorRight(right), motorLeft(left)
	{}

	void setup() {
		if (motorRight) motorRight->begin();
		if (motorLeft)  motorLeft->begin();
	}

	void forward() {
		if (!motorRight || !motorLeft) return;
		if (!isMoving || currentMove != MOVEMENT_FORWARD) {
			stop();
			currentMove = MOVEMENT_FORWARD;
			motorRight->forward();
			motorLeft->forward();
			isMoving = true;
			turning_angleZ = 0.0;
			lastUpdate = millis();
			nextRight = true;  // reinicia alternância
		}
	}

	void backward() {
		if (!motorRight || !motorLeft) return;
		if (!isMoving || currentMove != MOVEMENT_BACKWARDS) {
			stop();
			currentMove = MOVEMENT_BACKWARDS;
			motorRight->backward();
			motorLeft->backward();
			isMoving = true;
			turning_angleZ = 0.0;
			lastUpdate = millis();
			nextRight = true;
		}
	}

	void turnLeft() {
		if (!motorRight || !motorLeft) return;
		if (!isMoving || currentMove != MOVEMENT_TURN_LEFT) {
			stop();
			currentMove = MOVEMENT_TURN_LEFT;
			motorRight->forward();
			motorLeft->backward();
			isMoving = true;
			turning_angleZ = 0.0;
			lastUpdate = millis();
			nextRight = true;
		}
	}

	void turnRight() {
		if (!motorRight || !motorLeft) return;
		if (!isMoving || currentMove != MOVEMENT_TURN_RIGHT) {
			stop();
			currentMove = MOVEMENT_TURN_RIGHT;
			motorRight->backward();
			motorLeft->forward();
			isMoving = true;
			turning_angleZ = 0.0;
			lastUpdate = millis();
			nextRight = true;
		}
	}

	void stop() {
		if (!motorRight || !motorLeft) return;
		motorRight->stop();
		motorLeft->stop();
		isMoving = false;
		currentMove = MOVEMENT_STOPPED;
	}

	bool isStopped() const {
		return !isMoving || (currentMove == MOVEMENT_STOPPED); // Vai que eu esqueci de setar como parado em uma das duas, ai... Agora ta seguro :)
	}

	// Deve ser chamado dentro de loop()
	void loop(VL53L0X* front_dist_sensor, MPU6050* mpu_sensor) {
		if (!isMoving || !motorRight || !motorLeft ||
			!front_dist_sensor || !mpu_sensor) {
			return;
		}

		unsigned long now = millis();
		if (now - lastUpdate < controlInterval) {
			return;
		}
		double deltaTime = (now - lastUpdate) / 1000.0;  // em segundos
		lastUpdate = now;

		// Função auxiliar para chamar update() alternado
		auto doUpdate = [&](Motor* m, double gyroCorr = 0.0) {
			if (nextRight && m == motorRight)	  m->update(gyroCorr);
			else if (!nextRight && m == motorLeft) m->update(gyroCorr);
		};

		switch (currentMove) {
			case MOVEMENT_FORWARD: {
				int d = front_dist_sensor->loop();
				if (d < 100) {
					stop();
					#ifdef DEBUG_PRINTS
						Serial.println("Parando por obstáculo!");
					#endif
					return;
				}
				double gz = mpu_sensor->getGyroscopeZ();
				// alterna update entre Right e Left
				doUpdate(motorRight, -gz);
				doUpdate(motorLeft,   gz);
				break;
			}
			case MOVEMENT_BACKWARDS: {
				double gz = mpu_sensor->getGyroscopeZ();
				doUpdate(motorRight,  gz);
				doUpdate(motorLeft,  -gz);
				break;
			}
			case MOVEMENT_TURN_LEFT:
			case MOVEMENT_TURN_RIGHT: {
				double gz = mpu_sensor->getGyroscopeZ();
				// acumula ângulo em graus
				turning_angleZ += gz * deltaTime;
				#ifdef DEBUG_PRINTS
					Serial.print("[PonteH] Turning Angle Z: ");
					Serial.print(turning_angleZ); Serial.printf(" on deltaTime: %f\n", deltaTime);
				#endif
				if (fabs(turning_angleZ) > 90.0) {
					stop();
					#ifdef DEBUG_PRINTS
						Serial.println("Parando por ângulo de giro excessivo!");
					#endif
					return;
				}
				// mantém direção definida e alterna update
				doUpdate(motorRight);
				doUpdate(motorLeft);
				break;
			}
			default:
				break;
		}

		// alterna para a próxima chamada
		nextRight = !nextRight;
	}
};

void ConnectToWiFi(){
	WiFi.begin(ssid, password);
	#ifdef DEBUG_PRINTS
		Serial.print("Conectando ao WiFi -> ");
		Serial.print(ssid);
	#endif
	while (WiFi.status() != WL_CONNECTED) {
		#ifdef DEBUG_PRINTS
			Serial.print(".");
		#endif
		delay(500);
	}
	#ifdef DEBUG_PRINTS
		Serial.println(" WiFi conectado!");
		Serial.print("Endereco IP: ");
		Serial.println(WiFi.localIP());
	#endif
}
// ——————— Sensores ———————
VL53L0X *sensor = new VL53L0X();	// VL53L0X no I²C (SDA=21, SCL=22)
MPU6050 *sensorMPU = new MPU6050();	// MPU6050 no mesmo barramento I²C

// ——————— Encoders ———————
// Motor Direito
// Encoder *encoderD = new Encoder(27, 26);  // CH A=26, CH B=27
Encoder *encoderD = new Encoder(15, 4);  // CH A=17, CH B=16
// Motor Esquerdo
// Encoder *encoderE = new Encoder(35, 34);  // CH A=35, CH B=34
Encoder *encoderE = new Encoder(16, 17);  // CH A=19, CH B=18

// ——————— Motores com PID ———————
// Motor Direito  → IN1=12, IN2=13, PWM=14
Motor *motorDireito  = new Motor( 12, 13, 32, encoderD, intentKp, intentKi, intentKd );
// Motor Esquerdo → IN1=33, IN2=25, PWM=32
Motor *motorEsquerdo = new Motor( 26, 25, 33, encoderE, intentKp, intentKi, intentKd );

// ——————— Ponte H (drive de 2 motores) ———————
PonteH *ponte = new PonteH(motorDireito, motorEsquerdo);

// ——————— Outros ———————
// LED da carroceria (MQTT)
LED led_carro(2);
// Gerenciador de energia
PowerManager powerManager;

// void http_stop_carro(AsyncWebServerRequest *request) {
void http_stop_carro() {
	ponte->stop();
	lastReading = millis();
	// request->send(200, "application/json", "{\"status\":\"stopped\"}");
	server.send(200, "application/json", "{\"status\":\"stopped\"}");
}

// void http_handle_forward(AsyncWebServerRequest *request) {
void http_handle_forward() {
	ponte->forward();
	lastReading = millis();
	// request->send(200, "application/json", "{\"status\":\"moving forward\"}");
	server.send(200, "application/json", "{\"status\":\"moving forward\"}");
}

// void http_handle_backward(AsyncWebServerRequest *request) {
void http_handle_backward() {
	ponte->backward();
	lastReading = millis();
	// request->send(200, "application/json", "{\"status\":\"moving backward\"}");
	server.send(200, "application/json", "{\"status\":\"moving backward\"}");
}

// void http_handle_turn_left(AsyncWebServerRequest *request) {
void http_handle_turn_left() {
	ponte->turnLeft();
	lastReading = millis();
	// request->send(200, "application/json", "{\"status\":\"turning left\"}");
	server.send(200, "application/json", "{\"status\":\"turning left\"}");
}

// void http_handle_turn_right(AsyncWebServerRequest *request) {
void http_handle_turn_right() {
	ponte->turnRight();
	lastReading = millis();
	// request->send(200, "application/json", "{\"status\":\"turning right\"}");
	server.send(200, "application/json", "{\"status\":\"turning right\"}");
}

// void http_handle_test(AsyncWebServerRequest *request) {
void http_handle_test() {
	String html = "<html><head>";
	html += "<meta name=\"viewport\" content=\"width=device-width, initial-scale=1\">";
	html += "<style>";
	html += "body { font-family: Arial, sans-serif; }";
	html += "h1 { color: #333; }";
	html += "button { padding: 10px 20px; font-size: 16px; margin: 5px; }";
	html += "button:hover { background-color: #ddd; }";
	html += "div { margin-top: 20px; }";
	html += "</style>";
	html += "<title>Manual Control</title>";
	html += "</head><body>";
	html += "<h1>Manual Control</h1>";
	html += "<button onclick=\"fetchURL('/forward')\">Forward</button>";
	html += "<button onclick=\"fetchURL('/backward')\">Backward</button>";
	html += "<button onclick=\"fetchURL('/turn_left')\">Turn Left</button>";
	html += "<button onclick=\"fetchURL('/turn_right')\">Turn Right</button>";
	html += "<button onclick=\"fetchURL('/stop')\">Stop</button>";
	html += "<button onclick=\"fetchURL('/test')\">Test</button>";
	html += "<button onclick=\"fetchURL('/data')\">Data</button>";
	html += "<div id=\"data\"></div>";
	html += "<script>";
	html += "function fetchURL(url) {";
	html += " fetch(url).then(response => response.json()).then(data => {";
	html += "  console.log(data);";
	html += "  document.getElementById('data').innerText = JSON.stringify(data);";
	html += " });";
	html += "}";
	html += "</script>";
	html += "</body></html>";
	lastReading = millis();
	// request->send(200, "text/html", html);
	server.send(200, "text/html", html);
}

// void handleData(AsyncWebServerRequest *request) {
void handleData() {
	String json = "{";

	// Dados do MPU6050
	json += "\"sensorMPU\":{";
		json += "\"accX\":" + String(sensorMPU->getAccelerometerX()) + ",";
		json += "\"accY\":" + String(sensorMPU->getAccelerometerY()) + ",";
		json += "\"accZ\":" + String(sensorMPU->getAccelerometerZ()) + ",";
		json += "\"gyroX\":" + String(sensorMPU->getGyroscopeX()) + ",";
		json += "\"gyroY\":" + String(sensorMPU->getGyroscopeY()) + ",";
		json += "\"gyroZ\":" + String(sensorMPU->getGyroscopeZ()) + ",";
		json += "\"temp\":"  + String(sensorMPU->getTemperatureC());
	json += "},";

	// Distância VL53L0X
	json += "\"sensorVL53L0X\":{";
		json += "\"distance\":" + String(sensor->loop());
	json += "},";

	// Status do LED do carrinho
	json += "\"led_carro\":{";
		json += "\"status\":\"" + String(led_carro.isOn() ? "on" : "off") + "\"";
	json += "},";

	// Modo de energia
	json += "\"power_manager\":{";
		json += "\"power_mode\":\"" + String(powerManager.isPowerSaving() ? "saving" : "normal") + "\"";
	json += "},";

	// Motor Direito
	json += "\"direcaoD\":\"" + String(encoderD->isClockwise() ? "frente" : "tras") + "\",";
	json += "\"rpmD\":" + String(encoderD->getRPM()) + ",";

	// Motor Esquerdo
	json += "\"direcaoE\":\"" + String(encoderE->isClockwise() ? "frente" : "tras") + "\",";
	json += "\"rpmE\":" + String(encoderE->getRPM());

	json += "}";

	lastReading = millis();

	// request->send(200, "application/json", json);
	server.send(200, "application/json", json);
}
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
void loop() {
	if (WiFi.status() != WL_CONNECTED) {
		#ifdef DEBUG_PRINTS
			Serial.println("WiFi desconectado, tentando reconectar...");
		#endif
		ponte->stop();
		ConnectToWiFi();
		return;
	}

	server.handleClient();

	unsigned long now = millis();
	if (now - lastLoopTime >= loopInterval) {
		lastLoopTime = now;

		// Atualiza sensores
		sensorMPU->loop();

		// Atualiza ponte H e motores
		ponte->loop(sensor, sensorMPU);

		lastReading = millis();
	}
}

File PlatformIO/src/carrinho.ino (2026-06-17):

#define DEBUG_PRINTS
struct SensorSnapshot;

#include <Wire.h>
#include <Arduino.h>
#include <math.h>
#include <ArduinoJson.h>
#include "RobotConfig.h"

#include <WiFi.h>
#include <SPIFFS.h>

#include "LED.h"
#include "MediaMovel.h"
#include "Map.h"
#include "PoseEKF.h"
#include "BrownoutLogger.h"
#include "ExperimentLogger.h"


const char* ssid = "Canguru";
const char* password = "VamoPula";
const double intentKp = 1.0;
const double intentKi = 0.5;
const double intentKd = 0.0;

static const unsigned int GRID_WIDTH = 7;   // Mapa binário 7x7 para os experimentos do TCC.
static const unsigned int GRID_HEIGHT = 7;  // Bordas ocupadas (1) e área interna livre (0).
static const int ENCODER_TEETH = 10;

static constexpr float GRID_CELL_SIZE_M = 0.30f; // Cada célula do TCC representa 30 cm x 30 cm no mundo real.
static constexpr float GRID_CELL_SIZE_CM = GRID_CELL_SIZE_M * 100.0f;

static constexpr float CELL_TARGET_TOLERANCE_M = 0.015f; // Tolerância de 1,5 cm para encerrar o avanço da célula.
static constexpr float CELL_HEADING_TOLERANCE_RAD = 2.0f * (M_PI / 180.0f); // Erro angular aceitável após cada célula.

static constexpr double TURN_ENCODER_SCALE = 0.50;

static constexpr double TURN_MAX_RAW_DELTA_DEG_PER_SEC = 600.0;
static constexpr double TURN_MAX_RAW_DELTA_DEG_FLOOR = 35.0;
static constexpr double TURN_MAX_REVERSE_DELTA_DEG = 8.0;

static constexpr double QMC_HEADING_MAX_INNOVATION_DEG = 25.0; // QMC só corrige frente/ré se não der salto absurdo.

static constexpr double EKF_MAX_ENCODER_DELTA_TICKS_PER_LOOP = 18.0; // trava pulsos impossíveis antes do EKF.

static constexpr double GYRO_Z_LEFT_TURN_SIGN = -1.0; // QMC5883L montado com eixo Z invertido para curvas à esquerda.
static constexpr double GYRO_Z_RIGHT_TURN_SIGN = 1.0; // Sinal usado para transformar giro à direita em progresso angular positivo.

static constexpr float ODOM_WHEEL_RADIUS_M = 0.0325f; // Mesmo raio usado no PoseEKF, necessário para medir cada célula pelos encoders.
static constexpr float ODOM_TICKS_PER_REV = 20.0f; // Mesmo valor usado no PoseEKF para converter ticks em distância.
static constexpr float ODOM_WHEEL_BASE_M = 0.1400f; // Distância entre rodas usada para estimar giro por encoder.

static constexpr float CELL_OVERRUN_ABORT_FACTOR = 1.80f; // Uma célula acima de 180% do alvo é considerada falha de odometria/controle.
static constexpr int FRONT_OBSTACLE_REPLAN_MM = 220; // Distância frontal usada para marcar obstáculo e replanejar.
static constexpr unsigned long CELL_MAX_TIME_MS = 6500; // Timeout de segurança por célula de 30 cm.

static const size_t PATH_BUFFER_SIZE = 64;
static const unsigned int MAP_VIEW_WIDTH = GRID_WIDTH;
static const unsigned int MAP_VIEW_HEIGHT = GRID_HEIGHT;

#include "WebInterface.h"

#pragma region Funções Auxiliares

static double clamp(double value, double min, double max) {
	return (value < min) ? min : (value > max) ? max : value;
}

static float normalizeSignedAngleGlobal(float angleRad) {
	while (angleRad > M_PI) angleRad -= 2.0f * M_PI;
	while (angleRad < -M_PI) angleRad += 2.0f * M_PI;
	return angleRad;
}

static void webLog(const String& msg) {
	#ifdef DEBUG_PRINTS
		Serial.print(msg);
	#endif
	WebInterface::getInstance().log(msg);
}

static void webLog(const char* msg) {
	#ifdef DEBUG_PRINTS
		Serial.print(msg);
	#endif
	WebInterface::getInstance().log(msg);
}

#include "VL53L0X.h"
#include "QMC5883L_Custom.h"

#include "Encoder.h"
#include "PID.h"
#include "Motor.h"

#pragma region "Ponte H e controle"

enum Movement {
	MOVEMENT_FORWARD,
	MOVEMENT_BACKWARDS,
	MOVEMENT_TURN_LEFT,
	MOVEMENT_TURN_RIGHT,
	MOVEMENT_STOPPED
};
class PonteH {
private:
	Motor*	  motorRight;
	Motor*	  motorLeft;
	Movement	currentMove	= MOVEMENT_STOPPED;
	bool		isMoving	   = false;
	unsigned long lastUpdate   = 0;
	unsigned long lastSocketUpdate = 0;
	static const unsigned long controlInterval = 100; // ms entre controles
	unsigned long turnStartedAt = 0;
	unsigned long turnTimeoutMs = 4000;

	static constexpr double turnToleranceRad = 2.0 * (M_PI / 180.0);      // alvo: erro < 2 graus
	static constexpr double turnFineThresholdRad = 15.0 * (M_PI / 180.0); // troca coarse -> fine

	// flag para alternar quais motores atualizar
	double targetHeading = 0.0;
	double turnTargetRad = 0.0;
	int turnDirectionSign = 0; // +1 = esquerda, -1 = direita
	long turnStartLeftRawTicks = 0;
	long turnStartRightRawTicks = 0;
	double turnFilteredProgressRad = 0.0;
	double turnLastRawProgressRad = 0.0;
	unsigned int turnRejectedSpikeCount = 0;

	PID pidGyro = PID(0.1, 0.0, 0.0, controlInterval / 1000.0); // Kp, Ki, Kd para magnetômetro
	PID pidTurn = PID(0.0, 0.0, 0.0, controlInterval / 1000.0); // mantido por compatibilidade; giro agora fecha por encoder

	PID pidCellHeading = PID(2.4, 0.0, 0.18, controlInterval / 1000.0); // correção angular contínua por célula

	static double normalizeAngle(double angle) {
		angle = fmod(angle, 2 * M_PI);
		if (angle < 0.0) {
			angle += 2 * M_PI;
		}
		return angle;
	}

	static double ticksToDistanceAbs(long ticks) {
		return fabs((double)ticks) / (double)ODOM_TICKS_PER_REV * (2.0 * M_PI * (double)ODOM_WHEEL_RADIUS_M);
	}

		double getRawEncoderTurnProgressRad() const {
			if (!motorRight || !motorLeft || turnDirectionSign == 0) return 0.0;

			const long leftDelta = getRawLeftEncoderTicks() - turnStartLeftRawTicks;
			const long rightDelta = getRawRightEncoderTicks() - turnStartRightRawTicks;

			const double leftDist = ticksToDistanceAbs(leftDelta);
			const double rightDist = ticksToDistanceAbs(rightDelta);
			const double avgWheelArc = (leftDist + rightDist) * 0.5;

			return turnDirectionSign * ((2.0 * avgWheelArc) / (double)ODOM_WHEEL_BASE_M);
		}

		double getEncoderTurnProgressRad() const {
			return getRawEncoderTurnProgressRad() * TURN_ENCODER_SCALE;
		}

		double updateFilteredEncoderTurnProgressRad(double rawProgressRad, double deltaTime) {
			if (turnDirectionSign == 0) return 0.0;

			double deltaRaw = rawProgressRad - turnLastRawProgressRad;
			turnLastRawProgressRad = rawProgressRad;

			const double dt = deltaTime > 0.001 ? deltaTime : (controlInterval / 1000.0);
			const double maxStepDeg = max(TURN_MAX_RAW_DELTA_DEG_FLOOR, TURN_MAX_RAW_DELTA_DEG_PER_SEC * dt);
			const double deltaRawDeg = deltaRaw * (180.0 / M_PI);

			// Se o delta veio contra o sentido comandado, quase sempre é ruído/rollback de encoder.
			if ((deltaRaw * turnDirectionSign) < -(TURN_MAX_REVERSE_DELTA_DEG * M_PI / 180.0)) {
				turnRejectedSpikeCount++;
				webLog("[PonteH] Pulso reverso de encoder ignorado durante giro: delta_raw=" + String(deltaRawDeg, 2) + " deg\n");
				return turnFilteredProgressRad;
			}
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

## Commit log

2025-04-14 add: Some ESP32 usefull stuff
2025-04-21 add: ESP32 Motor encoder, MPU-6050, improved motor class and PonteH class to fit the Encoders, add webserver for dev purpouse [Manual Control]
2025-04-25 Add: Power Management Code & some minor changes
2025-05-07 feat: Attempt to fix PID & Motor control
    [carrinho.ino]
2025-06-27 add: Platformio Version code
    [ESP32_Boards.fzz, Projeto.fzz, l298n-arduino.fzz]
2025-07-03 add: Images for sensors for the text
2025-10-29 Update sensor error handling and port configuration
    Added LED indication for VL53L0X sensor error in VL53L0X.cpp. Changed upload and monitor ports to COM11 in platformio.ini. Corrected motor control logic in carrinho.ino to fix gyro direction. Updated Para_Ver.txt with reordered and renumbered video links.
    [carrinho.ino]
2026-02-10 Add Monografia template and assets
    Add _Monografia directory containing an abnTeX2-based monograph template and supporting assets: class and style files (abntex2.cls, .sty, .bst), sample monografia_bcc.tex and generated PDF, reference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
2026-02-10 Set upload and monitor ports to COM7
    Update PlatformIO/platformio.ini to change upload_port and monitor_port from COM11 to COM7. This adjusts the serial port configuration for the ESP32 development board so uploads and serial monitoring use the correct host port.
2026-03-06 Revamp dashboard UI, sensors and controls
    Redesign dashboard layout and controls: adjust container sizing, card layout and typography; add fixed sensor display components for gyroscope and accelerometer (per-axis values) with monospaced numeric styling; replace previous simple button list with a 3x3 D-pad grid and styled stop button. JavaScript updates: split PID counters into counterD/counterE, format numeric sensor output (toFixed), support sensor data from both HTTP (MPU6050) and WebSocket (gyro/accel) payloads, hide controls when WebSocket unavailable, simplify and clarify connection status messages, add reconnect delay logic, and remove some debug logs. Overall goal: improve readability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
2026-03-06 Fix motor turn directions and add accel
    Swap motor forward/backward calls for TURN_LEFT and TURN_RIGHT so left/right turning behavior is correct (motorRight and motorLeft directions inverted). Also add accelerometer telemetry by populating accel.x, accel.y, accel.z with sensorMPU->getAccelerometerX/Y/Z for inclusion in the JSON report.
    [carrinho.ino]
2026-03-11 Add PlatformIO project patterns (PATTERNS.md)
    Add PlatformIO/PATTERNS.md (Portuguese) documenting recommended project structure, class design, coding conventions, error/security handling, memory and performance tips, SPIFFS persistence guidelines, pathfinding and loop-control patterns, testability practices, and a PR checklist for the ESP32 + Arduino cart firmware. Aims to improve consistency, performance and safety across modules and provide a shared reference for developers.
2026-03-11 Add Mapping library with Map class
    Introduce a new Mapping library (Map.h, Map.cpp) and README. Implements a compact, bit-packed grid map for ESP32/Arduino with SPIFFS persistence and an A* pathfinder. Features include: creation/resiz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
2026-03-11 Add Odometry lib and encoder total tick APIs
    Add new Odometry library (Odometry.cpp/h) implementing pose tracking, tick-to-distance conversion, map attachment and incremental updates based on encoder ticks; includes calibration constants (wheel radius, ticks/rev, wheel base) and map grid conversion helpers. Enhance Encoder (Encoder.cpp/h) to maintain total tick counters, initialize them, and increment them in pulse handlers; add resetTotal(), getTotalTicks(), getTotalRevolutions(), and hasCompletedFullTurn() with interrupt-safe access and input validation. These changes enable long-term distance/revolution tracking and provide odometry-based pose estimation for mapping.
2026-03-11 Add odometry telemetry, UI and refactors
    Add odometry support and richer telemetry, UI elements and assorted refactors/fixes.
    Changes include:
    - UI: dashboard.html updated to show turns, full-turn flags and a new Odometria card (x,y,theta,map coords).
    - Telemetry: sendTelemetryFrame() added to build/emit JSON over WebSocket including gyro/accel, temperature, distance, motor info (rpm, pidOutput, ticks, turns, fullTurn) and odometry (x,y,theta,mapX,mapY). WebSocket send uses carSocket.textAll.
    - New modules/usage: includes Map and Odometry objects; robot map/odometry initialized and updated in loop; encoder-based revolution/tick reporting (ENCODER_TEETH constant).
    - Networking: ConnectToWiFi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
    [carrinho.ino]
2026-03-11 Add PlatformIO README with project next steps
    Add PlatformIO/README.md containing detailed next-step recommendations for the robot project. The document compiles professor and LLM suggestions across four areas: 1) power and stability (battery monitoring, use of a dedicated 5V regulator, ADC divider), 2) wheel control and odometry (PID tuning, caster wheel, magnetometer, open-loop motor characterization), 3) high-level navigation commands (turn/drive primitives, FSM, control functions), and 4) mapping and localization (grid map, A* planning, ground markers for odometry correction). Intended to guide hardware/firmware changes, tests, and the write-up of academic sections and schematics.
2026-03-14 Separando Output do PID PDW para manter o padrão da unidade
    Return the clamped PID output from compute(), and add a new PID::scaleToPWM(float) method to map the PID output range (bottom_floor..top_celing) to a 0–255 PWM value. The scaler guards against zero/negative range to avoid division by zero. PID.h updated to declare the new method.
2026-03-14 Centralize M_PI definition
    Remove duplicate/incorrect M_PI definitions from Encoder.cpp, Encoder.h and Odometry.h and add a single guarded #define M_PI in carrinho.ino. This eliminates multiple global/variable definitions acro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
2026-03-14 Refactor WebSocket handler and HTTP endpoints
    Pass the AsyncWebSocketClient to handleCar and disable a duplicate webLog call. Remove several HTTP control handlers and the test page (/forward, /backward, /turn_left, /turn_right, /stop, /test) and their functions. Reorder initialization: move ConnectToWiFi, mDNS start, prepare_http_server and init_ota to after SPIFFS.begin() to ensure SPIFFS is mounted before starting network/HTTP/OTA services. Overall cleanup to centralize command handling via WebSocket and avoid serving routes before SPIFFS is ready.
    [carrinho.ino]
2026-03-14 Refactor naming and improve turning control
    Renamed variables and methods to consistent camelCase (e.g. last_think -> lastThink, gyro_error -> gyroError, turning_angleZ -> turningAngleZ, pid_gyro -> pidGyro) and updated parameter names for clarity (front_dist_sensor -> frontDistSensor, mpu_sensor -> mpuSensor).
    Enhanced Motor.update to accept gyro compensation, convert PID RPM output to PWM, and tighten debug logging. Added a dedicated pidTurn controller and turnLimitRad to manage turning targets, plus normalizeAngle and _fixTurning helpers for angle wrapping.
    turnLeft/turnRight now accept a degree parameter (default 90°), reset turn PID on start, and set normalized turn limits. Turning l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
    [carrinho.ino]
2026-03-14 Adjust sensor smoothing and turning control
    Reduce moving average window for gyro and accel from 3 to 1 to make readings more responsive. Initialize turnLimitRad explicitly to 0.0 and reset it in the stop routine. Compute turnCorrection earlier, include it in Serial and web logs, and use a 5° (in radians) threshold to stop when close to target. Call _fixTurning() after stopping for angle limit and pass turnCorrection to doUpdate (inverting sign for the left motor) so motor speeds are adjusted for smoother turns. Minor formatting/logging tweaks included.
    [carrinho.ino]
2026-03-14 Add ESP Carrinho registry log (2026-03-14)
    Add PlatformIO/Registry/logs-2026-03-14T21-04-39-592Z.txt containing runtime logs for an ESP32 session. The file records ESP32 connection status, WebSocket client connect/disconnect events, motor state and RPM/PWM/encoder/gyro readings, PonteH steering angles and turn corrections, and high-level vehicle state messages — useful for debugging motor control and steering behavior.
2026-03-18 Refactor motor control and turning logic; add auxiliary functions and improve PID tuning
2026-04-30 Add UnificadoV2 ESP32 robot firmware
    Introduce UnificadoV2 firmware and web UI for ESP32 autonomous mobile robot. Adds RobotConfig, core source (main.cpp, SharedTypes), PlatformIO project file, A* planner, DriveBase, EKF, Encoder, GridM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
2026-05-06 Refactor and enhance code documentation across multiple modules
    - Updated RobotConfig.h with new manual linear speed and turn speed values.
    - Enhanced AStarPlanner.h with detailed method documentation for better clarity.
    - Modified DriveBase.cpp and DriveBase.h to include heading control and improved comments.
    - Improved EKF.h, Encoder.h, GridMap.h, ImuSensor.h, MotorDriver.h, PID.h, PowerManager.h, PurePursuit.h, ToFSensor.h, and WebPortal.h with comprehensive method documentation.
    - Ensured consistent formatting and improved readability throughout the codebase.
2026-06-02 Add PlatformIO project and TCC firmware
    Introduce a complete PlatformIO project for the ESP32 TCC robot: adds src (carrinho.ino, RobotConfig), platformio.ini, lib modules (Motor, Encoder, PID, PoseEKF, Mapping, MPU6050, VL53L0X, WebInterface, ExperimentLogger, BrownoutLogger, etc.), data/SPIFFS web UI files (dashboard, monitor, brownout), an upload_with_spiffs helper, and a .gitignore for the PlatformIO workspace. Also add documentation (ARCHITECTURE.md, INSTALL.md, CALIBRATION.md, DEBUG_FIXES.md, EXPERIMENTS.md, PINOUTS.md, RESULTS.md) and update README to describe cell-based navigation, sensor threads, A* replan behavior and logging. Remove an old registry log file. This commit sets up the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
    [carrinho.ino]
2026-06-16 Add log file for ESP32 connection and navigation process
    - Documented the connection process to the ESP32.
    - Logged detailed encoder turn calibration and navigation steps using A* pathfinding.
    - Included information on heading adjustments and ignored spikes during navigation.
    - Captured the completion of cell navigation with distance measurements.
2026-06-30 Protoboard Fritzing v2
    [Protoboard.fzz]
